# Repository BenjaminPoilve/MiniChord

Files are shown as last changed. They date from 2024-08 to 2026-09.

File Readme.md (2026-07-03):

# minichord 

This repository contains the source file both for the minichord itself and its documentation. 

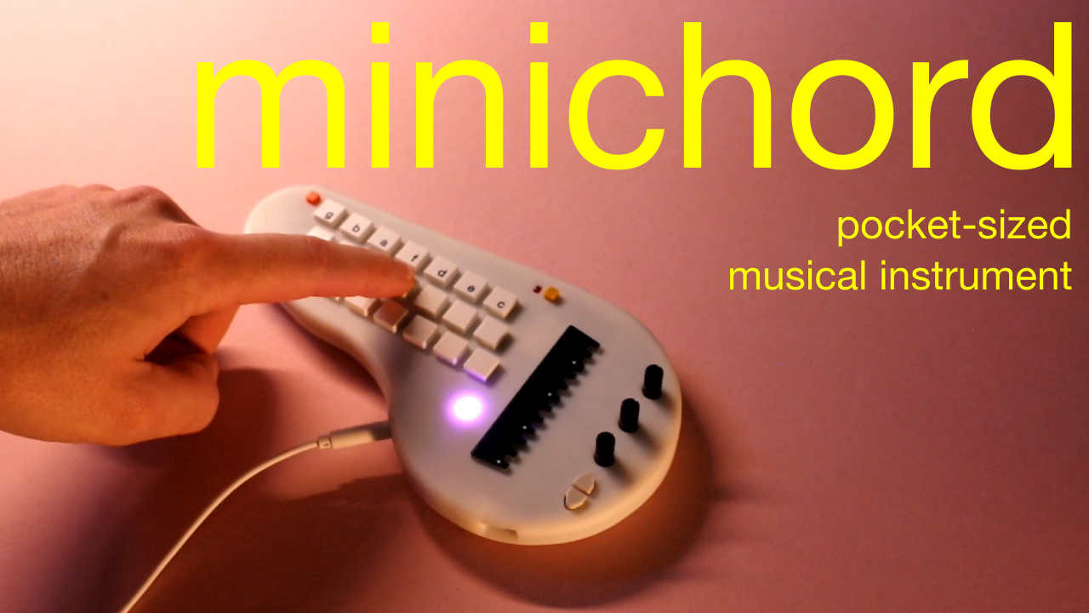
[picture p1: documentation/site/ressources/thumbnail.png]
Watch the video (https://www.youtube.com/watch?v=66Gu4NNnHgA)


To discuss the state of the project, features or share music, please head to the [minichord forum](https://minichord.discourse.group/categories).

## Documentation 

The best way to get to know this project is to visit the [minichord website](https://minichord.com/) which contains the documentation of the project. 

In particular it contains:

- the [user manual of the minichord](https://minichord.com/user_manual/)
- the [assembly guide of the minichord](https://minichord.com/assembly/)

This documentation is build with mkdocs and the relevant source and build script is available in the [documentation folder](https://github.com/BenjaminPoilve/MiniChord/tree/main/documentation).

## Hardware 

The hardware folder contains the necessary ressources to build a minichord. 

All hardware is provided under a Creative Commons Attribution-NonCommercial 4.0 International Public
License (CC BY-NC 4.0). 

In particular it contains: 

- the [files necessary to manufacture the PCB](https://github.com/BenjaminPoilve/MiniChord/tree/main/hardware/PCB)
- the [full BOM of the project](https://github.com/BenjaminPoilve/MiniChord/tree/main/hardware/BOM)
- the [3D enclosure files](https://github.com/BenjaminPoilve/MiniChord/tree/main/hardware/3D/rendering)
- the [keycap routing files](https://github.com/BenjaminPoilve/MiniChord/tree/main/hardware/graphics)

## Firmware 

The firmware folder contains the project firmware and necessary programming ressources.

All software is provided under a 3-clause BSD License.

In particular it contains: 
- the [Hex firmware](https://github.com/BenjaminPoilve/MiniChord/blob/main/firmware/firmware.hex)
- the full [PlatformIO project](https://github.com/BenjaminPoilve/MiniChord/tree/main/firmware)
- the [minicontrol software](https://github.com/BenjaminPoilve/MiniChord/tree/main/firmware/minicontrol)

## Alternative control platforms

Minichord users have developed some very cool alternative platforms that interface with the minichord. 
- the [minichord Sound Lab](https://minichorddrawn.github.io/minichord-soundlab/#play)
- [Keyandcableco's minicontrol](https://keyandcableco.github.io/minicontrol/)

Make sure to test them as they offer many alternative features!

## Media 

Here is a list of available media related to the project (to be completed) :

- a technical video about [the minicontrol system](https://www.youtube.com/watch?v=h-6qkhU_WoA&t=933s)
- a short [audio demo of selected presets](https://minichord.com/ressources/audio_demo.mp3)
- a [review of the project by Hainbach](https://www.youtube.com/watch?v=zQC3umGRGbM)
- an [interview I gave for the launch of the project with SeeedStudio](https://www.youtube.com/watch?v=swZKdO71dLo)
- a [folder of videos from minichord users](https://github.com/BenjaminPoilve/minichord/tree/main/documentation/docs/ressources/video) 

## Contact 

For any information about the project, don't hesitate to write at info@minichord.com

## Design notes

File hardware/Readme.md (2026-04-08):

# Hardware  

This folder contains the necessary ressources to build a minichord. 

### Electronics

* [Main PCB schematics](https://github.com/BenjaminPoilve/MiniChord/blob/main/hardware/PCB/miniChord_main_PCB/MiniChord.pdf)
* [Main PCB Gerber file](https://github.com/BenjaminPoilve/MiniChord/tree/main/hardware/PCB/miniChord_main_PCB/gerber)
* [Touch zone PCB Gerber file](https://github.com/BenjaminPoilve/minichord/tree/main/hardware/PCB/touch%20zones/default%20touch%20PCB/gerber)
* [Template for custom touch zone](https://github.com/BenjaminPoilve/minichord/tree/main/hardware/PCB/touch%20zones/touch%20kicad%20template)

### BOM

* [Full BOM](https://github.com/BenjaminPoilve/MiniChord/blob/main/hardware/BOM/full_BOM.pdf)

### 3D files

* [Bottom shell](https://github.com/BenjaminPoilve/minichord/blob/main/hardware/3D/rendering/render_v11_bottom.step) 
* [Top shell](https://github.com/BenjaminPoilve/minichord/blob/main/hardware/3D/rendering/render_v11_top.step)

### 2D files 

* [Key engraving](https://github.com/BenjaminPoilve/MiniChord/blob/main/hardware/graphics/key_engraving.svg)

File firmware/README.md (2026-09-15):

# Firmware 

Note to reader: a lot of this firmware has been developed in 45-minute time increment after a day's work, which in part explains that the code quality is not great. Refactoring and making the code cleaner will be a future focus. 

If you are an experimented C/C++ dev, and you whish to help on this project, I might be able to send you pre-production sample of the minichord in exchange for a bit of help. Don't hesitate to reach out to minichord@benjaminpoilve.com .

### Structure 

This folder contains a PlatformIO project for Teensy 4.0. 

In particular the it contains :

- the `src`folder containing the `main.cpp` file, as well as the file defining the USB name of the device, `name.c`
- the `lib` folder containing the librairies for the chips used, the debouncing and the potentiometer logic 
- the `include` folder containing all the Teensy audio architecture definition, as well as the hardware definitions and the `sysex_handler.h`file. 

The next interesting folder is related to the "generator". To be able to simply modify parameters related to sound synthesis and have a coherent firmware and control software, those parameters are defined in a [parameters.json file](https://github.com/BenjaminPoilve/MiniChord/blob/main/firmware/generator/parameters.json). By using the generation script, both the interface and necessary firmware file are generated. Note that the interface will be included in the minichord website by using the `build_site.sh` script in the documentation folder. 

The resulting fimware itself is present at the root of the project : [firmware.hex](https://github.com/BenjaminPoilve/MiniChord/blob/main/firmware/firmware.hex).

### Usage 

If you want to set-up a PlatformIO environnement for Teensy, please follow the tutorial for PlatformIO Teensy usage [available here](https://forum.pjrc.com/index.php?threads/tutorial-how-to-use-platformio-visual-code-studio-for-teensy.66674/)

Once the project is set-up, you can modify, compile and upload the code directly from VSCode. 

To use the generator, set-up a venv in the generator directory using `python3 -m venv .venv`. Then enter the venv by using `source venv/bin/activate`. 

Once in the venv, install the necessary packages by using `pip3 install -r requirements.txt`. 

Generation can then simply be done by running the `generate.py`script: `python3 generate.py`.

### USB descriptor customisation

The device uses the stock `USB_MIDI16_AUDIO_SERIAL` USB type of the Teensy core, with two changes: it advertises 2 MIDI cables instead of 16, and it reports `minichord` as manufacturer and product name.

The USB audio recording tap in `include/audio_definition.h` is guarded by `#ifdef AUDIO_INTERFACE`, so building against a USB type without audio interfaces still works without further edits.

Both are done from within the project, so no file of the `framework-arduinoteensy` package has to be touched:

- the names are set in [src/name.c](src/name.c), which overrides the (weakly defined) `usb_string_manufacturer_name` and `usb_string_product_name` descriptors of the core;
- the cable count is set in [include/usb_desc_override.h](include/usb_desc_override.h), which `platformio.ini` force-includes in front of every translation unit with `-include`. Because the core's `usb_desc.h` uses `#pragma once`, reading it from that header first means the core sources later get a no-op include and keep our value of `MIDI_NUM_CABLES`.

Earlier versions of this project instead asked for a manual edit of `usb_desc.h` in `~/.platformio/packages/framework-arduinoteensy/cores/teensy4`. That is no longer needed, and if you patched that file previously you can restore it to its original content.

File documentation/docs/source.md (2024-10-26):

# **Software** 

> All software is provided under a 3-clause BSD License

* [minicontrol software](https://github.com/BenjaminPoilve/MiniChord/tree/main/firmware/minicontrol)
* [Hex firmware](https://github.com/BenjaminPoilve/MiniChord/blob/main/firmware/firmware.hex)
* [PlatformIO project](https://github.com/BenjaminPoilve/MiniChord/tree/main/firmware)
* [Tutorial for PlatformIO Teensy usage](https://forum.pjrc.com/index.php?threads/tutorial-how-to-use-platformio-visual-code-studio-for-teensy.66674/)

<hr>

# **Hardware**

> All hardware is provided under a Creative Commons Attribution-NonCommercial 4.0 International Public
License (CC BY-NC 4.0)

## 3D files

* [Bottom shell](https://github.com/BenjaminPoilve/MiniChord/blob/main/hardware/3D/rendering/render_v9_bottom.scad.stl) 
* [Top shell](https://github.com/BenjaminPoilve/MiniChord/blob/main/hardware/3D/rendering/render_v9_top1_5.scad.stl)

## 2D files 

* [Key engraving](https://github.com/BenjaminPoilve/MiniChord/blob/main/hardware/graphics/key_engraving.svg)

## Electronics

* [Full BOM](https://github.com/BenjaminPoilve/MiniChord/blob/main/hardware/BOM/full_BOM.pdf)
* [Main PCB schematics](https://github.com/BenjaminPoilve/MiniChord/blob/main/hardware/PCB/miniChord_main_PCB/MiniChord.pdf)
* [Main PCB Gerber file](https://github.com/BenjaminPoilve/MiniChord/tree/main/hardware/PCB/miniChord_main_PCB/gerber)
* [Touch zone PCB schematics](https://github.com/BenjaminPoilve/MiniChord/blob/main/hardware/PCB/additional%20PCB/touch_zone.pdf)
* [Touch zone PCB Gerber file](https://github.com/BenjaminPoilve/MiniChord/tree/main/hardware/PCB/additional%20PCB/gerber)

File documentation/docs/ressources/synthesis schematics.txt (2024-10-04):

                                                                                            
 Harp section                         ┌ ─ ─ ─ ─ ─ ─ ─ ─ ─ ─ ─ ─ ─ ─ ─ ─ ─ ─ ─ ─ ─ ─ ─ ─ ─ ─ ─ ─
                                     ┌────────────────────────────────────────────────────────┐│ x12
                                    ┌┴───────────────────────────────────────────────────────┐│
┌─────────┐                         │┌────────────────┐                                      │││
│DC signal├────────────────────────▶││filter enveloppe│──────────┐          ┌───────────────┐││
└─────────┘                         │└────────────────┘          └─────────▶│low-pass filter│││├───┐
┌───────────┐   ┌────────────────┐  │┌─────────────────────┐  ┌────────┐ ┌─▶│               │││    │
│vibrato OSC├──▶│vibrato envelope├┬▶││modulated string OSC ├─▶│envelope├─┘  └───────────────┘││┘   │
└───────────┘   └────────────────┘│ │└─────────────────────┘  └────────┘                     ├┘    │
                                  │ └────────────────────────────────────────────────────────┘     │
┌───────────┐   ┌────────────────┐│     
│  bend DC  ├──▶│  bend envelope ├┘  
└───────────┘   └────────────────┘  
                                                                                                   │
┌──────────────────────────────────────────────────────────────────────────────────────────────────┘
│  ┌──────────┐  ┌─────────────┐  ┌─────────────┐  ┌─────┐  ┌────────────┐      ┌──────────┐
├─▶│waveshaper├─▶│ waveshaper  ├┬▶│  delay mix  ├─▶│delay├─▶│filter delay├─┬───▶│effect mix├───────┐
│  └──────────┘  │     mix     ││ │             │  └─────┘  └────────────┘ │ ┌─▶│          │       │
└───────────────▶│             ││ │             │                          │ │  └──────────┘       │
                 └─────────────┘│ └─────────────┘                          │ │                     │
                                │        ▲                                 │ │                     │
                                │        └─────────────────────────────────┘ │                     │
                                └────────────────────────────────────────────┘                     │
┌──────────────────────────────────────────────────────────────────────────────────────────────────┘
│              ┌──────────┐              ┌─────────────┐  ┌──────┐  ┌──────────┐
└─────────────▶│multiplier├─────────────▶│output filter├┬▶│reverb├─▶│reverb mix├─▶ output
┌───────────┐  │          │┌──────────┐  │             ││ └──────┘  │          │
│tremolo OSC├─▶│          ││filter OSC├─▶│             │└──────────▶│          │
└───────────┘  └──────────┘└──────────┘  └─────────────┘            └──────────┘

 Chord section     ┌──────────────────────────────────────────────────────────────────────┐
                  ┌┴─────────────────────────────────────────────────────────────────────┐│ x4
                 ┌┴─────────────────────────────────────────────────────────────────────┐││
                ┌┴─────────────────────────────────────────────────────────────────────┐│││
┌───────────┐   │┌────────────────┐  ┌───────────────┐  ┌─────┐  ┌──────┐  ┌──────────┐││││
│vibrato OSC├─▶ ││vibrato envelope├┬▶│modulated OSC 1├─▶│ mix ├─▶│filter├─▶│multiplier│││││
└───────────┘   │└────────────────┘│ ├───────────────┤  │     │  └──────┘  └──────────┘││││
┌───────────┐   │┌────────────────┐├▶│modulated OSC 2├─▶│     │     ▲           ▲      ││││
│  bend DC  ├─▶ ││vibrato envelope├│ ├───────────────┤  │     │     │           │      ││││────────┐
└───────────┘   │└────────────────┘└▶│modulated OSC 3├─▶│     │     │           │      ││││        │
                │                    └─────────┬─────┤  │     │     │           │      ││││        │
                │                              │noise├─▶│     │     │           │      ││││        │
┌──────────┐    │┌───────────────┐             └─────┘  └─────┘     │           │      ││││        │
│filter OSC├──▶ ││filter envelope├──────────────────────────────────┘           │      ││││        │
└──────────┘    │└───────────────┘                                              │      ││││        │
┌───────────┐   │┌────────────────┐                                             │      ││├┘        │
│tremolo OSC├─▶ ││tremolo envelope├─────────────────────────────────────────────┘      │├┘         │
└───────────┘   │└────────────────┘                                                    ├┘          │
                └──────────────────────────────────────────────────────────────────────┘           │
                                                                                                   │
┌──────────────────────────────────────────────────────────────────────────────────────────────────┘
│  ┌──────────┐  ┌─────────────┐  ┌─────────────┐  ┌─────┐  ┌────────────┐      ┌──────────┐
├─▶│waveshaper├─▶│ waveshaper  ├┬▶│  delay mix  ├─▶│delay├─▶│filter delay├─┬───▶│effect mix├───────┐
│  └──────────┘  │     mix     ││ │             │  └─────┘  └────────────┘ │ ┌─▶│          │       │
└───────────────▶│             ││ │             │                          │ │  └──────────┘       │
                 └─────────────┘│ └─────────────┘                          │ │                     │
                                │        ▲                                 │ │                     │
                                │        └─────────────────────────────────┘ │                     │
                                └────────────────────────────────────────────┘                     │
┌──────────────────────────────────────────────────────────────────────────────────────────────────┘
│  ┌─────────────┐  ┌──────┐  ┌──────────┐
└─▶│output filter├┬▶│reverb├─▶│reverb mix├─▶ output
   │             ││ └──────┘  │          │
   │             │└──────────▶│          │
   └─────────────┘            └──────────┘

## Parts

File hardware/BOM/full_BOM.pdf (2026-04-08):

### Full BOM

Quantity | Part | Type | Link
2 | 1608 10uf capacitor | SMD component
3 | 2012 2.2uf capacitor | SMD component
1 | 6.3x5.7 100uf capacitor | SMD component
1 | 3216 100uf capacitor | SMD component
8 | 1608 100nf capacitor | SMD component
1 | 4x5.4 10uf capacitor | SMD component
2 | 1608 2.2nf capacitor | SMD component
1 | 2012 4.7uf capacitor | SMD component
1 | side mount bicolour led | SMD component
1 | SWPA60 6.8uH inductor | SMD component
1 | 2012 1k resistor | SMD component
1 | 1608 330k resistor | SMD component
1 | 2012 680 resistor | SMD component
2 | 1608 1.8M resistor | SMD component
1 | 1608 220k resistor | SMD component
1 | 1608 1M resistor | SMD component
1 | 2012 2k resistor | SMD component
2 | 2012 2k2 resistor | SMD component
8 | 2012 10k resistor | SMD component
1 | 1608 75k resistor | SMD component
4 | 1608 22 resistor | SMD component
1 | 1608 560 resistor | SMD component
1 | 1608 100 resistor | SMD component
1 | 1608 200 resistor | SMD component
3 | 1608 470 resistor | SMD component
1 | PVQFN TPS61090 | SMD component
1 | SOT-23 MCP73831 | SMD component
1 | SOIC-16 74HC595 | SMD component
1 | TSSOP-20 PCM5102 | SMD component
1 | UQFN-20 MPR121QR2 | SMD component
8 | 1N4148WT | SMD component
1 | Red LED | TH component | Mouser (https://www.mouser.fr/ProductDetail/604-WP169XID)
1 | 5mm RKGB LED | TH component | -
1 | Switched Audio Jack | TH component | Mouser (https://www.mouser.fr/ProductDetail/490-SJ-3566AN)
1 | JST PH 2mm 2pin male angled | TH component | -
1 | 503450 1000mAh battery | other hardware | -
3 | Potentiometer | TH component | Mouser (https://www.mouser.fr/ProductDetail/317-2090F-100K) (note: if we could source a RV09AF-40-15K-B100K instead, it would be better)
4 | Tactile switch 6x6mm | TH component | Mouser (https://www.mouser.fr/ProductDetail/653-B3F-1050)
21 | Tactile switch 12x12mm | TH component | Mouser (https://www.mouser.fr/ProductDetail/653-B3F-4050)
2 | Touch header female | TH component | Mouser (https://www.mouser.fr/ProductDetail/855-M20-7810345R)
2 | Touch header male | TH component | Mouser (https://www.mouser.fr/ProductDetail/855-M20-8760346)
1 | Teensy 4.0 | TH component | PJRC (https://www.pjrc.com/store/teensy40.html)
1 | Teensy headers | TH component | Mouser (https://www.mouser.fr/ProductDetail/Samtec/TSW-132-06-T-S?qs=rU5fayqh%252BE1E2ITYQW/0SQ==)
21 | Tactile switch keycap 9x9 | other hardware | Mouser (https://www.mouser.fr/ProductDetail/653-B32-1260)
2 | Tactile switch keycap key top | other hardware | Mouser (https://www.mouser.fr/ProductDetail/653-B322100)
1 | Tactile switch keycap 4x4 orange | other hardware | Mouser (https://www.mouser.fr/ProductDetail/653-B32-1020)

1

Quantity | Part | Type | Link
1 | Tactile switch keycap 4x4 yellow | other hardware | Mouser (https://www.mouser.fr/ProductDetail/653-B32-1030)
1 | Top shell | other hardware | -
1 | Bottom shell | other hardware | -
1 | Double sided tape | other hardware | -
6 | M2.3x8 self taping screws | other hardware | -
3 | M2.3x6 self taping screws | other hardware | -

2

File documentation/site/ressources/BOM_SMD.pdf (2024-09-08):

### Table 1

ID | Value | Footprint | Quantity
> C1, C2 | 10uf | 1608Metric | 2
> C4, C9, C10 | 2.2uf | 2012Metric | 3
C5 | 100uf | Elec_6.3x5.7 | 1
C6 | 100uf | 3216Metric | 1
> C3, C7, C8, C11-C14, C19 | 100n | 1608Metric | 8
C15 | 10uf | Elec_4x5.4 | 1
> C16, C17 | 2.2nf | 1608Metric | 2
C18 | 4.7uf | 2012Metric | 1
D3 | LED_Dual_AAKK | side led | 1
L1 | 6.8uH | SWPA60xxS | 1
R1 | 1k | 2012Metric | 1
R3 | 330k | 1608Metric | 1
R4 | 680 | 2012Metric | 1
> R2, R5 | 1.8M | 1608Metric | 2
R6 | 220k | 1608Metric | 1
R7 | 1M | 1608Metric | 1
R8 | 2k | 2012Metric | 1
> R9, R10 | 2k2 | 2012Metric | 2
> R11-R14, R16, R38-R40 | 10k | 2012Metric | 8
R15 | 75k | 1608Metric | 1
> R27-R30 | 22 | 1608Metric | 4
R34 | 560 | 1608Metric | 1
R35 | 100 | 1608Metric | 1
R36 | 200 | 1608Metric | 1
> R31, R32, R37 | 470 | 1608Metric | 3
U2 | TPS61090 | PVQFN-N16_EP2.7x2.7mm | 1
U3 | MCP73831-2-OT | SOT-23-5 | 1
U4 | 74HC595 | SOIC-16_3.9x9.9m m_P1.27mm | 1
U5 | PCM5102 | TSSOP-20_4.4x6.5 mm_P0.65mm | 1
U6 | MPR121QR2 | UQFN-20_3x3mm_ P0.4mm | 1

1

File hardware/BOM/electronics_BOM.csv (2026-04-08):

Reference | Value | Link | Footprint | Qty | DNP | Description
C1 | 10uf | https://www.lcsc.com/product-detail/Multilayer-Ceramic-Capacitors-MLCC-SMD-SMT_Samsung-Electro-Mechanics-CL10A106MA8NRNC_C96446.html | Capacitor_SMD:C_0603_1608Metric | 1
C2 | 10uf | https://www.lcsc.com/product-detail/Multilayer-Ceramic-Capacitors-MLCC-SMD-SMT_Samsung-Electro-Mechanics-CL10A106MA8NRNC_C96446.html | Capacitor_SMD:C_0603_1608Metric | 1
C3 | 100n | https://www.lcsc.com/product-detail/Multilayer-Ceramic-Capacitors-MLCC-SMD-SMT_YAGEO-CC0603KRX7R9BB104_C14663.html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 | Capacitor_SMD:C_0603_1608Metric | 1
C4 | 2.2uf | https://www.lcsc.com/product-detail/Multilayer-Ceramic-Capacitors-MLCC-SMD-SMT_Samsung-Electro-Mechanics-CL21A225KBQNNNE_C377773.html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 | Capacitor_SMD:C_0805_2012Metric | 1
C5 | 100uf | https://www.lcsc.com/product-detail/Aluminum-Electrolytic-Capacitors-SMD_Capxon-International-Elec-HV101M6R3E055ETR_C65235.html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 | Capacitor_SMD:CP_Elec_6.3x5.7 | 1
C6 | 100uf | https://www.lcsc.com/product-detail/Multilayer-Ceramic-Capacitors-MLCC-SMD-SMT_Samsung-Electro-Mechanics-CL31A107MQHNNNE_C15008.html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 | Capacitor_SMD:C_1206_3216Metric | 1
C7 | 100n | https://www.lcsc.com/product-detail/Multilayer-Ceramic-Capacitors-MLCC-SMD-SMT_YAGEO-CC0603KRX7R9BB104_C14663.html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 | Capacitor_SMD:C_0603_1608Metric | 1
C8 | 100n | https://www.lcsc.com/product-detail/Multilayer-Ceramic-Capacitors-MLCC-SMD-SMT_YAGEO-CC0603KRX7R9BB104_C14663.html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 | Capacitor_SMD:C_0603_1608Metric | 1
C9 | 2.2uf | https://www.lcsc.com/product-detail/Multilayer-Ceramic-Capacitors-MLCC-SMD-SMT_Samsung-Electro-Mechanics-CL21A225KBQNNNE_C377773.html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 | Capacitor_SMD:C_0805_2012Metric | 1
C10 | 2.2uf | https://www.lcsc.com/product-detail/Multilayer-Ceramic-Capacitors-MLCC-SMD-SMT_Samsung-Electro-Mechanics-CL21A225KBQNNNE_C377773.html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 | Capacitor_SMD:C_0805_2012Metric | 1
C11 | 100n | https://www.lcsc.com/product-detail/Multilayer-Ceramic-Capacitors-MLCC-SMD-SMT_YAGEO-CC0603KRX7R9BB104_C14663.html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 | Capacitor_SMD:C_0603_1608Metric | 1
C12 | 100n | https://www.lcsc.com/product-detail/Multilayer-Ceramic-Capacitors-MLCC-SMD-SMT_YAGEO-CC0603KRX7R9BB104_C14663.html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 | Capacitor_SMD:C_0603_1608Metric | 1
C13 | 100n | https://www.lcsc.com/product-detail/Multilayer-Ceramic-Capacitors-MLCC-SMD-SMT_YAGEO-CC0603KRX7R9BB104_C14663.html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 | Capacitor_SMD:C_0603_1608Metric | 1
C14 | 100n | https://www.lcsc.com/product-detail/Multilayer-Ceramic-Capacitors-MLCC-SMD-SMT_YAGEO-CC0603KRX7R9BB104_C14663.html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 | Capacitor_SMD:C_0603_1608Metric | 1
C15 | 10uf | https://www.lcsc.com/product-detail/Aluminum-Electrolytic-Capacitors-SMD_KNSCHA-126RV0157_C7461288.html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 | Capacitor_SMD:CP_Elec_4x5.4 | 1
C16 | 2.2nf | https://www.lcsc.com/product-detail/Multilayer-Ceramic-Capacitors-MLCC-SMD-SMT_FH-Guangdong-Fenghua-Advanced-Tech-0603B222K500NT_C1604.html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 | Capacitor_SMD:C_0603_1608Metric | 1
C17 | 2.2nf | https://www.lcsc.com/product-detail/Multilayer-Ceramic-Capacitors-MLCC-SMD-SMT_FH-Guangdong-Fenghua-Advanced-Tech-0603B222K500NT_C1604.html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 | Capacitor_SMD:C_0603_1608Metric | 1
C18 | 4.7uf | https://www.lcsc.com/product-detail/Multilayer-Ceramic-Capacitors-MLCC-SMD-SMT_Samsung-Electro-Mechanics-CL21A475KAQNNNE_C1779.html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 | Capacitor_SMD:C_0805_2012Metric | 1
C19 | 100n | https://www.lcsc.com/product-detail/Multilayer-Ceramic-Capacitors-MLCC-SMD-SMT_YAGEO-CC0603KRX7R9BB104_C14663.html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 | Capacitor_SMD:C_0603_1608Metric | 1
D1 | LED | https://www.mouser.fr/ProductDetail/Kingbright/WP169XID?qs=DkZGzo4b%252BTI3yOiggkw3fg%3D%3D | Personnal_Library:WP169XID | 1
D2 | LED_RKGB | https://fr.aliexpress.com/item/1005004567358995.html | Personnal_Library:LED_D5.0mm-4_RGB-cutout | 1
D3 | LED_Dual_AAKK | https://www.lcsc.com/product-detail/LED-Indication-Discrete_Amicc-A-SP1102AR6GHC-A01-2C_C5160724.html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 | Personnal_Library:R_G side led | 1
D4 | 1N4148WT | https://www.lcsc.com/product-detail/Switching-Diodes_hongjiacheng-1N4148WT_C7420320.html?s_z=n_C7420320 | Diode_SMD:D_SOD-523 | 1
D5 | 1N4148WT | https://www.lcsc.com/product-detail/Switching-Diodes_hongjiacheng-1N4148WT_C7420320.html?s_z=n_C7420320 | Diode_SMD:D_SOD-523 | 1
D6 | 1N4148WT | https://www.lcsc.com/product-detail/Switching-Diodes_hongjiacheng-1N4148WT_C7420320.html?s_z=n_C7420320 | Diode_SMD:D_SOD-523 | 1
D7 | 1N4148WT | https://www.lcsc.com/product-detail/Switching-Diodes_hongjiacheng-1N4148WT_C7420320.html?s_z=n_C7420320 | Diode_SMD:D_SOD-523 | 1
D8 | 1N4148WT | https://www.lcsc.com/product-detail/Switching-Diodes_hongjiacheng-1N4148WT_C7420320.html?s_z=n_C7420320 | Diode_SMD:D_SOD-523 | 1
D9 | 1N4148WT | https://www.lcsc.com/product-detail/Switching-Diodes_hongjiacheng-1N4148WT_C7420320.html?s_z=n_C7420320 | Diode_SMD:D_SOD-523 | 1
D10 | 1N4148WT | https://www.lcsc.com/product-detail/Switching-Diodes_hongjiacheng-1N4148WT_C7420320.html?s_z=n_C7420320 | Diode_SMD:D_SOD-523 | 1
D11 | 1N4148WT | https://www.lcsc.com/product-detail/Switching-Diodes_hongjiacheng-1N4148WT_C7420320.html?s_z=n_C7420320 | Diode_SMD:D_SOD-523 | 1
J1 | Conn_02x03_Top_Bottom | https://www.mouser.fr/ProductDetail/Harwin/M20-7810345R?qs=k41KVqW3ymoME5l5QJ2Feg%3D%3D | Personnal_Library:03x02 bottom entry header | 1
J2 | AudioJack_switched | https://www.mouser.fr/ProductDetail/Same-Sky/SJ-3566AN?qs=WyjlAZoYn52HouuVvH6sjg%3D%3D | Personnal_Library:Switched Jack PJ307_3525 | 1
J3 | Conn_01x02 | https://www.lcsc.com/product-detail/Wire-To-Board-Connector_JST-S2B-PH-K-S-LF-SN_C173752.html?s_z=n_JST%20PH | Connector_JST:JST_PH_S2B-PH-K_1x02_P2.00mm_Horizontal | 1
J4 | Conn_02x03_Top_Bottom | https://www.mouser.fr/ProductDetail/Harwin/M20-7810345R?qs=k41KVqW3ymoME5l5QJ2Feg%3D%3D | Personnal_Library:03x02 bottom entry header | 1
L1 | 6.8uH | https://www.digikey.fr/en/products/detail/shenzhen-sunlord-electronics-co-ltd/SWPA6045S6R8MT/14119994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 | Inductor_SMD:L_Sunlord_SWPA60xxS | 1
R1 | 1k | https://www.lcsc.com/product-detail/Chip-Resistor-Surface-Mount_UNI-ROYAL-Uniroyal-Elec-0805W8F1001T5E_C17513.html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 | Resistor_SMD:R_0805_2012Metric | 1
R2 | 1.8M | https://www.lcsc.com/product-detail/Chip-Resistor-Surface-Mount_FOJAN-FRC0603F1804TS_C2933162.html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 | Resistor_SMD:R_0603_1608Metric | 1
R3 | 330k | https://www.lcsc.com/product-detail/Chip-Resistor-Surface-Mount_UNI-ROYAL-Uniroyal-Elec-0603WAF3303T5E_C23137.html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 | Resistor_SMD:R_0603_1608Metric | 1
R4 | 680 | https://www.lcsc.com/product-detail/Chip-Resistor-Surface-Mount_UNI-ROYAL-Uniroyal-Elec-0805W8F6800T5E_C17798.html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 | Resistor_SMD:R_0805_2012Metric | 1
R5 | 1.8M | https://www.lcsc.com/product-detail/Chip-Resistor-Surface-Mount_FOJAN-FRC0603F1804TS_C2933162.html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 | Resistor_SMD:R_0603_1608Metric | 1
R6 | 220k | https://www.lcsc.com/product-detail/Chip-Resistor-Surface-Mount_UNI-ROYAL-Uniroyal-Elec-0603WAF2203T5E_C22961.html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 | Resistor_SMD:R_0603_1608Metric | 1
R7 | 1M | https://www.lcsc.com/product-detail/Chip-Resistor-Surface-Mount_UNI-ROYAL-Uniroyal-Elec-0603WAF1004T5E_C22935.html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 | Resistor_SMD:R_0603_1608Metric | 1
R8 | 2k | https://www.lcsc.com/product-detail/Chip-Resistor-Surface-Mount_UNI-ROYAL-Uniroyal-Elec-0805W8F2001T5E_C17604.html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 | Resistor_SMD:R_0805_2012Metric | 1
R9 | 2k2 | https://www.lcsc.com/product-detail/Chip-Resistor-Surface-Mount_UNI-ROYAL-Uniroyal-Elec-0805W8F2201T5E_C17520.html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 | Resistor_SMD:R_0805_2012Metric | 1
R10 | 2k2 | https://www.lcsc.com/product-detail/Chip-Resistor-Surface-Mount_UNI-ROYAL-Uniroyal-Elec-0805W8F2201T5E_C17520.html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 | Resistor_SMD:R_0805_2012Metric | 1
R11 | 10k | https://www.lcsc.com/product-detail/Chip-Resistor-Surface-Mount_UNI-ROYAL-Uniroyal-Elec-0805W8F1002T5E_C17414.html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 | Resistor_SMD:R_0805_2012Metric | 1
R12 | 10k | https://www.lcsc.com/product-detail/Chip-Resistor-Surface-Mount_UNI-ROYAL-Uniroyal-Elec-0805W8F1002T5E_C17414.html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 | Resistor_SMD:R_0805_2012Metric | 1
R13 | 10k | https://www.lcsc.com/product-detail/Chip-Resistor-Surface-Mount_UNI-ROYAL-Uniroyal-Elec-0805W8F1002T5E_C17414.html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 | Resistor_SMD:R_0805_2012Metric | 1
R14 | 10k | https://www.lcsc.com/product-detail/Chip-Resistor-Surface-Mount_UNI-ROYAL-Uniroyal-Elec-0805W8F1002T5E_C17414.html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 | Resistor_SMD:R_0805_2012Metric | 1
R15 | 75k | https://www.lcsc.com/product-detail/Chip-Resistor-Surface-Mount_UNI-ROYAL-Uniroyal-Elec-0603WAF7502T5E_C23242.html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 | Resistor_SMD:R_0603_1608Metric | 1
R16 | 10k | https://www.lcsc.com/product-detail/Chip-Resistor-Surface-Mount_UNI-ROYAL-Uniroyal-Elec-0805W8F1002T5E_C17414.html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 | Resistor_SMD:R_0805_2012Metric | 1
R27 | 22 | https://www.lcsc.com/product-detail/Chip-Resistor-Surface-Mount_UNI-ROYAL-Uniroyal-Elec-0603WAF220JT5E_C23345.html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 | Resistor_SMD:R_0603_1608Metric | 1
R28 | 22 | https://www.lcsc.com/product-detail/Chip-Resistor-Surface-Mount_UNI-ROYAL-Uniroyal-Elec-0603WAF220JT5E_C23345.html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 | Resistor_SMD:R_0603_1608Metric | 1
R29 | 22 | https://www.lcsc.com/product-detail/Chip-Resistor-Surface-Mount_UNI-ROYAL-Uniroyal-Elec-0603WAF220JT5E_C23345.html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 | Resistor_SMD:R_0603_1608Metric | 1
R30 | 22 | https://www.lcsc.com/product-detail/Chip-Resistor-Surface-Mount_UNI-ROYAL-Uniroyal-Elec-0603WAF220JT5E_C23345.html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 | Resistor_SMD:R_0603_1608Metric | 1
R31 | 470 | https://www.lcsc.com/product-detail/Chip-Resistor-Surface-Mount_UNI-ROYAL-Uniroyal-Elec-0603WAF4700T5E_C23179.html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 | Resistor_SMD:R_0603_1608Metric | 1
R32 | 470 | https://www.lcsc.com/product-detail/Chip-Resistor-Surface-Mount_UNI-ROYAL-Uniroyal-Elec-0603WAF4700T5E_C23179.html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 | Resistor_SMD:R_0603_1608Metric | 1
R34 | 560 | https://www.lcsc.com/product-detail/Chip-Resistor-Surface-Mount_UNI-ROYAL-Uniroyal-Elec-0603WAF5600T5E_C23204.html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 | Resistor_SMD:R_0603_1608Metric | 1
R35 | 100 | https://www.lcsc.com/product-detail/Chip-Resistor-Surface-Mount_UNI-ROYAL-Uniroyal-Elec-0603WAF1000T5E_C22775.html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 | Resistor_SMD:R_0603_1608Metric | 1
R36 | 200 | https://www.lcsc.com/product-detail/Chip-Resistor-Surface-Mount_UNI-ROYAL-Uniroyal-Elec-0603WAF2000T5E_C8218.html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 | Resistor_SMD:R_0603_1608Metric | 1
R37 | 470 | https://www.lcsc.com/product-detail/Chip-Resistor-Surface-Mount_UNI-ROYAL-Uniroyal-Elec-0603WAF4700T5E_C23179.html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 | Resistor_SMD:R_0603_1608Metric | 1
R38 | 10k | https://www.lcsc.com/product-detail/Chip-Resistor-Surface-Mount_UNI-ROYAL-Uniroyal-Elec-0805W8F1002T5E_C17414.html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 | Resistor_SMD:R_0805_2012Metric | 1
R39 | 10k | https://www.lcsc.com/product-detail/Chip-Resistor-Surface-Mount_UNI-ROYAL-Uniroyal-Elec-0805W8F1002T5E_C17414.html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 | Resistor_SMD:R_0805_2012Metric | 1
R40 | 10k | https://www.lcsc.com/product-detail/Chip-Resistor-Surface-Mount_UNI-ROYAL-Uniroyal-Elec-0805W8F1002T5E_C17414.html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 | Resistor_SMD:R_0805_2012Metric | 1
RV1 | 100k | https://www.mouser.fr/ProductDetail/Alpha-Taiwan/RV09AF-40-20K-B100K?qs=eadLBtAAYOcDATbz39dQgg%3D%3D | Personnal_Library:Alpha B100k_deep | 1
RV2 | 100k | https://www.mouser.fr/ProductDetail/Alpha-Taiwan/RV09AF-40-20K-B100K?qs=eadLBtAAYOcDATbz39dQgg%3D%3D | Personnal_Library:Alpha B100k_deep | 1
RV3 | 100k | https://www.mouser.fr/ProductDetail/Alpha-Taiwan/RV09AF-40-20K-B100K?qs=eadLBtAAYOcDATbz39dQgg%3D%3D | Personnal_Library:Alpha B100k_deep | 1
SW1 | SW_12mm | https://www.mouser.fr/ProductDetail/Omron-Electronics/B3F-4050?qs=B3tblJ0Nlt9ObBVoLmesBQ%3D%3D | Personnal_Library:OMRON B3F-40 | 1
SW2 | SW_12mm | https://www.mouser.fr/ProductDetail/Omron-Electronics/B3F-4050?qs=B3tblJ0Nlt9ObBVoLmesBQ%3D%3D | Personnal_Library:OMRON B3F-40 | 1
SW3 | SW_12mm | https://www.mouser.fr/ProductDetail/Omron-Electronics/B3F-4050?qs=B3tblJ0Nlt9ObBVoLmesBQ%3D%3D | Personnal_Library:OMRON B3F-40 | 1
SW4 | SW_12mm | https://www.mouser.fr/ProductDetail/Omron-Electronics/B3F-4050?qs=B3tblJ0Nlt9ObBVoLmesBQ%3D%3D | Personnal_Library:OMRON B3F-40 | 1
SW5 | SW_12mm | https://www.mouser.fr/ProductDetail/Omron-Electronics/B3F-4050?qs=B3tblJ0Nlt9ObBVoLmesBQ%3D%3D | Personnal_Library:OMRON B3F-40 | 1
SW6 | SW_12mm | https://www.mouser.fr/ProductDetail/Omron-Electronics/B3F-4050?qs=B3tblJ0Nlt9ObBVoLmesBQ%3D%3D | Personnal_Library:OMRON B3F-40 | 1
SW7 | SW_12mm | https://www.mouser.fr/ProductDetail/Omron-Electronics/B3F-4050?qs=B3tblJ0Nlt9ObBVoLmesBQ%3D%3D | Personnal_Library:OMRON B3F-40 | 1
SW8 | SW_12mm | https://www.mouser.fr/ProductDetail/Omron-Electronics/B3F-4050?qs=B3tblJ0Nlt9ObBVoLmesBQ%3D%3D | Personnal_Library:OMRON B3F-40 | 1
SW9 | SW_12mm | https://www.mouser.fr/ProductDetail/Omron-Electronics/B3F-4050?qs=B3tblJ0Nlt9ObBVoLmesBQ%3D%3D | Personnal_Library:OMRON B3F-40 | 1
SW10 | SW_12mm | https://www.mouser.fr/ProductDetail/Omron-Electronics/B3F-4050?qs=B3tblJ0Nlt9ObBVoLmesBQ%3D%3D | Personnal_Library:OMRON B3F-40 | 1
SW11 | SW_12mm | https://www.mouser.fr/ProductDetail/Omron-Electronics/B3F-4050?qs=B3tblJ0Nlt9ObBVoLmesBQ%3D%3D | Personnal_Library:OMRON B3F-40 | 1
SW12 | SW_12mm | https://www.mouser.fr/ProductDetail/Omron-Electronics/B3F-4050?qs=B3tblJ0Nlt9ObBVoLmesBQ%3D%3D | Personnal_Library:OMRON B3F-40 | 1
SW13 | SW_12mm | https://www.mouser.fr/ProductDetail/Omron-Electronics/B3F-4050?qs=B3tblJ0Nlt9ObBVoLmesBQ%3D%3D | Personnal_Library:OMRON B3F-40 | 1
SW14 | SW_12mm | https://www.mouser.fr/ProductDetail/Omron-Electronics/B3F-4050?qs=B3tblJ0Nlt9ObBVoLmesBQ%3D%3D | Personnal_Library:OMRON B3F-40 | 1
SW15 | SW_12mm | https://www.mouser.fr/ProductDetail/Omron-Electronics/B3F-4050?qs=B3tblJ0Nlt9ObBVoLmesBQ%3D%3D | Personnal_Library:OMRON B3F-40 | 1
SW16 | SW_12mm | https://www.mouser.fr/ProductDetail/Omron-Electronics/B3F-4050?qs=B3tblJ0Nlt9ObBVoLmesBQ%3D%3D | Personnal_Library:OMRON B3F-40 | 1
SW17 | SW_12mm | https://www.mouser.fr/ProductDetail/Omron-Electronics/B3F-4050?qs=B3tblJ0Nlt9ObBVoLmesBQ%3D%3D | Personnal_Library:OMRON B3F-40 | 1
SW18 | SW_12mm | https://www.mouser.fr/ProductDetail/Omron-Electronics/B3F-4050?qs=B3tblJ0Nlt9ObBVoLmesBQ%3D%3D | Personnal_Library:OMRON B3F-40 | 1
SW19 | SW_12mm | https://www.mouser.fr/ProductDetail/Omron-Electronics/B3F-4050?qs=B3tblJ0Nlt9ObBVoLmesBQ%3D%3D | Personnal_Library:OMRON B3F-40 | 1
SW20 | SW_12mm | https://www.mouser.fr/ProductDetail/Omron-Electronics/B3F-4050?qs=B3tblJ0Nlt9ObBVoLmesBQ%3D%3D | Personnal_Library:OMRON B3F-40 | 1
SW21 | SW_12mm | https://www.mouser.fr/ProductDetail/Omron-Electronics/B3F-4050?qs=B3tblJ0Nlt9ObBVoLmesBQ%3D%3D | Personnal_Library:OMRON B3F-40 | 1
SW22 | SW_6mm | https://www.mouser.fr/ProductDetail/Omron-Electronics/B3F-1050?qs=CX134%252BdLMDHtBADdp1bBBw%3D%3D | Personnal_Library:OMRON B3F-10 SQUARE
SW24 | SW_6mm | https://www.mouser.fr/ProductDetail/Omron-Electronics/B3F-1050?qs=CX134%252BdLMDHtBADdp1bBBw%3D%3D | Personnal_Library:OMRON B3F-10 ARROW | 1
SW25 | SW_6mm | https://www.mouser.fr/ProductDetail/Omron-Electronics/B3F-1050?qs=CX134%252BdLMDHtBADdp1bBBw%3D%3D | Personnal_Library:OMRON B3F-10 ARROW | 1
SW26 | SW_6mm | https://www.mouser.fr/ProductDetail/Omron-Electronics/B3F-1050?qs=CX134%252BdLMDHtBADdp1bBBw%3D%3D | Personnal_Library:OMRON B3F-10 SQUARE | 1
U1 | num | https://www.pjrc.com/store/teensy40.html | Personnal_Library:Teensy40_lite_back | 1
U2 | TPS61090 | https://www.lcsc.com/product-detail/DC-DC-Converters_Texas-Instruments-TPS61090RSAR_C206167.html?s_z=n_C206167 | Package_DFN_QFN:Texas_S-PVQFN-N16_EP2.7x2.7mm_ThermalVias | 1
U3 | MCP73831-2-OT | https://www.lcsc.com/product-detail/Battery-Management_Microchip-Tech-MCP73831T-2ACI-OT_C424093.html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 | Package_TO_SOT_SMD:SOT-23-5 | 1
U4 | 74HC595 | https://www.lcsc.com/product-detail/Shift-Registers_Nexperia-74HC595D-118_C5947.html?s_z=n_C5947 | Package_SO:SOIC-16_3.9x9.9mm_P1.27mm | 1
U5 | PCM5102 | https://www.lcsc.com/product-detail/ADCs-DACs-Special-Purpose_Texas-Instruments-PCM5102APWR_C107671.html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 | Package_SO:TSSOP-20_4.4x6.5mm_P0.65mm | 1
U6 | MPR121QR2 | https://www.lcsc.com/product-detail/Touch-Sensors_NXP-Semicon-MPR121QR2_C91322.html?s_z=n_C91322 | Package_DFN_QFN:UQFN-20_3x3mm_P0.4mm | 1

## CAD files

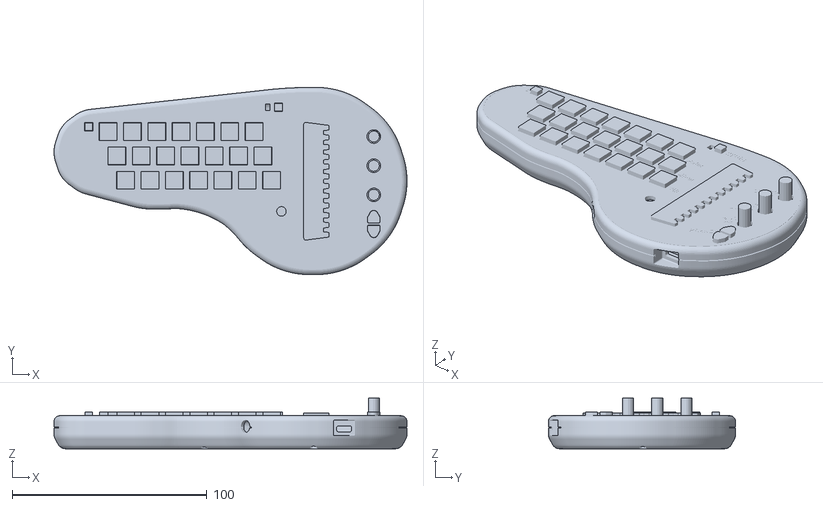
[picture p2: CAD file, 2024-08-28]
hardware/3D/rendering/full_3D_test.stl
181.4 x 96.2 x 26.0

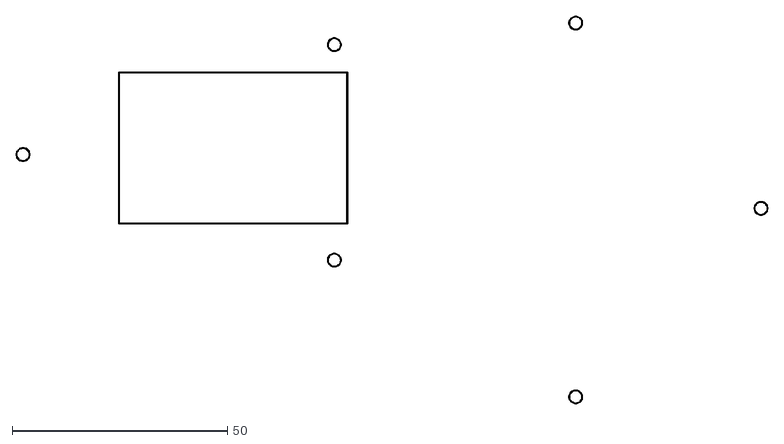
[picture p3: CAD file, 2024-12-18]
hardware/3D/DXF/battery.dxf
174.4 x 89.9

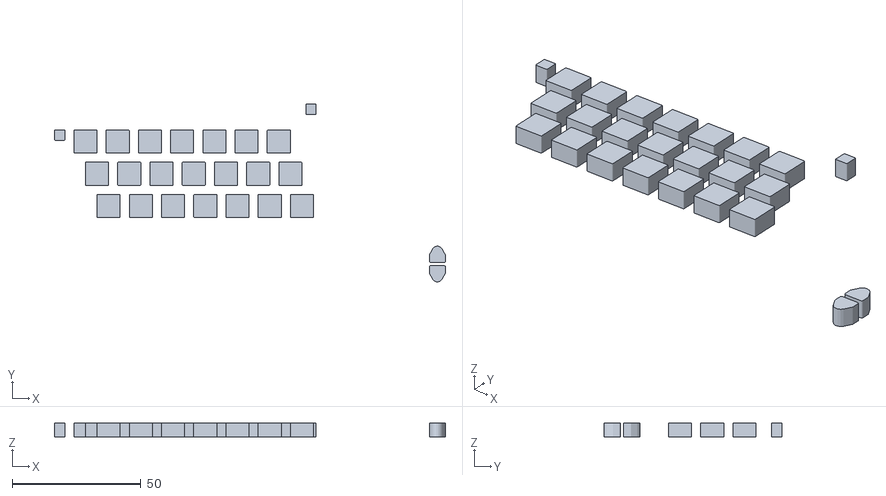
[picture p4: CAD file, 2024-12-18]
hardware/3D/rendering/buttons.stl
151.6 x 68.9 x 5.50

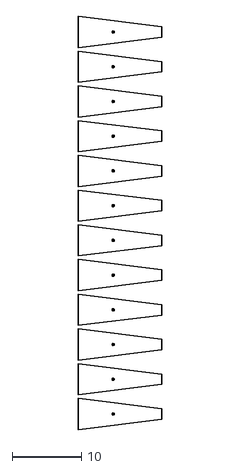
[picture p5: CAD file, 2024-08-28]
hardware/3D/DXF/touch_zone-F_Cu.dxf
12.0 x 59.5

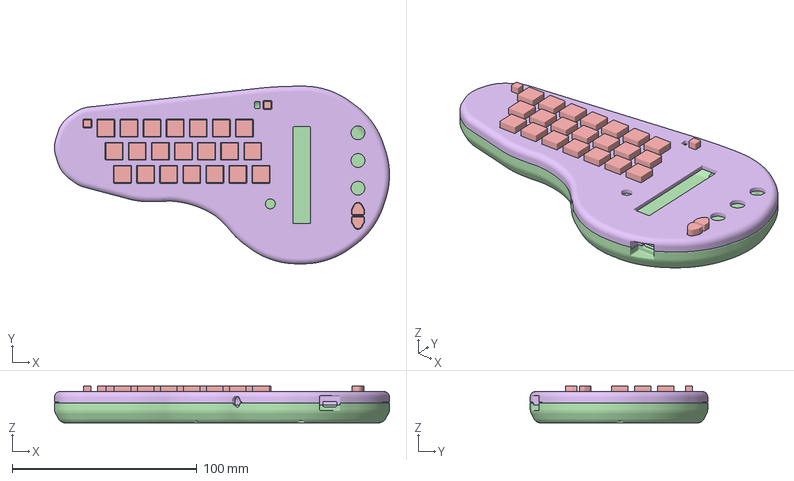
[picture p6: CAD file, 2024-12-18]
hardware/3D/rendering/all_parts.FCStd
181.4 x 96.2 x 20.0 mm
Ext screws
inner_screws
Battery
render_v9_bottom.scad
buttons
render_v9_top1_5.scad

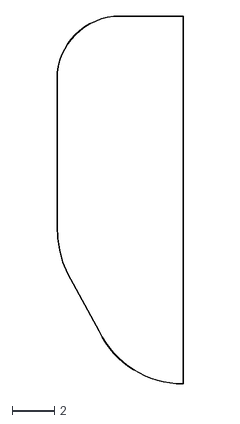
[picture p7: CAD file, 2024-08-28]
hardware/3D/DXF/MiniChord-User_edge_curve.dxf
6.00 x 17.5

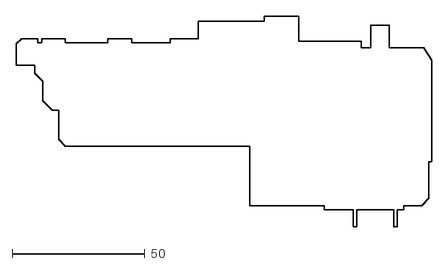
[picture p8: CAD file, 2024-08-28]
hardware/3D/DXF/MiniChord-User_pcb_low_clear.dxf
156.5 x 79.5

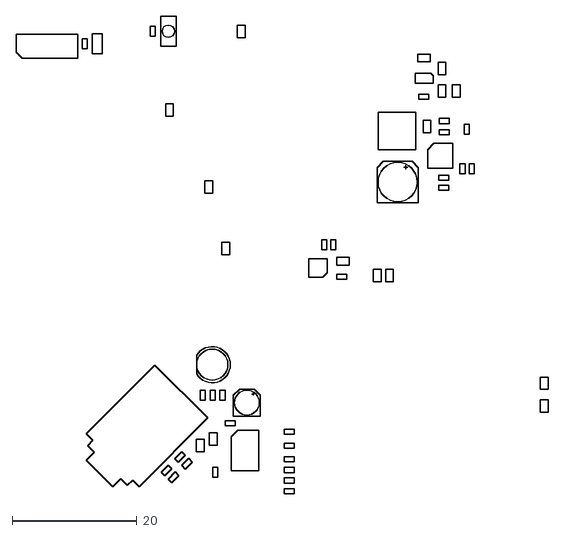
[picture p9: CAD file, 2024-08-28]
hardware/3D/DXF/MiniChord-F_Fab.dxf
85.4 x 76.6

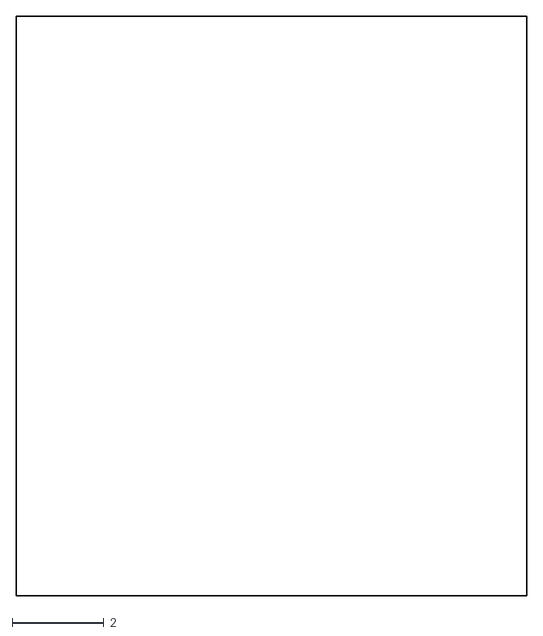
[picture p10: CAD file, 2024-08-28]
hardware/3D/DXF/MiniChord-User_pcb_usb_housing.dxf
11.1 x 12.6

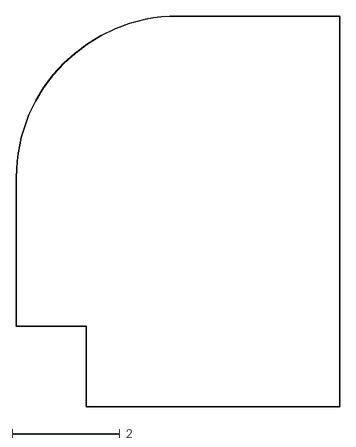
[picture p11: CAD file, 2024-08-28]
hardware/3D/DXF/MiniChord-User_top_edge_curve_05mm_less.dxf
6.00 x 7.25

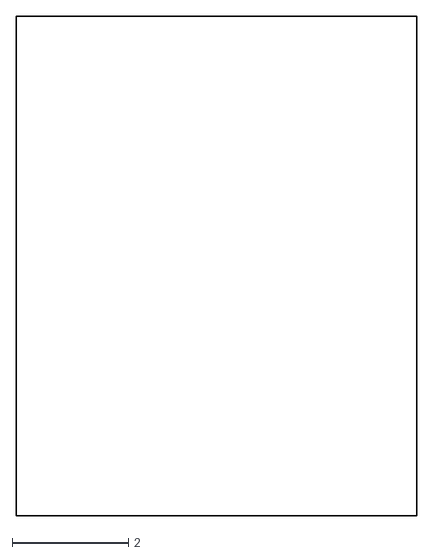
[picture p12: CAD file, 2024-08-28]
hardware/3D/DXF/MiniChord-B_Courtyard.dxf
6.90 x 8.60

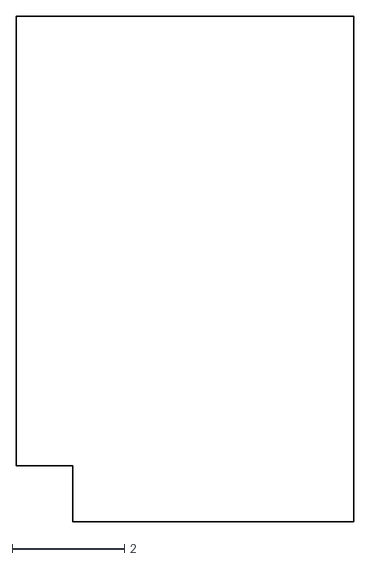
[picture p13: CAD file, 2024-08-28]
hardware/3D/DXF/MiniChord-User_bottom_edge_curve.dxf
6.00 x 9.00

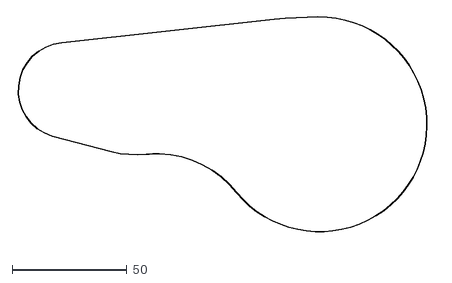
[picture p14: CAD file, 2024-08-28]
hardware/3D/DXF/MiniChord-User_front_plate_outline.dxf
183.1 x 98.9

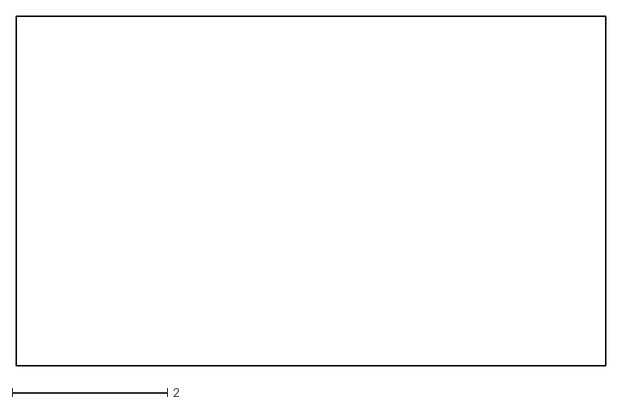
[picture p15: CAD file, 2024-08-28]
hardware/3D/DXF/MiniChord-User_pcb_usb_connector.dxf
7.60 x 4.50

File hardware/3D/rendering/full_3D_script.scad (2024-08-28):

$fn= 15;

import("render_v9_top1_5.scad.stl", convexity=3);
import("render_v9_bottom.scad.stl", convexity=3);
translate([0,0,-1])linear_extrude(height = 0.6, convexity = 0)import("../DXF/MiniChord-User_front_plate_engraving.dxf", convexity=3);

translate([0,0,-3])linear_extrude(height = 4.5, convexity = 0)offset(r=0.2)offset(r=-0.3)import("../DXF/buttons.dxf", convexity=3);

translate([0,0,-3])linear_extrude(height = 11.5, convexity = 0)offset(r=-0.6)import("../DXF/potentiometers.dxf", convexity=3);

translate([61,-60,0]){
    translate([0,0,-3])linear_extrude(height = 4, convexity = 0)import("../DXF/touch_zone-Edge_Cuts.dxf", convexity=3);
}

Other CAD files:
hardware/3D/DXF/MiniChord-User_pcb_support.dxf
hardware/3D/DXF/buttons.dxf
hardware/3D/DXF/potentiometers.dxf
hardware/3D/DXF/MiniChord-User_Eco2.dxf
hardware/3D/DXF/MiniChord-B_Fab.dxf
hardware/3D/DXF/MiniChord-Edge_Cuts.dxf
hardware/3D/DXF/MiniChord-F_Courtyard.dxf
hardware/3D/DXF/MiniChord-User_front_plate_cutout.dxf
hardware/3D/DXF/MiniChord-User_front_plate_engraving.dxf
hardware/3D/DXF/MiniChord-User_holes_housing.dxf
hardware/3D/DXF/MiniChord-User_top_component_clearance.dxf
hardware/3D/DXF/MiniChord-User_top_edge_curve.dxf
hardware/3D/DXF/touch_zone-Edge_Cuts.dxf

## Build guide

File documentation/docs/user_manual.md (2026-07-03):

# **Getting started**

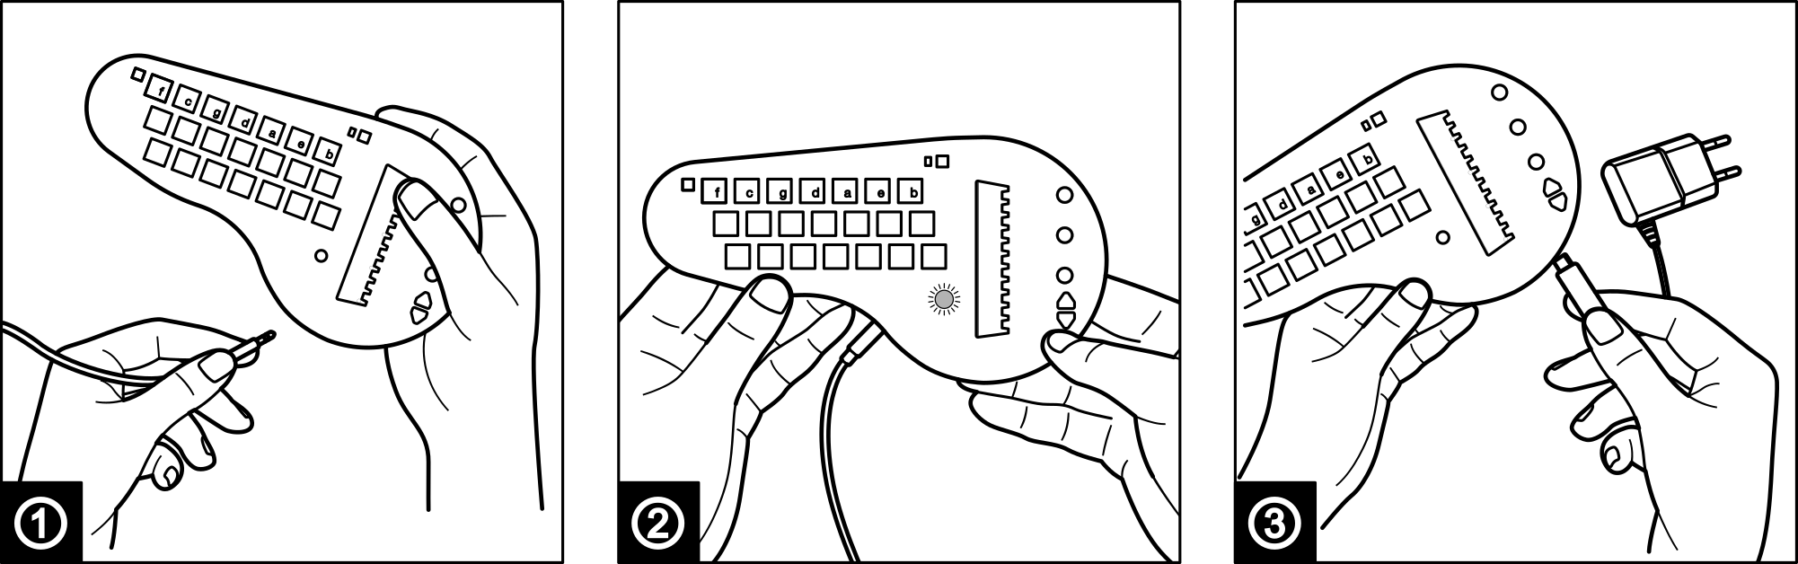
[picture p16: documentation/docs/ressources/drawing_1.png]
[#1 sheet] #1 sheet


**To turn it on, simply plug the headphone jack in ①. The main led ② will shine.** If it does not turn on, then its battery is empty, charge it on any USB wallwart with a micro USB cable **③**. 

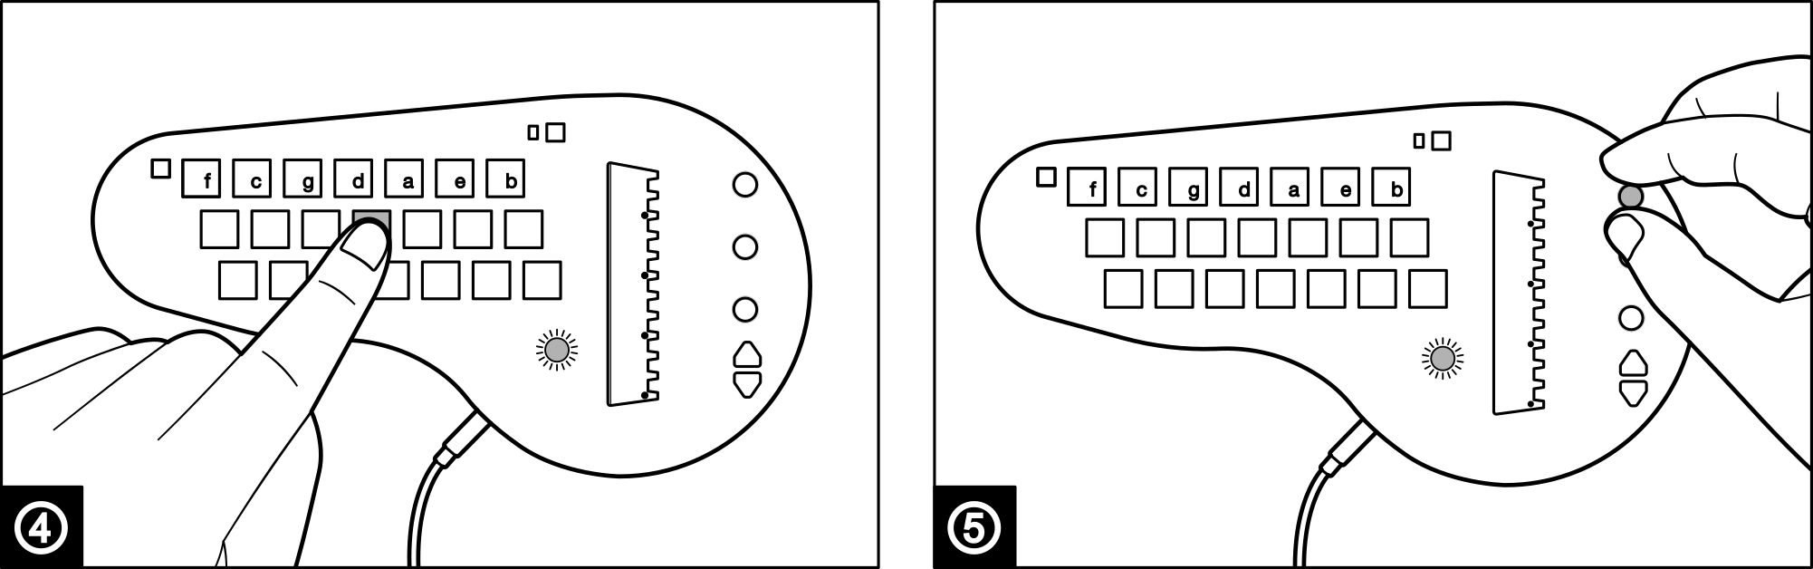
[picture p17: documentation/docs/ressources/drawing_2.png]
[#2 sheet] #2 sheet


**Once it is started, push one of the square buttons ④. You should hear a chord being played.** If you do not hear a sound, check that the first potentiometer is not fully turned left **⑤**. The chord will vary depending on which button you press. 

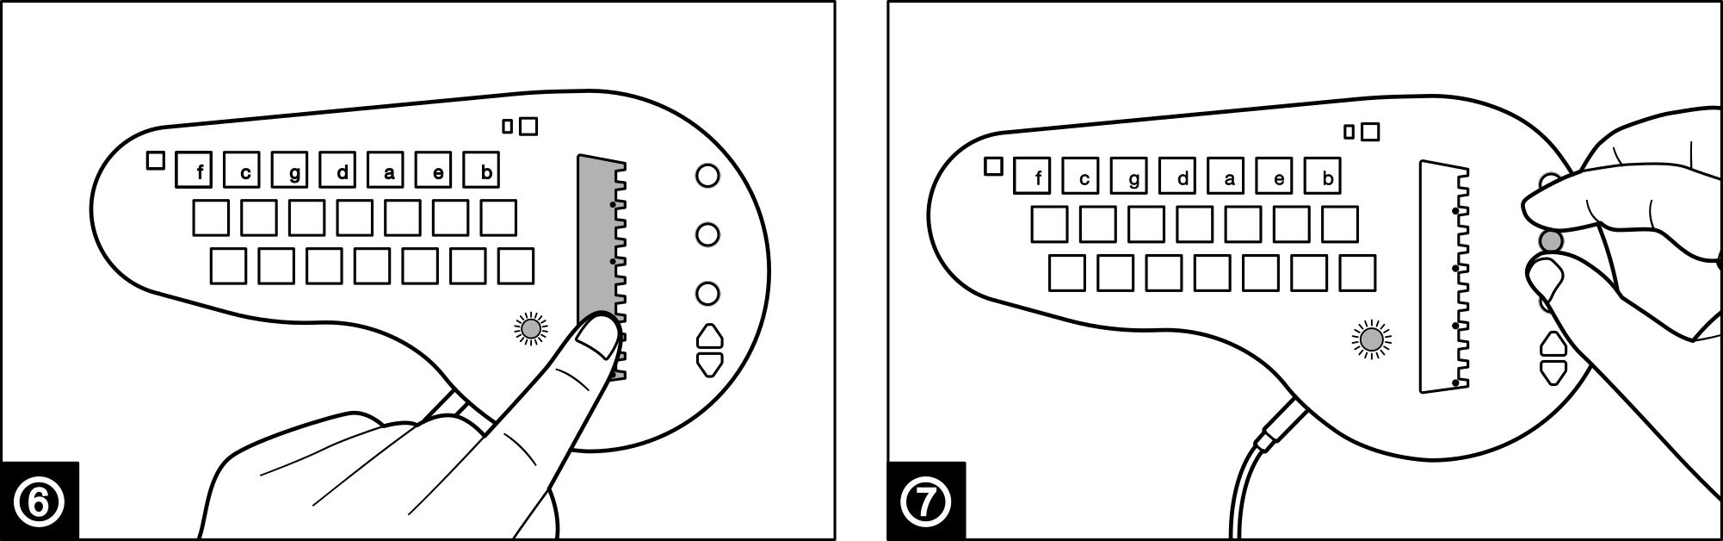
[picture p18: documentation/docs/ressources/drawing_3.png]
[#3 sheet] #3 sheet


**Now drag your finger across the black vertical bar ⑥. You should hear the sound of multiple notes being played sequentially, like a harp.**  If you do not hear that, check that the second potentiometer is not fully turned left **⑦**. Those notes depend on the selected chord. Push different square buttons and test the way the harp reacts.

That's it, you got started! 

**To switch the minichord off, simply remove the headphone jack**. Don't forget it plugged in or it will empty its battery!

# **Basic usage**

Chord selector buttons

## ① Chord selector buttons

The minichord has :

* **21 main chord buttons**, divided into 7 column of 3 buttons;
* **1 "sharp" button (on the top left)**.

**Each column of the main chord buttons is associated with a note of the C Major scale**. It is indicated by the letter on the first row of buttons. 

**Each row of the main chord button is associated with a chord type**:

* the first row will produce major chords;
* the second row will produce minor chords;
* the third row will produce 7th chords. 

By following the row and the column of each button, we can identify the specific chord associated. **Here is the full table of the chords available by the push of a single button**:

| **F** | **C** | **G** | **D** | **A** | **E** | **B** | |
|:-----:|:-----:|:-----:|:-----:|:-----:|:-----:|:-----:|:---:|
|F maj|C maj|G maj|D maj|A maj|E maj|B maj| **Maj**|
|F min|C min|G min|D min|A min|E min|B min| **Min**|
| F7 |C7  |G7  |D7  |A7  |E7  |B7  | **7th**|

**The "sharp" modifier button (top left) will add a semitone to each note of the chord, and can be added to any combination of the main chord buttons.**

> ⚠ In the basic usage only one chord button is pushed at a time to trigger a new chord. However, it is possible to combine buttons to construct more complex chords. This is explained in the ["Advanced usage" section]().

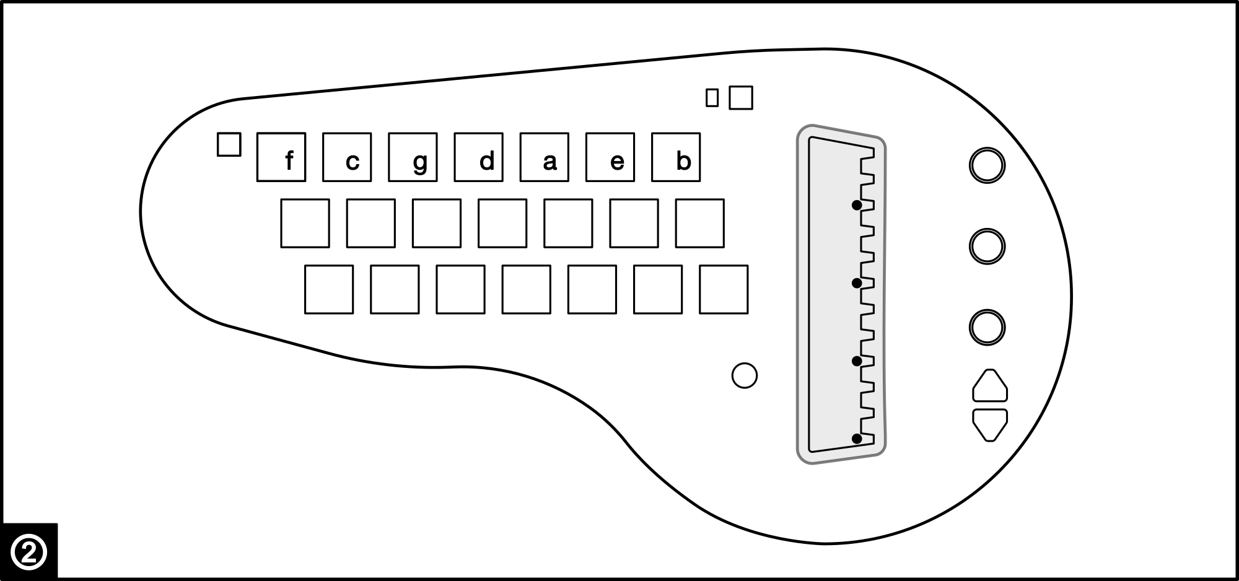
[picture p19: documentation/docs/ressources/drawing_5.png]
Harp touch zone


## ② Harp touch zone 

The harp touch zone is divided **into 12 different sections**, stacked vertically. Touching each section will trigger a note. Notes can be held by keeping in contact with the section. 

This touch zone can be "strummed" by sweeping the finger across all sections, or individual notes can be triggered. 

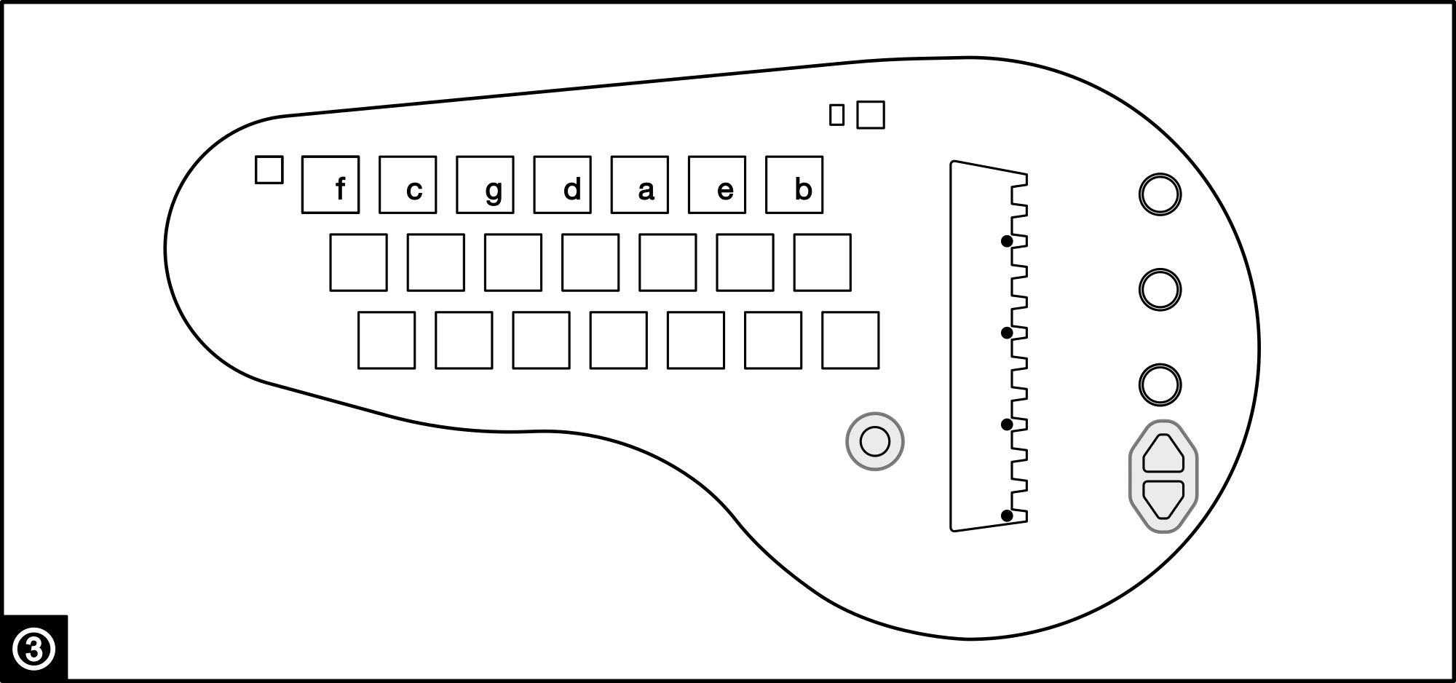
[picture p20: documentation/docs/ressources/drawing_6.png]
Preset selection buttons and indicator


## ③ Preset selection buttons and indicator

The preset selection buttons can be used to switch between presets. **The minichord has 12 internal presets**, that can be replaced by custom presets (see ["Making custom presets"](#custom-presets)). Going up after the 12th preset will circle back to the first, same as going down before the first will circle back to the 12th. 

The main led will shine with a different color for each preset to help you identify the current selected one. 

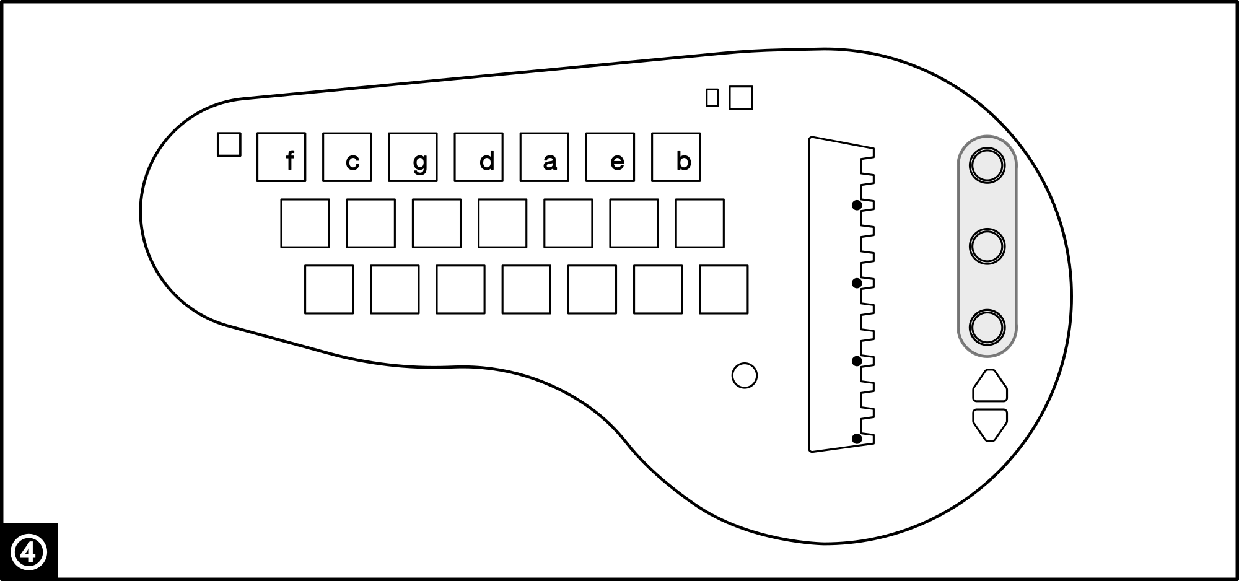
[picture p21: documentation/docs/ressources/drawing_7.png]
Potentiometers


## ④ Potentiometers 

Each of the three potentiometers has one main function, designated by the marking on the enclosure :

* **The first potentiometer from the top** sets up the volume of the chord section;
* **The second potentiometer from the top** sets up the volume of the harp section;
* **The third potentiometer from the top** is assigned to a different function for each preset, depending on what is usefull for it. 

> ⚠ Each of the potentiometers has a secondary function, which is explained in the ["Advanced usage" section](#advanced-usage). 

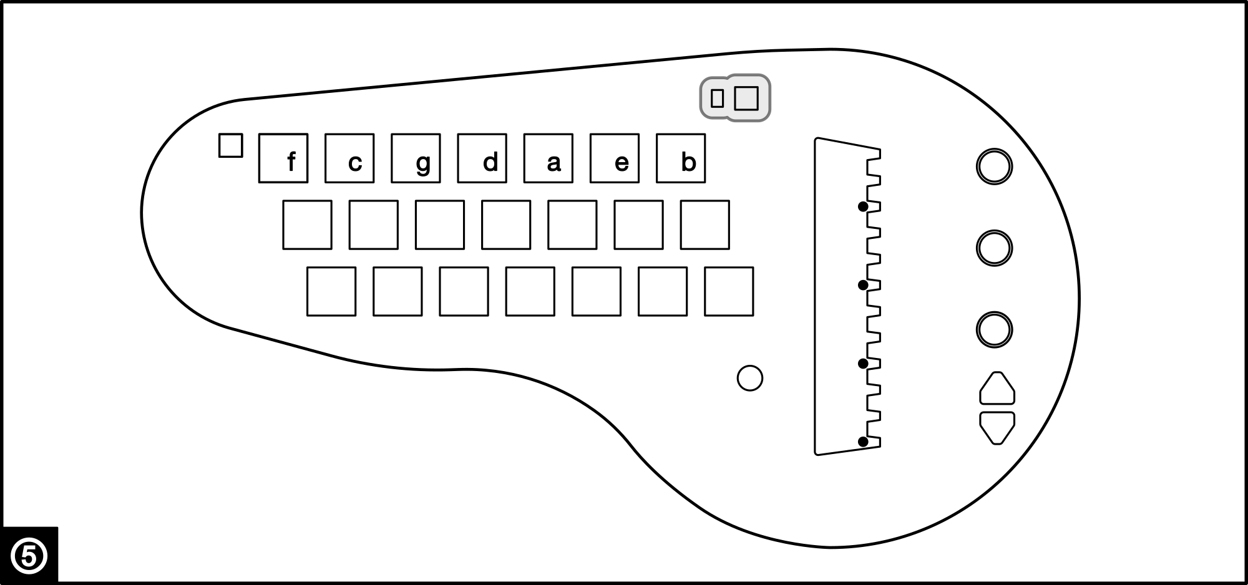
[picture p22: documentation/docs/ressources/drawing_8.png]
Rythm mode button and indicator


## ⑤ Rythm mode button and indicator

The rhythm mode button (on the top right) has two basic modes:

* **discrete**: the chord only stays on for as long as you keep the relevant button pushed. In that mode, the indicator led will be off.
* **continuous**: the chord will keep playing until you push a new button, and seamlessly switch to the next chord. In that mode, the indicator led will be on. 

Simply push the rhythm mode button to switch from one mode to the other. That button may also be used to switch to the arpeggiator mode with a long push, but that subject is handled in the [ "Advanced usage" section](#advanced-usage). 

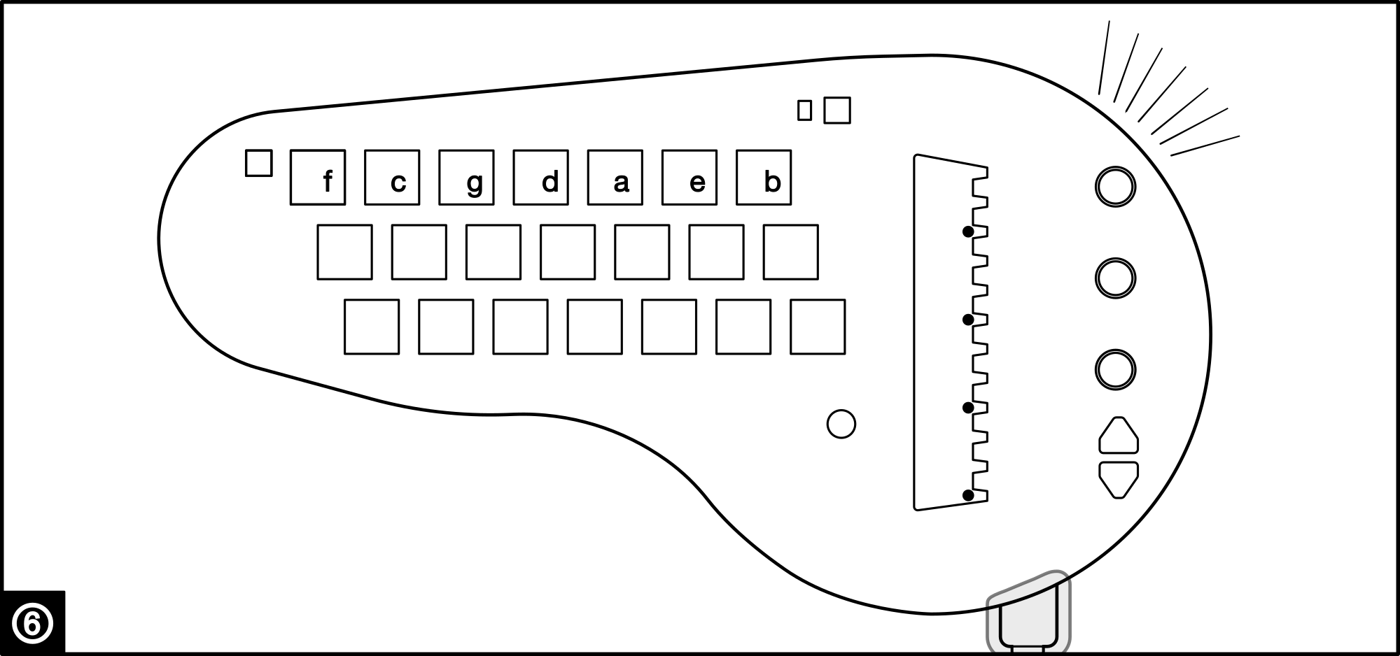
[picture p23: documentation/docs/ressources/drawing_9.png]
Charging


## ⑥ Charging 

Charging is done through the micro USB jack available on the bottom right of the minichord. Connection to any USB outlet will do, and it will draw 500ma of current. 

**When charging, the top right led will shine red**. 

Full charge should be below 3 hours, and **the top right led will shine green once the full charge is attained**. 
Once fully charged, the minichord will play for around 7 hours. 

**When the battery is getting low, the main led will pulse**. Once the pulsing starts, the minichord can play for around 15 minutes more. You can play the minichord while plugged in. 

# **Advanced usage**

## Advanced chord selections

There are two ways to access additional chords on the minichord:

**By combining buttons within the same column**. 

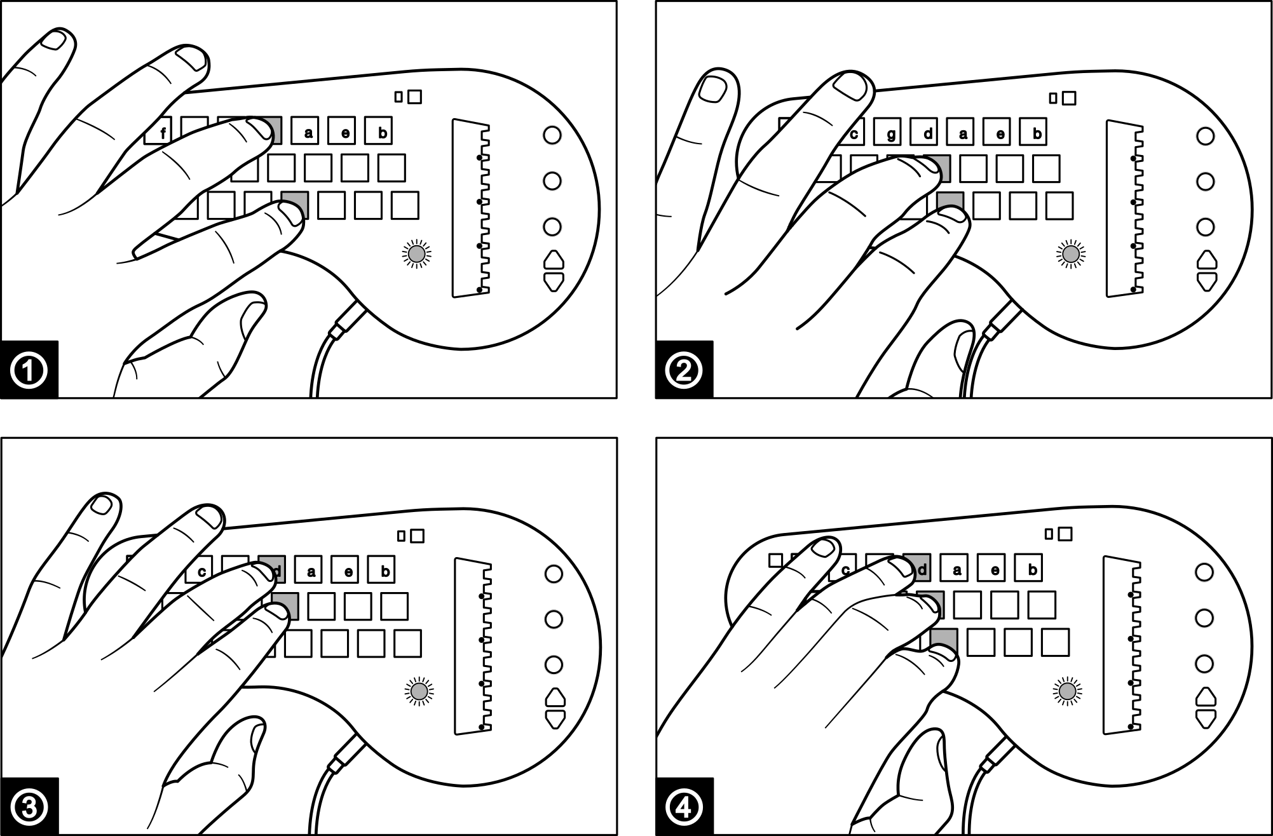
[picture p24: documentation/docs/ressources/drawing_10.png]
combining in a column


It is possible to push more than one button within the same column to access more complicated chords. **The possible combinations are the following**:

* The button from the third row can be combined with a button from either the first or the second row of the same column to obtain a* Major 7* (①) and *Minor 7* (②) chord of the same note;
* The first and second row buttons can be combined within a column to obtain an *diminished* chord (③);
* The three buttons together can be combined to obtain an *augmented* chord (④).

>⚠ Please note that a chord change always happens when a button is pushed. Simply releasing buttons will not change the chord. This is because properly timing a release is difficult with pushbuttons and it would lead to unwanted chord change when switching from a complex chord position. For example... 

**By combining buttons across different columns**

When a chord is selected within a column (even a complex one), **it is possible to replace one of the notes with the fundamental from another column**. 

To do that simply **push any button from the column of the note you wish to borrow the fundamental from**. 

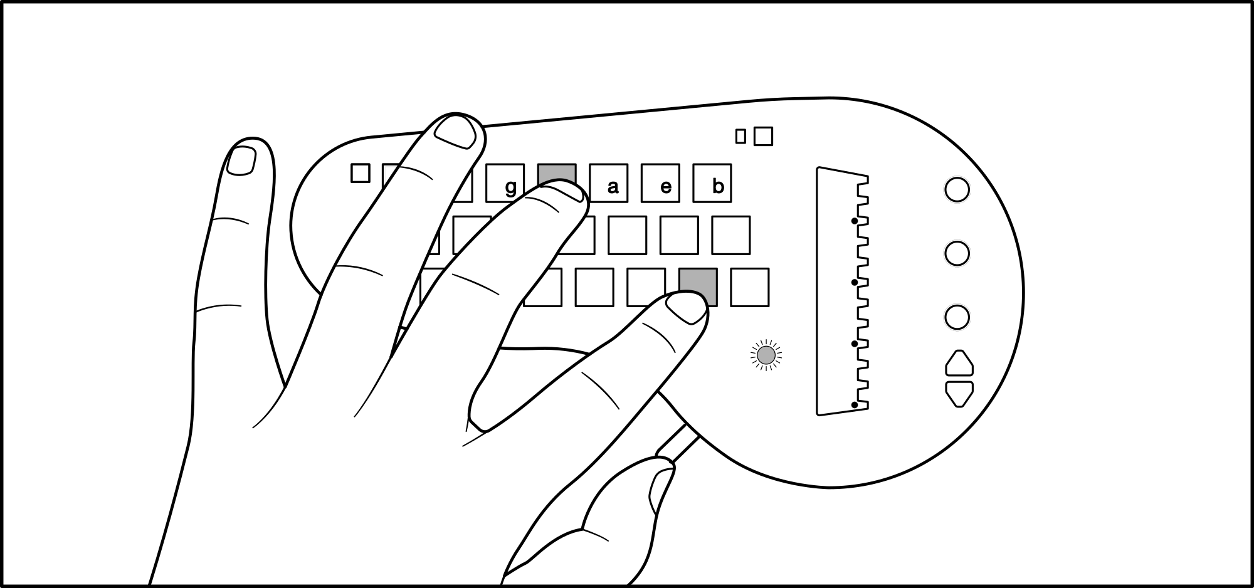
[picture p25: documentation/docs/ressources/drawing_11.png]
combining across columns


Usually, the replaced note is the fundamental of the chord and the substitution is known as a "slash chord", written for example Am/E for an A minor chord with E as the fundamental. However, this is not the case for all presets. 

>⚠ Due to the way the "sharp" button works, some slash chords are impossible to do on the minichord. For example, Am/G is possible, Am#/G# is possible (by holding the "sharp" modifier button), but Am#/G is not. 

## Secondary potentiometer functions

Each of the potentiometers allows you to access a secondary function. The specific secondary function will depend on the selected preset.

**To access the secondary function, you need to hold the "sharp button" while turning the potentiometer.**

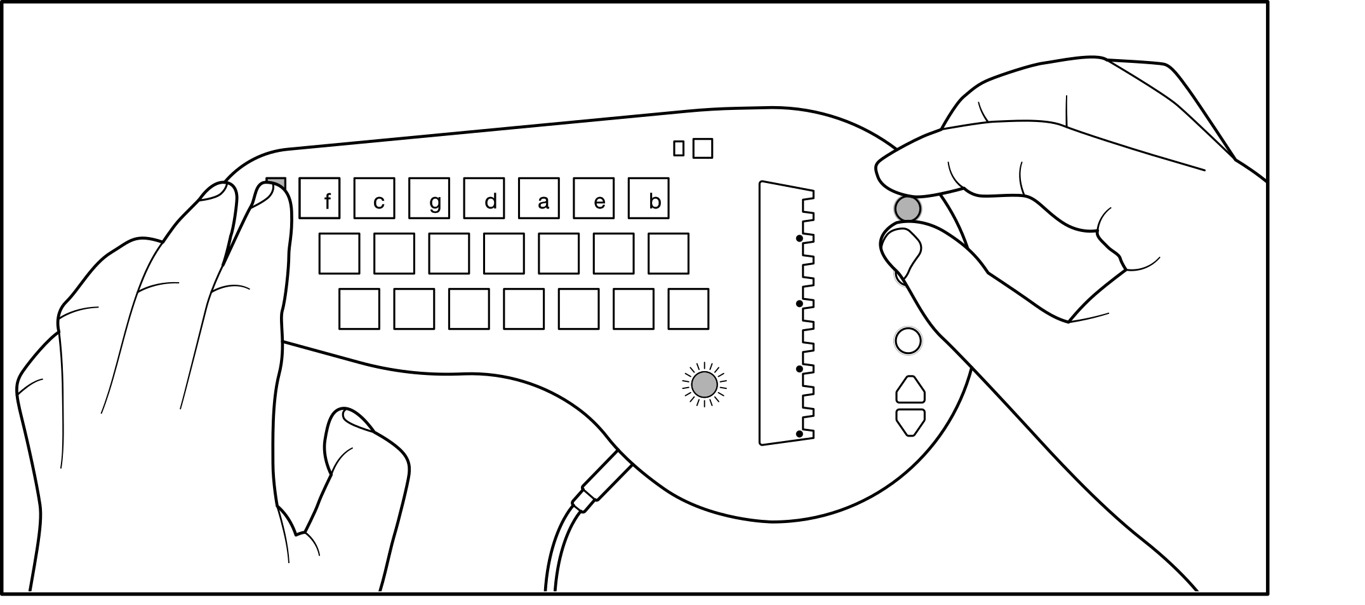
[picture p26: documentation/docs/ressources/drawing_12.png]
Secondary potentiometer functions


>⚠ Please note that the secondary parameter value selected will be memorized by the minichord, but only if you switch between presets (to avoid having to write to memory the selected value with every parameter change). 

## Arpeggiator

The minichord has a very basic arpeggiator function, allowing to play 16 steps pattern on the four voices of the chord section. **To activate the arpeggiator, do a long (more than 1 second) press on the "rhythm" button** (on the top right). The led will flash rythmically and the arpeggiator will start. 

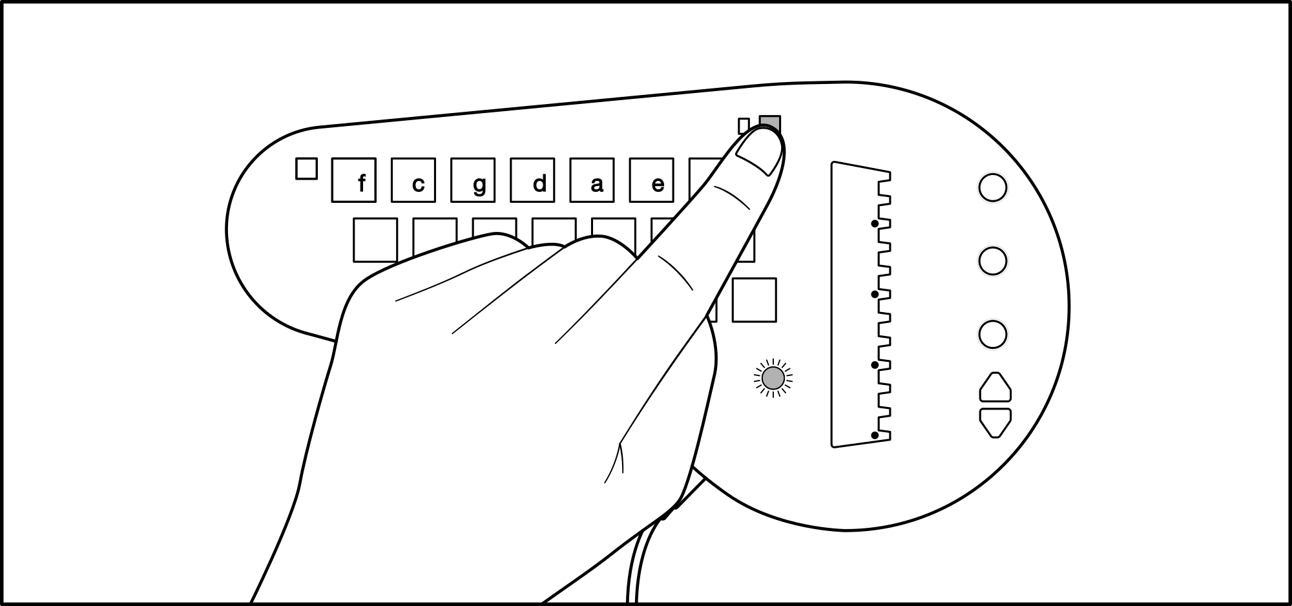
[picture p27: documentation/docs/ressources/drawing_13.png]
Arpeggiator


**While the arpeggiator is playing, you can move from chord to chord by using the chord buttons as usual.** 

>⚠ Depending on the current playing pattern, that change may not be immediately applied and might wait until the next "strong beat". Strong beats are indicated by the rhythm led flashing a brighter than the normal flash.

**While in arpeggiator mode, the rhythm button will function as a "tap tempo"**. By tapping it rhythmically, you can change the current tempo of the arpeggiator. 

To exit the arpeggiator mode, do once again a long press on the "rhythm" button. 

# **Following chord charts**

A good way to use the minichord, especially if you want to cover some popular songs, is to use readily available chord charts.

**Chord charts are a simplified kind of tablature that only includes the lyrics and the chord of the song**. Usually, the chords are written on top of the lyrics, at the moment where they are supposed to happen in the song. 

**Chord charts are very easy to find**, usually all it takes is to google the name of the song followed by "chords".

They usually look like this:

        A              Am

        I'm not in love, so don't forget it,

        G#m7        G#7             C#m            C#m7

        It's just a silly phase I'm going through.

        A                Am

        And just because I call you up,

        G#m7           G#7     

        Don't get me wrong, 

        C#m                            C#m7

        Don't think you've got it made.
        
*Extract from the chord chart of "I'm not in love" by 10cc*

As we see, to be able to play such a chord chart, **we need to have a basic understanding of the way chords are commonly written**. Since there is no widely accepted standard, it may vary slightly between chord charts.

In the below table, we show the way chords are commonly written in a chord chart and how to play them on the minichord, with G for our fundamental:

| Full chord name | Common notations | Button selection pattern|
|---|:---:|:---:|
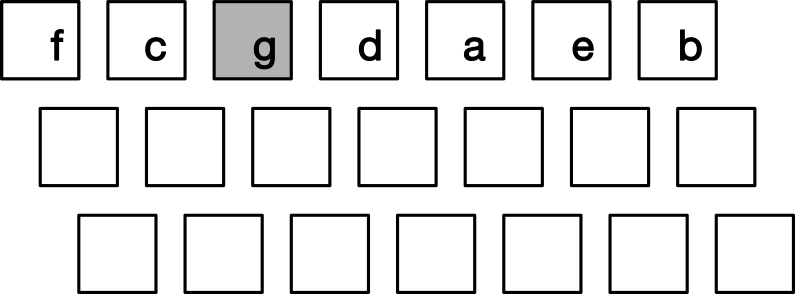
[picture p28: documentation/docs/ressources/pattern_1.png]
pattern
| Major chord | G, G major |   |
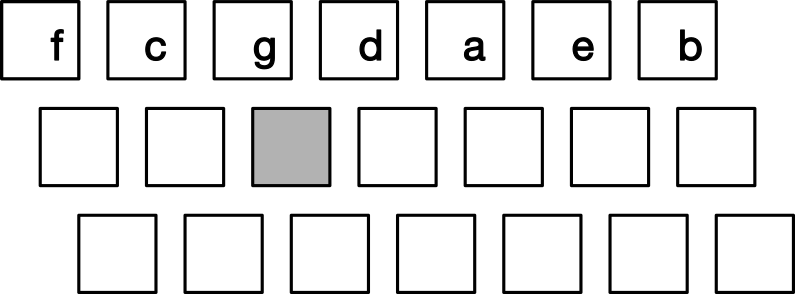
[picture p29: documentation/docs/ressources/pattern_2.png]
pattern
| Minor chord | Gm, Gminor, Gmi, G_ |  |
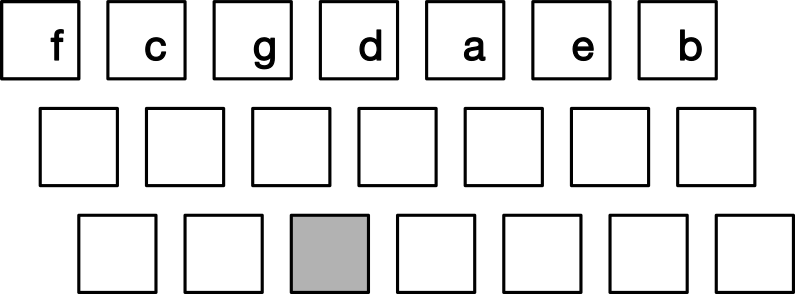
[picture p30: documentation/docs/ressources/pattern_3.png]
pattern
| Dominant 7th chord | G7, G Seven, Gdom |   |
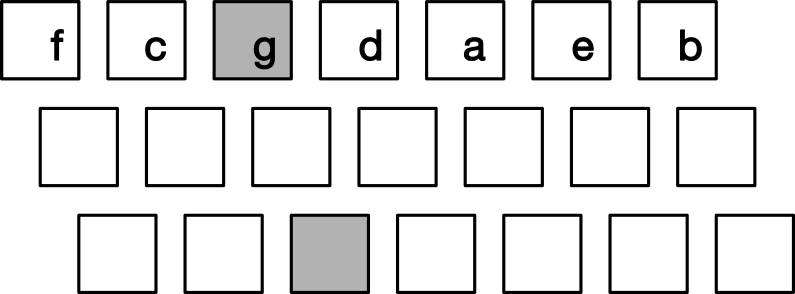
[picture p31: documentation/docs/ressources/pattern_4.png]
pattern
| Major 7th chord | Gmaj7, GΔ, GΔ7, GM7, Gma7|  |
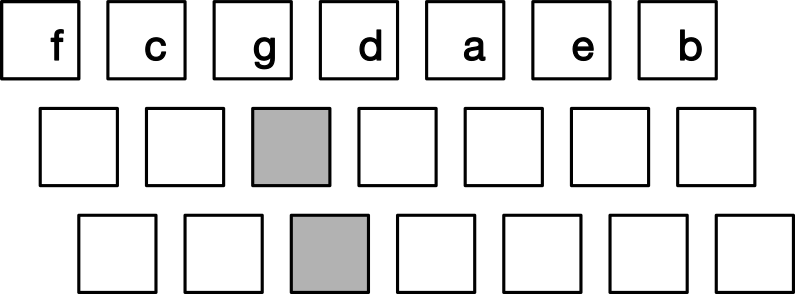
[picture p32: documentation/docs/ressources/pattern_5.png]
pattern
| Minor 7th chord | Gm7, G_7, Gmi7, Gmin7 |  |
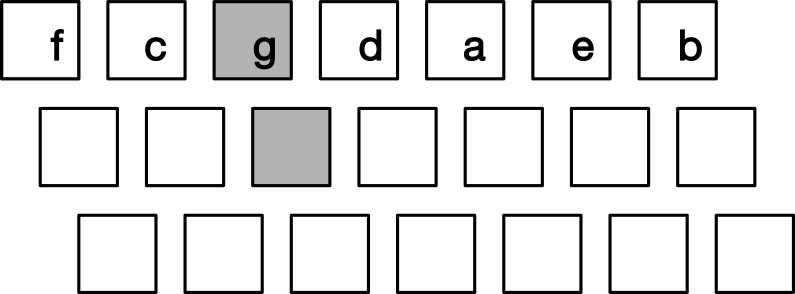
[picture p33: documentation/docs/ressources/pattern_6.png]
pattern
| Diminished chord | Gdim, G° |    |
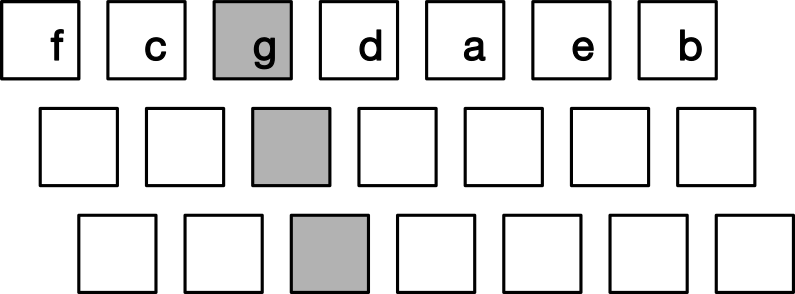
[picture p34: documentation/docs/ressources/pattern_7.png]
pattern
| Augmented chord | Gaug, G+ |  |
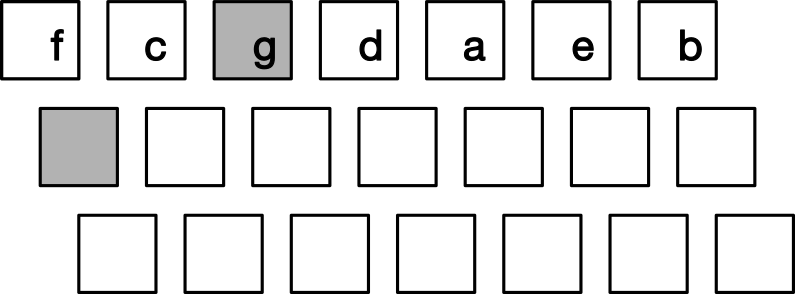
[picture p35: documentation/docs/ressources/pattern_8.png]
pattern
| Slash chord | G/F (for F substitution ) |  |

**Most of the time, the chords are easily playable on the minichord**. If not, it is almost always possible to find acceptable substitutions, but that might require a bit more theoretical knowledge for the player (for example to calculate which slash chord might be an acceptable ersatz for a complex chord). 

# **Custom presets**

You can easily test and save custom presets by going to the [minishop](https://minichord.com/minicontrol/minishop.html) with a a compatible web browser. We recommend using Google Chrome on desktop, because of its support of WebMidi sysex commands.

Making custom presets is a lot more involved, so it is to be reserved to more advanced users.
However, if there is an issue, you can always restore the default presets, so feel free to experiment. 

Presets are designed with an interface called [minicontrol](/minicontrol). In addition to designing your own presets, it allows you to manage the presets loaded into the 12 memory slots of your minichord, which includes loading presets shared by other users.

## minicontrol user manual 

>Please note that [minicontrol](/minicontrol) is a fully offline program, if you wish to access it when you don't have an internet connection, simply use the "save page as" option of the browser (CMD+S) to save it locally.  

**First you need to connect your minichord to minicontrol**.

To do that, first open [minicontrol](/minicontrol) in a compatible web browser. We recommend using Google Chrome on desktop, because of its support of WebMidi sysex commands.

Then connect headphones or a 3.5mm jack to your minichord, and then your minichord to the computer with a USB micro cable. Please make sure that the cable used is not "charge-only" and supports data. 

Reload the webpage. You should be shown a prompt asking you to "Control and reprogram youy Midi Devices". Allow it. This is necessary to send Midi sysex commands that are used to programm the minichord. 

The minichord should then be connected. If not, a red warning should give you instructions to allow you to identify which step failed. 

**You can then circle around the presets on your minichord using the preset selection buttons on the minichord**. 

The associated internal parameters will be displayed on the screen. 

Those parameters are grouped in three categories :

* **"Global parameters"**: general parameters that impact the general functioning of the preset. It includes the reverb settings that is applied to both the chord and the harp, and the potentiometer function settings;
* **"Harp parameters"**: parameters related to the sound synthesis of the harp part of the minichord;
* **"Chord parameters"**: parameters related to the sound synthesis of the chord part of the minichord.

By hovering on each parameter name (a question mark will appear), a short description of its function will be displayed on your screen. 

You can start experimenting by modifying settings and seeing how it impacts the sound of your preset. Note that by default, changes made are not loaded into the minichord. Simply using the preset selection buttons to go one preset up then one preset down will reset the current preset. Note that the sliders can be controlled by the arrow keys to select values precisely. 

**You can then use the command buttons to modify the presets loaded on your minichord**

[minicontrol](/minicontrol) offers the following control buttons: 

  * **"Save current settings to selected bank"**: by using the dropdown to choose a bank number, you can save the current parameters to the selected bank slot. This can be used to copy presets from one bank to another;
  * **"Reset selected bank"**: by using the dropdown to choose a bank number, you can reset the parameters of the selected bank slot to factory settings
  * **"Reset all banks"**: this button simply puts the minichord to factory settings by resetting all bank slots

It also allows you to share your presets and to load presets made by other users, with two additional buttons:

* **"Share setting"**: this button will copy in your clipboard a parameter string. This parameter string fully describes the current setting playing on the minichord. 
* **"Load setting"**: this button will prompt a text entry. By pasting a parameter string it will be loaded on your minichord for you to test it. Please note that if you wish to save it into a bank slot of your minichord, you will need to use the "Save current setting to selected bank" button. 

>If you have a preset that you wish to share with all minichord users, please send the preset string with a short description and the name of your preset to [presets@minichord.com](mailto:presets@minichord.com).

## Alternative control platforms

Minichord users have developed some very cool alternative platforms that interface with the minichord and allow to create custom presets. 
- the [minichord Sound Lab](https://minichorddrawn.github.io/minichord-soundlab/#play)
- [Keyandcableco's minicontrol](https://keyandcableco.github.io/minicontrol/)

Make sure to test them as they offer many alternative features!

## Synthesis schematic

To be able to better understand the synthesis parameters, please find below the synthesis schematics for the harp and chord section :
<div class="synthesis_container">
  <pre><code>

 Harp section                         ┌ ─ ─ ─ ─ ─ ─ ─ ─ ─ ─ ─ ─ ─ ─ ─ ─ ─ ─ ─ ─ ─ ─ ─ ─ ─ ─ ─ ─
                                     ┌────────────────────────────────────────────────────────┐│ x12
                                    ┌┴───────────────────────────────────────────────────────┐│
┌─────────┐                         │┌────────────────┐                                      │││
│DC signal├────────────────────────▶││filter enveloppe│──────────┐          ┌───────────────┐││
└─────────┘                         │└────────────────┘          └─────────▶│low-pass filter│││├───┐
┌───────────┐   ┌────────────────┐  │┌─────────────────────┐  ┌────────┐ ┌─▶│               │││    │
│vibrato OSC├──▶│vibrato envelope├┬▶││modulated string OSC ├─▶│envelope├─┘  └───────────────┘││┘   │
└───────────┘   └────────────────┘│ │└─────────────────────┘  └────────┘                     ├┘    │
                                  │ └────────────────────────────────────────────────────────┘     │
┌───────────┐   ┌────────────────┐│                                                                │
│  bend DC  ├──▶│  bend envelope ├┘                                                                │ 
└───────────┘   └────────────────┘                                                                 │                    
                                                                                                   │
┌──────────────────────────────────────────────────────────────────────────────────────────────────┘
│  ┌──────────┐  ┌─────────────┐  ┌─────────────┐  ┌─────┐  ┌────────────┐      ┌──────────┐
├─▶│waveshaper├─▶│ waveshaper  ├┬▶│  delay mix  ├─▶│delay├─▶│filter delay├─┬───▶│effect mix├───────┐
│  └──────────┘  │     mix     ││ │             │  └─────┘  └────────────┘ │ ┌─▶│          │       │
└───────────────▶│             ││ │             │                          │ │  └──────────┘       │
                 └─────────────┘│ └─────────────┘                          │ │                     │
                                │        ▲                                 │ │                     │
                                │        └─────────────────────────────────┘ │                     │
                                └────────────────────────────────────────────┘                     │
┌──────────────────────────────────────────────────────────────────────────────────────────────────┘
│              ┌──────────┐              ┌─────────────┐  ┌──────┐  ┌──────────┐
└─────────────▶│multiplier├─────────────▶│output filter├┬▶│reverb├─▶│reverb mix├─▶ output
┌───────────┐  │          │┌──────────┐  │             ││ └──────┘  │          │
│tremolo OSC├─▶│          ││filter OSC├─▶│             │└──────────▶│          │
└───────────┘  └──────────┘└──────────┘  └─────────────┘            └──────────┘

 Chord section     ┌──────────────────────────────────────────────────────────────────────┐
                  ┌┴─────────────────────────────────────────────────────────────────────┐│ x4
                 ┌┴─────────────────────────────────────────────────────────────────────┐││
                ┌┴─────────────────────────────────────────────────────────────────────┐│││
┌───────────┐   │┌────────────────┐  ┌───────────────┐  ┌─────┐  ┌──────┐  ┌──────────┐││││
│vibrato OSC├─▶ ││vibrato envelope├┬▶│modulated OSC 1├─▶│ mix ├─▶│filter├─▶│multiplier│││││
└───────────┘   │└────────────────┘│ ├───────────────┤  │     │  └──────┘  └──────────┘││││
┌───────────┐   │┌────────────────┐├▶│modulated OSC 2├─▶│     │     ▲           ▲      ││││
│  bend DC  ├─▶ ││vibrato envelope├│ ├───────────────┤  │     │     │           │      ││││────────┐
└───────────┘   │└────────────────┘└▶│modulated OSC 3├─▶│     │     │           │      ││││        │
                │                    └─────────┬─────┤  │     │     │           │      ││││        │
                │                              │noise├─▶│     │     │           │      ││││        │
┌──────────┐    │┌───────────────┐             └─────┘  └─────┘     │           │      ││││        │
│filter OSC├──▶ ││filter envelope├──────────────────────────────────┘           │      ││││        │
└──────────┘    │└───────────────┘                                              │      ││││        │
┌───────────┐   │┌────────────────┐                                             │      ││├┘        │
│tremolo OSC├─▶ ││tremolo envelope├─────────────────────────────────────────────┘      │├┘         │
└───────────┘   │└────────────────┘                                                    ├┘          │
                └──────────────────────────────────────────────────────────────────────┘           │
                                                                                                   │
┌──────────────────────────────────────────────────────────────────────────────────────────────────┘
│  ┌──────────┐  ┌─────────────┐  ┌─────────────┐  ┌─────┐  ┌────────────┐      ┌──────────┐
├─▶│waveshaper├─▶│ waveshaper  ├┬▶│  delay mix  ├─▶│delay├─▶│filter delay├─┬───▶│effect mix├───────┐
│  └──────────┘  │     mix     ││ │             │  └─────┘  └────────────┘ │ ┌─▶│          │       │
└───────────────▶│             ││ │             │                          │ │  └──────────┘       │
                 └─────────────┘│ └─────────────┘                          │ │                     │
                                │        ▲                                 │ │                     │
                                │        └─────────────────────────────────┘ │                     │
                                └────────────────────────────────────────────┘                     │
┌──────────────────────────────────────────────────────────────────────────────────────────────────┘
│  ┌─────────────┐  ┌──────┐  ┌──────────┐
└─▶│output filter├┬▶│reverb├─▶│reverb mix├─▶ output
   │             ││ └──────┘  │          │
   │             │└──────────▶│          │
   └─────────────┘            └──────────┘
    </code></pre>
</div>

# **MIDI support**

When plugged in to a computer through USB, the minichord will appear as a MIDI instrument exposing two separate MIDI port. The first port carries the MIDI signal from the chord section, and the second port from the harp section. The minichord has to be turned on to appear, so make sure that an audio output cable is plugged in to the minichord. 

For example, using the "Audio MIDI Setup" utility of macOS we can look at the characteristics of the minichord

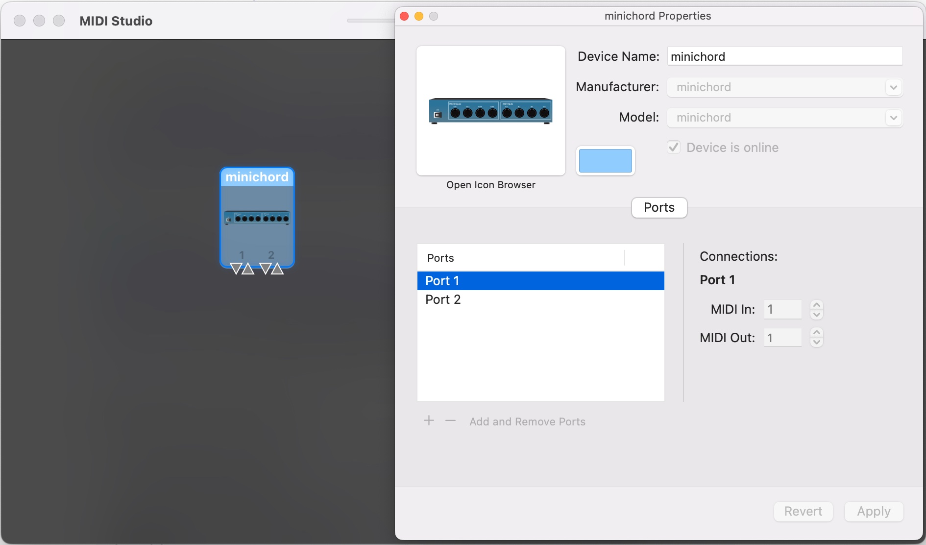
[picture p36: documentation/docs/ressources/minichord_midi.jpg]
Midi screen


The potentiometers control the velocity of the notes of each port. All notes are sent to the channel 1 of each port. Each port can be independently assigned to virtual instruments by most music softwares. For example, using Surge XT, using the option screen allows to select which midi input to active.

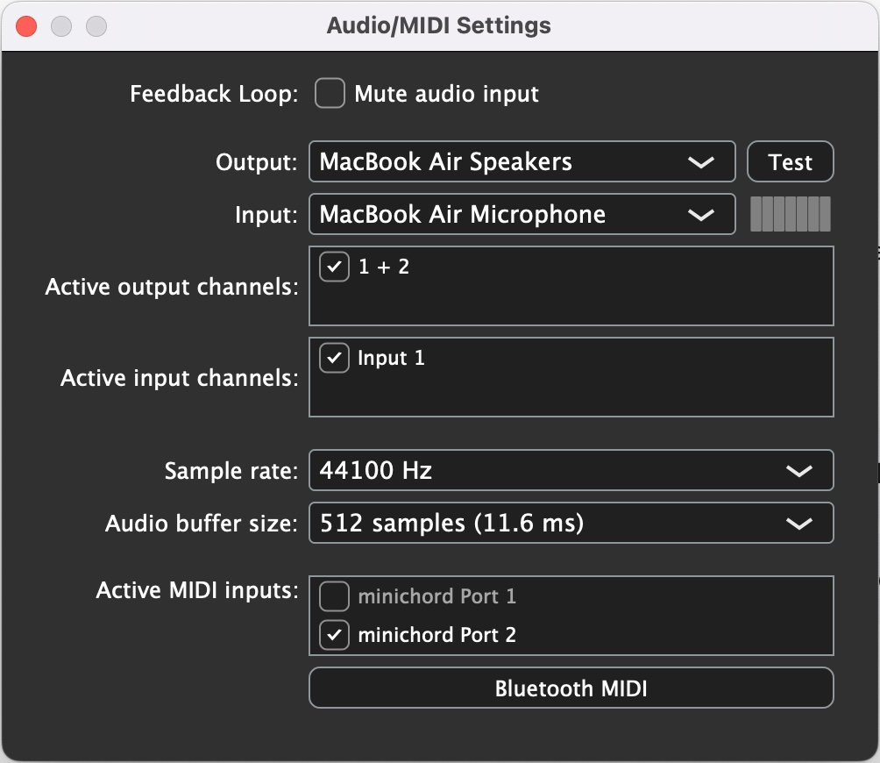
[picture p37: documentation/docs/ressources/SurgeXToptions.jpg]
Surge XT screen


The minichord stays usable with softwate that does not distinguish between ports (such as GarageBand), but all of the notes will be attributed to a single instrument. 

# Updating the firmware

The process to update the minichord firmware is quite simple. 

First you need to install the application that will allow to upload the firmware. It is provided by PJRC and precise instruction for it are available [on their website](https://www.pjrc.com/teensy/loader.html). It supports macOS, Linux and Windows. 

To upload the firmware, please use the following steps:

* Plug the battery into the minichord;
* Plug in the micro USB cable between the minichord and your computer;
* Plug the headphone into the minichord 
* Open the Teensy Loader; 
* Download the hex file of the latest firmware from the [Source section](/source);
* Drop the hex file on the Teensy loader;

Once all those steps are done, use a thin pin (for example a hair pin) to push into the hole at the back of the minichord

resetting the Teensy

If you carefully followed those steps, the Teensy Loader will indicate "Download Complete" then "Reboot OK". The main colour led of the PCB should light up. 

After an update, it might be necessary to use [minicontrol](/minicontrol) to wipe all presets back for factory using the "reset all banks" option, as changes might render previous presets incompatible (or at least weird-sounding).

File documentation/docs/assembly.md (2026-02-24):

# **Assembly notes**

Please note that depending on the kit version, you may not have to follow all the steps:

* If you are building a minichord from scratch, start at [PCB Manufacturing](#pcb-manufacturing)
* If you have a minichord kit start at [Enclosure Manufacturing](#enclosure-manufacturing)

In any case, bill of material (BOM) and necessary tools are listed at the beginning of each section.

# **PCB Manufacturing**

Manufacturing files for the PCB are available in the [Source section](/source) in Gerber format. 

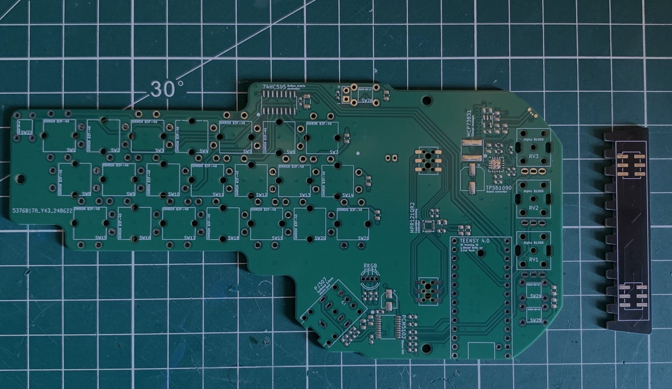
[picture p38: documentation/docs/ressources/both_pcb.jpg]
the two minichord PCB


A minichord is composed of two PCB:

* The main PCB that is a four layer 1.6mm board;
* The touch zone PCB that is a two layer 1.6mm board (please remember that this PCB will be visible, so choose colour accordingly and remove any marking that the fab house would like to add). 

Any good fab house should accept those files for manufacture.

# **SMD Soldering**

The main PCB requires some SMD components. The list if available [here](https://github.com/BenjaminPoilve/minichord/blob/main/hardware/BOM/electronics_BOM.csv). If you are experimented with SDM soldering it is possible to do that step yourself. However it requires quite advanced capabilities to properly solder the IC packages used. 

For the placement of the component, please refer to [this document](./ressources/smd_assembly/g66188.png).

For the manufacturer reference of the different components, please refer to [this document](https://github.com/BenjaminPoilve/MiniChord/blob/main/hardware/BOM/electronics_BOM.csv).

Once all the component are soldered, your PCB should look like this:

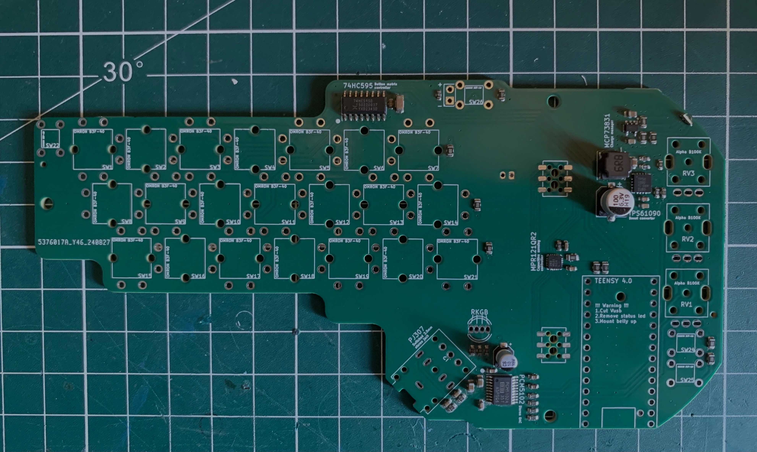
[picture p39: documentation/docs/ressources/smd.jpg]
After SMD assembly after SMD assembly


# **Through-hole soldering**

<details>
    <summary> <b>BOM</b> </summary>
<table class="table table-striped table-hover">
<thead>
<tr>
<th><strong>ID</strong></th>
<th><strong>Part</strong></th>
<th><strong>Link</strong></th>
<th><strong>Quantity</strong></th>
</tr>
</thead>
<tbody>
<tr>
<td><strong>D1</strong></td>
<td>Red LED</td>
<td><a href="https://www.mouser.fr/ProductDetail/604-WP169XID">Mouser</a></td>
<td>1</td>
</tr>
<tr>
<td><strong>D2</strong></td>
<td>5mm RKGB LED</td>
<td>-</td>
<td>1</td>
</tr>
<tr>
<td><strong>J2</strong></td>
<td>Switched Audio Jack&nbsp;</td>
<td><a href="https://www.mouser.fr/ProductDetail/490-SJ-3566AN">Mouser</a></td>
<td>1</td>
</tr>
<tr>
<td><strong>J3</strong></td>
<td>JST PH 2mm 2pin male angled</td>
<td>-</td>
<td>1</td>
</tr>
<tr>
<td><strong>N/A</strong></td>
<td>503450 1000mAh battery</td>
<td>-</td>
<td>1</td>
</tr>
<tr>
<td><strong>&gt;&nbsp; RV1-RV3</strong></td>
<td>Potentiometer</td>
<td><a href="https://www.mouser.fr/ProductDetail/317-2090F-100K">Mouser</a></td>
<td>3</td>
</tr>
<tr>
<td><strong>&gt;&nbsp; SW22, SW24, SW25, SW26</strong></td>
<td>Tactile switch 6x6mm</td>
<td><a href="https://www.mouser.fr/ProductDetail/653-B3F-1050">Mouser</a></td>
<td>4</td>
</tr>
<tr>
<td><strong>&gt;&nbsp; SW1-SW21</strong></td>
<td>Tactile switch 12x12mm</td>
<td><a href="https://www.mouser.fr/ProductDetail/653-B3F-4050">Mouser</a></td>
<td>21</td>
</tr>
<tr>
<td><strong>&gt;&nbsp; J1, J4</strong></td>
<td>Touch header female</td>
<td><a href="https://www.mouser.fr/ProductDetail/855-M20-7810345R">Mouser</a></td>
<td>2</td>
</tr>
<tr>
<td><strong>N/A</strong></td>
<td>Touch header male</td>
<td><a href="https://www.mouser.fr/ProductDetail/855-M20-8760346">Mouser</a></td>
<td>2</td>
</tr>
<tr>
<td><strong>U1</strong></td>
<td>Teensy 4.0</td>
<td>PJRC</td>
<td>1</td>
</tr>
<tr>
<td><strong>N/A</strong></td>
<td>Teensy headers</td>
<td><a href="https://www.mouser.fr/ProductDetail/200-TSW13220TS">Mouser</a></td>
<td>1</td>
</tr>
</tbody>
</table>

<p>To facilitate ordering from Mouser, here is a <a href="https://www.mouser.fr/api/CrossDomain/GetContext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">prefilled basket</a>. </p>
</details>

<details>
    <summary> <b>Tools</b> </summary>
    <ul>
<br>
<li>Soldering iron and solder wire; </li>
<li>X-acto knife (or another precise cutter);</li>
<li>Diagonal cutting pliers (the Knipex "Super Knips" are worth the price);</li>
<li>[Optional] Multimeter.</li>
</ul>
</details>
<hr>

Before starting the soldering, it might be useful to identify the position of each component and do a dry run assembly. This will ensure you properly identify the position of each part and, in consequence, that you indeed have all the components of the BOM. 

## Teensy preparation 

Before soldering, some small modifications need to be made to the Teensy 4.0 Board. 

**The onboard led needs to be disabled**. This step is purely aesthetic so if you don't feel confortable doing that modification it is ok (it will simply give your minichord a soft orange glow). 

The led is next to the pin 13 of the Teensy. To identify it, simply plug your teensy using a micro USB cable. The led will blink.

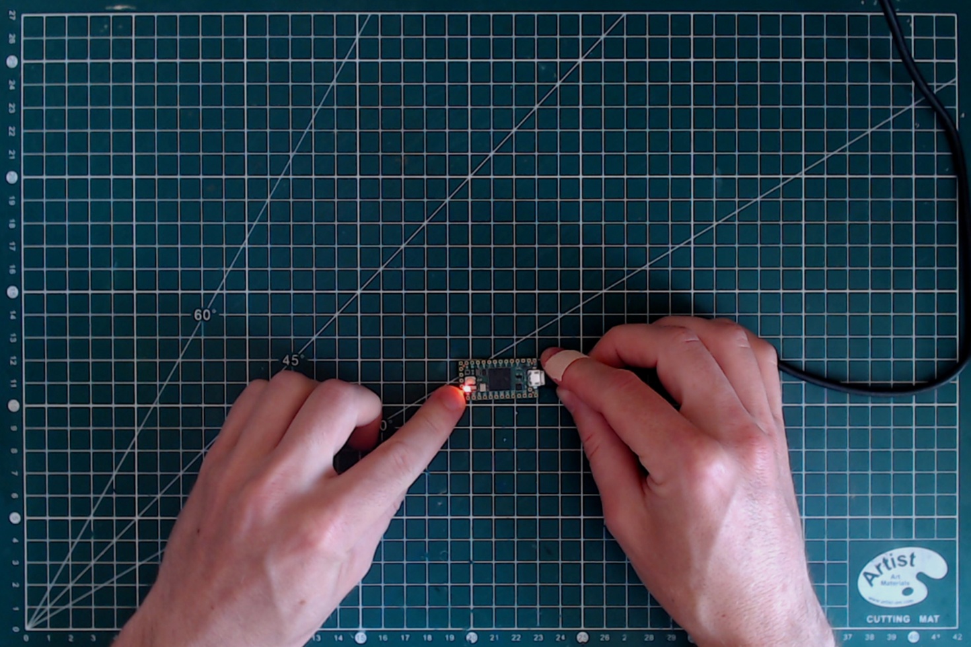
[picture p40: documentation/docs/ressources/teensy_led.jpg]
identifying the led


There is a trace on the top side between the led and the reset pushbutton. Cut that trace using the X-acto (the specific position is in red in the image below). 

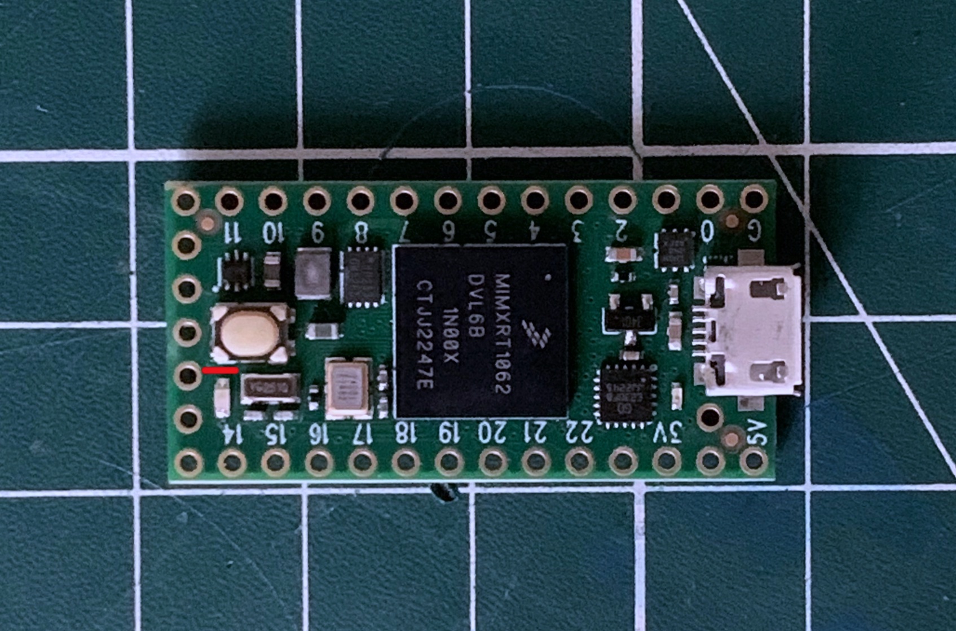
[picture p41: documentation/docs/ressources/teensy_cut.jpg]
cutting the led


Plug the Teensy again, and check that the led is not blinking anymore. To make sure that you did not damage the Teensy, you can simply use the Teensyduino program to upload any sketch and check that it is still working normally (while the led is not glowing). 

**Then we need to cut the USB power**. This step is not optional as it allows battery to function as expected. USB power will then be routed to the battery for charging and the Teensy will only be powered when an audio jack is inserted. 

There is pads on the belly of the Teensy specifically for that reason. It is situated next to the 5V pin. With the X-acto, cut the trace between the two exposed pads. 

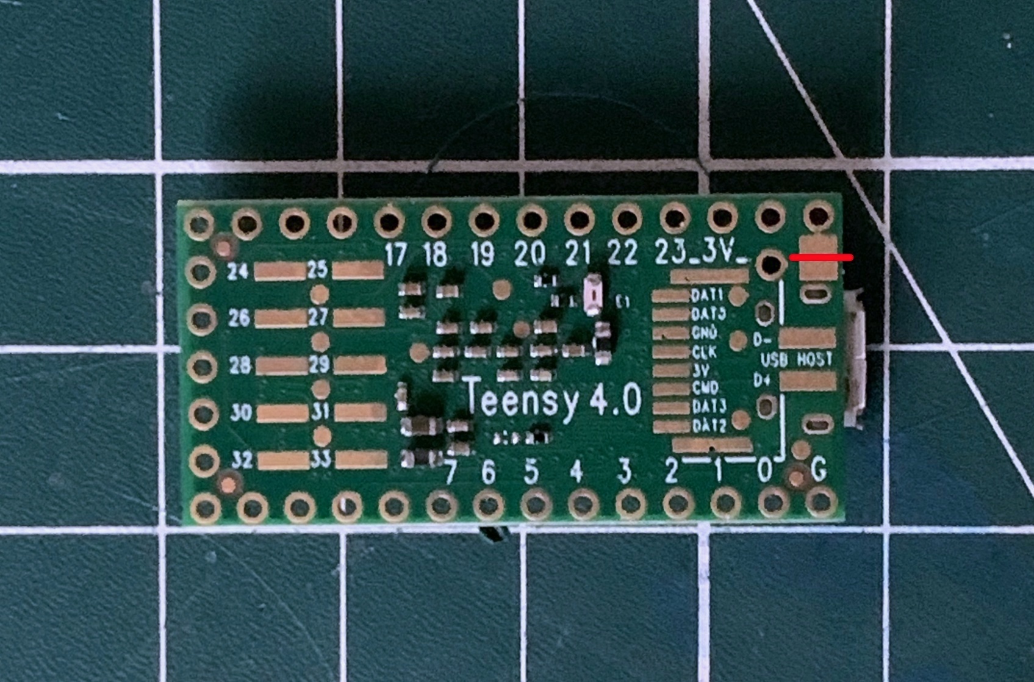
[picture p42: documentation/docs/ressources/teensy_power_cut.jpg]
cutting the VUSB


Once it is done, it's a good idea to check with a multimeter that there is indeed no contact between the two pads. 

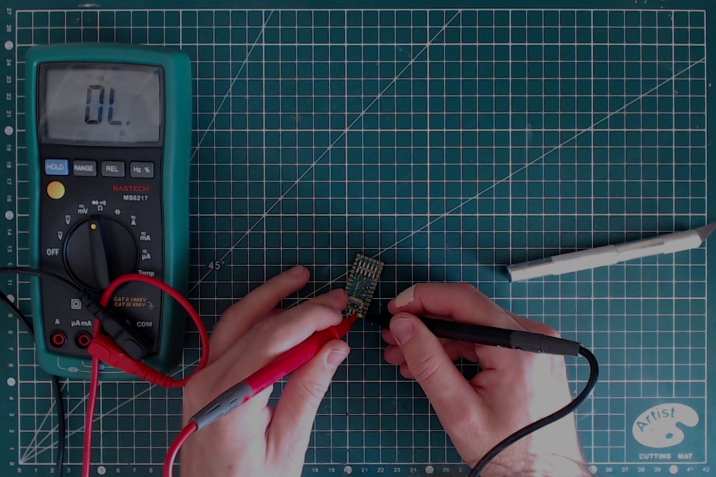
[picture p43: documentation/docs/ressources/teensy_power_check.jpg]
checking the cut


## Pushbuttons soldering

### 12x12mm pushbuttons

Let's start with the 12x12mm pushbuttons. The first step is to insert them all (21) on the PCB. It is a close fit, so to make it easier start with the middle line of buttons. 

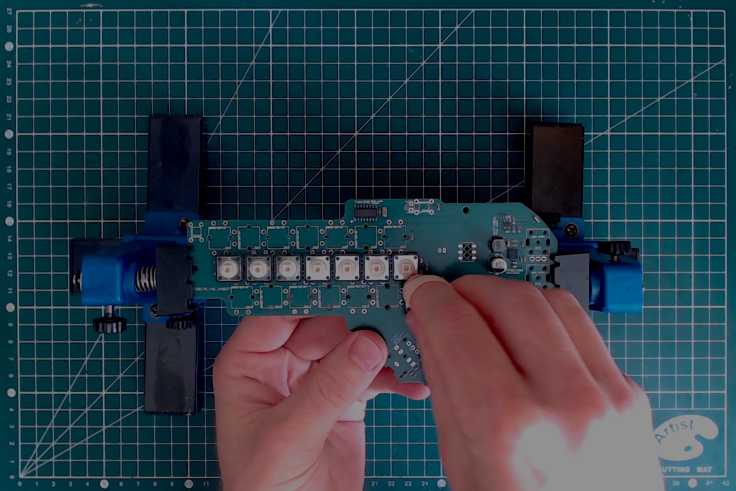
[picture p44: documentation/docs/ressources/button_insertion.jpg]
putting the buttons in place


They need to be pushed firmly onto the PCB to properly latch. Make sure that they are all in place and seating flat before starting the soldering. 

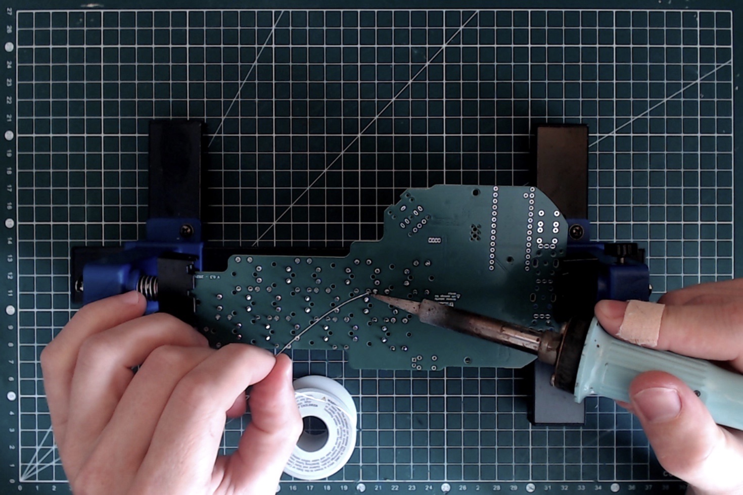
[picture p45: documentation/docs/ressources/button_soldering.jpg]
soldering the buttons


### 6x6mm pushbuttons

The process is very similar to the 12x12mm button. First insert all the four pushbuttons, making sure they are fully seated before soldering.

Once done your PCB should look like this:

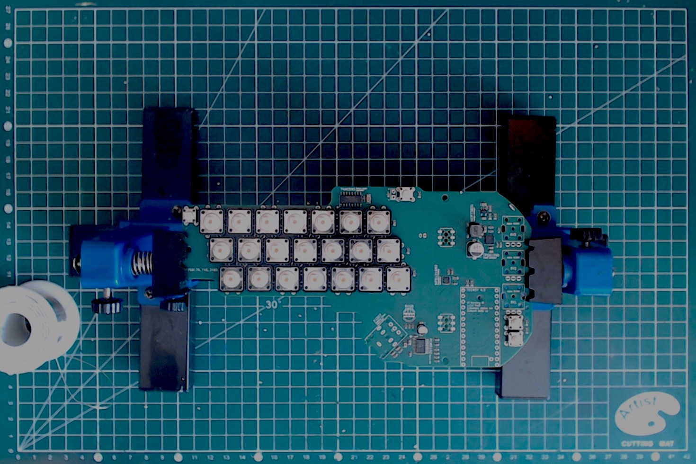
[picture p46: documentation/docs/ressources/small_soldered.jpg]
after soldering all the buttons


## Audio jack soldering

As before, make sure the jack is fully seated before soldering. 

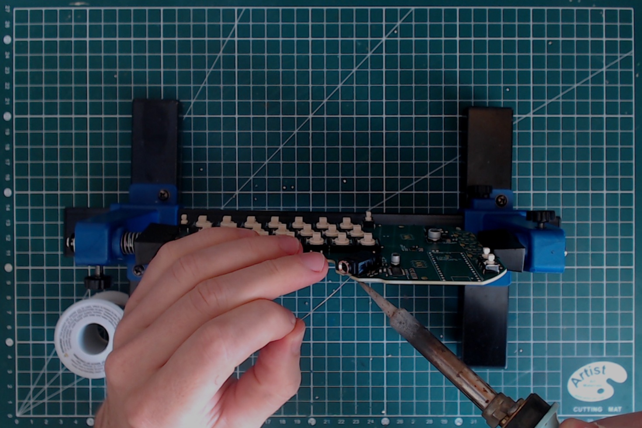
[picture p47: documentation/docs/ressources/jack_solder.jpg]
soldering the jack


> Note: in PCB v0.3 and before, it is necessary to:

> * cut the top left contact of the Audio jack before soldering (when looking from the top of the PCB, with the jack entry at the bottom);
> * add  a 10k pulldown resistor between the enable and ground pin of the jack (both at the center of it).

## Led soldering 

Two leds need to be soldered. 

**First the RGB led**. The provided led is a RKGB led. Those letters indicate the order of the pins, with R, G and B for the individual colours and K for the common cathode. The K pin is the longest and the position of each pin is indicated on the PCB itself. 

The RGB led needs to be fully seated in place before soldering. 

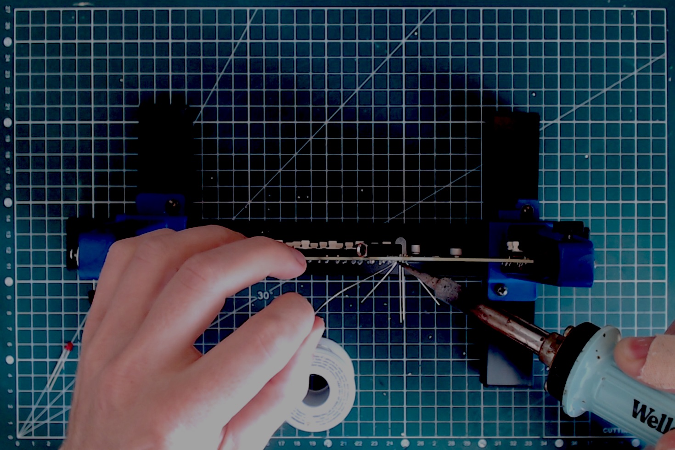
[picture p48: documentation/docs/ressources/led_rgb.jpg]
soldering the RGB led


Once soldered, cut the lead flush with the diagonal cutter. 

**The next one is the red led**. The longest pin is the +, and the position of each pin is indicated on the PCB itself. 

This led should not be fully seated. the top of the led should be about the level of the top of the pushbutton next to it.

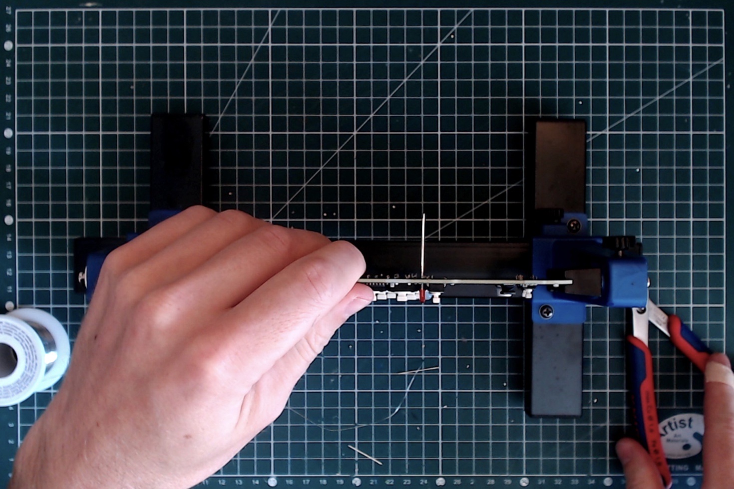
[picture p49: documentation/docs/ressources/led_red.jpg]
soldering the red led


Once soldered, cut the leads flush with the diagonal cutter. 

## Header soldering

Now we need to solder the female header that will allow the touch PCB to connect. 

Those headers are really SMD components but they are really easy to solder. Just put them in place, making sure they are flush (they should hold in place) and solder each pin. 

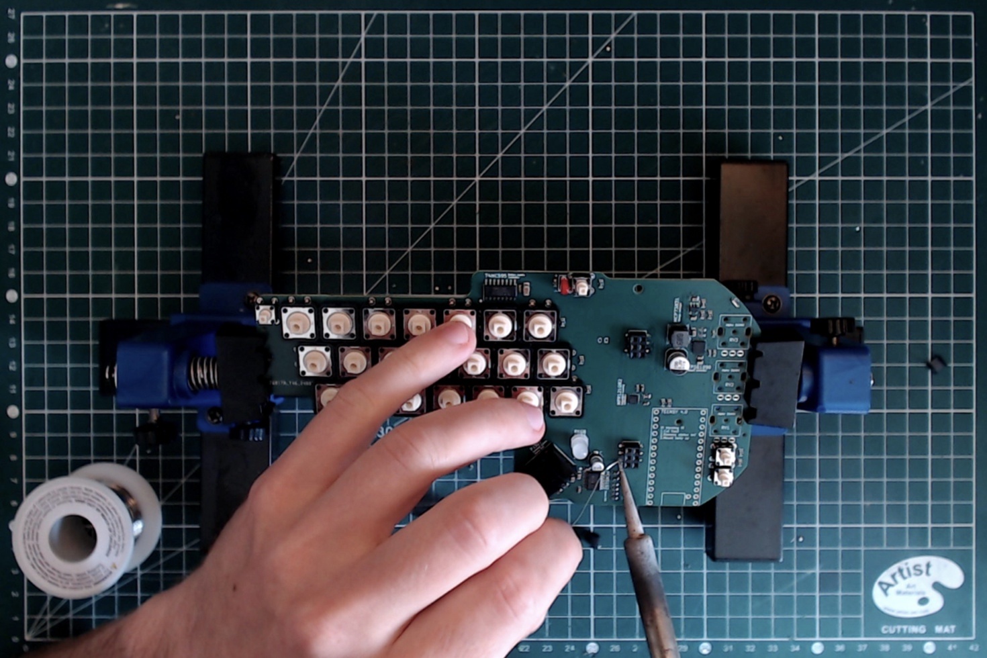
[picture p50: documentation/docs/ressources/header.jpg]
soldering the headers


## Teensy soldering

First prepare the headers using the X-acto knife. You will need:

* Two 14-long header strip for each side of a Teensy;
* A lone header for the out-of-row contact for the VUSB pin. If you are unsure which pin it refers to, take a moment to look at the [Teensy pinout card](https://www.pjrc.com/teensy/card10b_rev2_web.pdf) to identify it and locate its position on the PCB. **Failure to place correctly that header will keep the battery from charging.**

Now you can place the headers on the board, with the short length on the Teensy's side. **Position the Teensy, belly up**, and make sure it is correctly seated. You can then solder the two end of each header line to "tack" the header in place. 

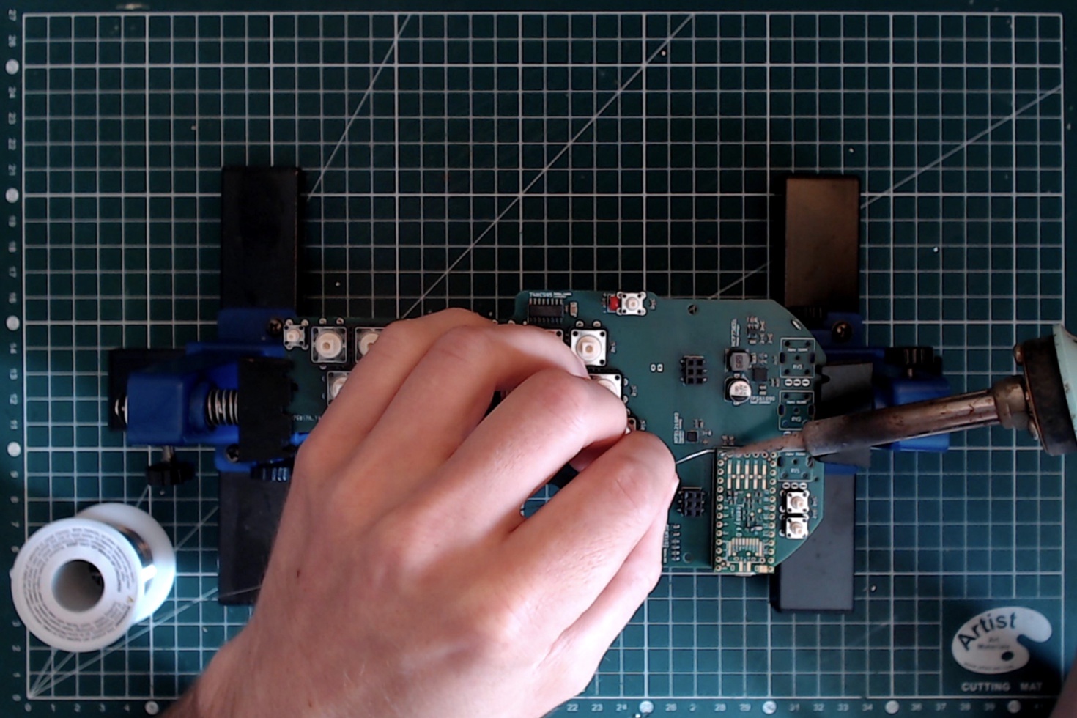
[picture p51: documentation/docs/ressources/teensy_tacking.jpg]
tacking the Teensy


Check that the Teensy is well seated, then do the same on the PCB's side. After a final check that the Teensy is well seated, you can then go over all the contact, both on the Teensy and on the PCB's side and solder them. **Don't forget to solder the VUSB pin**. 

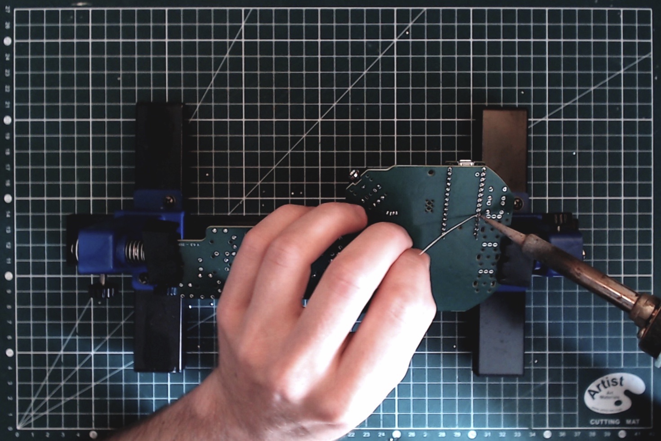
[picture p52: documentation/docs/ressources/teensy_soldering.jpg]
soldering the Teensy


## Potentiometers

First place the three potentiometer. 

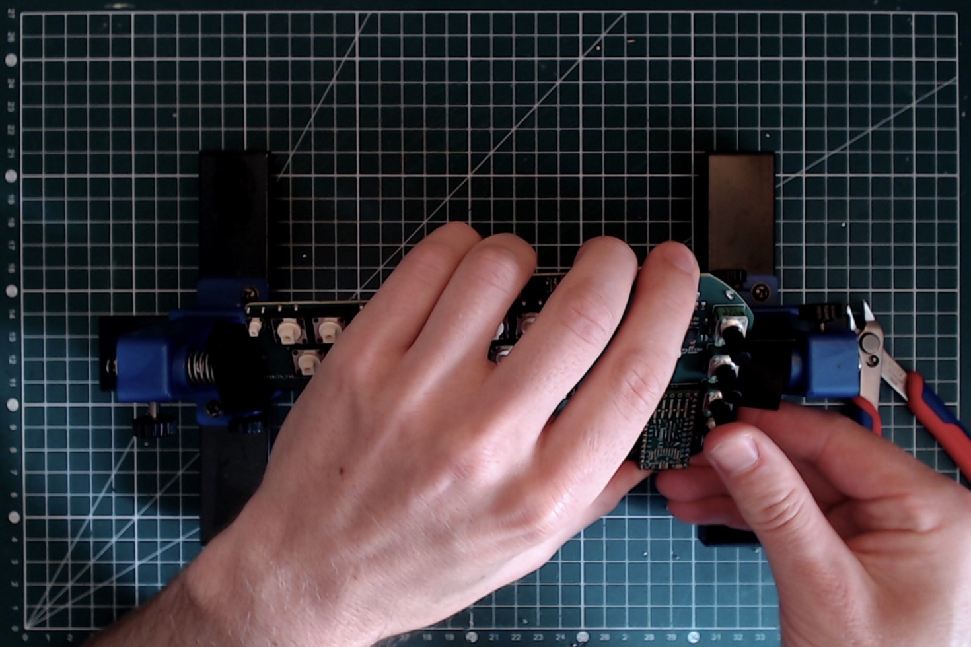
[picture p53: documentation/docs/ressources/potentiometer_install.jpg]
installing the potentiometers


Note that a low-profile trace is used, which means that the potentiometer sit deeper than they usually would. Make sure that they are fully seated. 

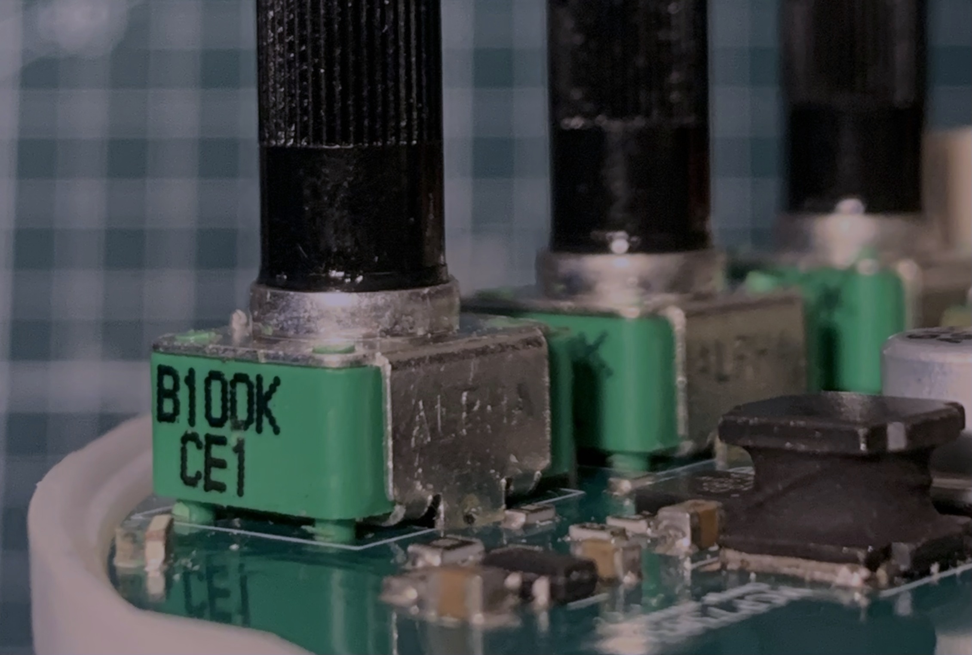
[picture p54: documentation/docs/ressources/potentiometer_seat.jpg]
well seated potentiometer


They will hold in place while you solder them. 

## Battery connector

This component is on the backside of the PCB. The silkscreen show the correct position for the connector, so place it accordingly.

**If the connector is installed backward and the battery is connected that way, it will destroy the device**. You need to make sure that when the battery will be connected, the polarity will be respected. 

positionning the connector

> Note: If you purchased the battery yourself, you need to make sure the connector attached to it is not reversed, as it sometimes happen. In that case choose the orientation of the connector to solder to make sure that the red wire of the battery indeed is connected to the positive side (following the silkscreen marking). 

## Cutting excess leads in the battery zone 

On the backside on the PCB note a white silkscreen rectangle showing the position of the battery inside the enclosure. 

battery zone

Using diagonal cutters, make sure to cut any leads whithin that white rectangle that is protruding more than 1mm. This is to avoid having those leads touch the battery pouch and potentially damage them 

cutting excess

## Soldering of touch zone PCB

The last bit of soldering needed is the headers on the touch zone PCB. Once again, those are technically SMD components, but easy enough to solder. Just make sure they are well aligned. 

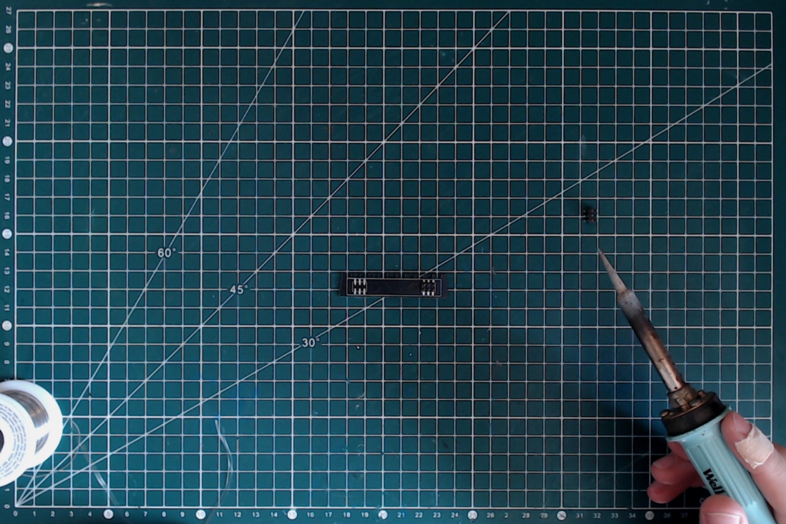
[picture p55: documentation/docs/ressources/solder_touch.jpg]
touch zone pcb soldering


# **Firmware uploading**

<details>
    <summary> <b>BOM</b> </summary>
    <ul>
<br>
<li>Fully assembled minichord PCB; </li>
<li>503450 1000mAh battery;</li>
</ul>
</details>
<details>
    <summary> <b>Tools</b> </summary>
    <ul>
<br>
<li>Micro USB cable (make sure it supports data transfert); </li>
<li>Computer (whether Windows, OSX or Linux);</li>
<li>Headphones;</li>
</ul>
</details>
<hr>

## Testing the board

First it is necessary to make sure the board is properly functioning. 

Without plugging the battery, plug in the micro USB. The power status led should light up (green or red depending on the specific led model). 

first led test.

If it does not light up, one the most likely reason is that you forgot to solder the VUSB header. Go back to the [Through-hole soldering](#Through-hole_soldering) section and read carefully the part about the Teensy soldering. 

Then plug in the battery. **Make sure that the polarity is respected** (it should be the case if you followed previous instructions). This time the led will be red, indicating that the battery is charging. 

second led test.

## Installing the Teensy Loader Application

Next you need to install the application that will allow to upload the firmware. It is provided by PJRC and precise instruction for it are available [on their website](https://www.pjrc.com/teensy/loader.html).

Please note that if you have TeensyDuino installed, the Teensy Loader is included with it. 

## Uploading the firmware

To upload the firmware, please use the following steps:

* Plug the battery into the minichord;
* Plug in the micro USB cable between the minichord and your computer;
* Plug the headphone into the minichord 
* Open the Teensy Loader; 
* Download the hex file of the firmware from the [Source section](/source);
* Drop the hex file on the Teensy loader;

Once all those steps are done, use a header to push on the reset button of the Teensy through the PCB hole. 

resetting the Teensy

If you carefully followed those steps, the Teensy Loader will indicate "Download Complete" then "Reboot OK". The main colour led of the PCB should light up. 

the board if functionning

You can test it by putting the headphones to your hears and push one of the 12x12mm buttons. If you don't hear anything, check that the potentiometers are not turned fully counter-clockwise.

# **Enclosure manufacturing**

The enclosure is composed of two part, the top and the bottom shell. The STL file for those parts is available in the [Source section](/source).

> Note: This section show an earlier version of the enclosure

## Printing the parts

Depending on what equipment you have available, **you can choose different alternatives for manufacturing**. 

### FDM printing

If you have a FDM printer, you can use it to make the top and bottom shell. They fit comfortably on a 18x18cm bed. Make sure that you flip the objects to have the flat surface on the bed, no support is required for printing. 

Indicatively, on my Prusa Mini+:

* the top shell takes 2 hours to print on a 0.15mm layer height;
* the bottom shell takes 2 hours and 15 minutes to print on a 0.15mm layer height.

The result is satisfactory, though not great. 

FMD shells

#### SLA resin printing 

For better quality part, SLA resin printing is an economical alternative. Though the equipment is costly, multiple vendors offer affordable online printing services. 

It should cost less than 5€ per part for basic resin choices, for very qualitative parts. Currently 9600 resin is my favorite for a low cost and good quality. 

Resin shells

It also possible (for a cost around 1.5x to 2x) to print those part with a transparent resin. 

Transparent shells

Whether normal or transparent resin, it is possible to use GTC liquid dyes to dye the part, for a very good final result.

coloured shell

# **Final assembly**

<details>
    <summary> <b>BOM</b> </summary>
    <ul>
<br>
<li>Fully assembled minichord PCB; </li>
<li>Fully assembled touch zone PCB; </li>
<li>Keycap set; </li>
<li>503450 1000mAh battery;</li>
<li>Top and bottom shells;</li>
<li>6x M2.3x8 self-tapping screws;</li>
<li>3x M2.3x6 self-tapping screws;</li>
<li>Double-sided tape.</li>
</ul>
</details>
<details>
    <summary> <b>Tools</b> </summary>
    <ul>
<br>
<li>X-acto knife (or another precise cutter); </li>
<li>Phillips electronics screwdriver.</li>
</ul>
</details>
<hr>

## Marking the keycap 

The first row of keycaps need to be marked with the chord letters. If you have a CNC router, then it is possible to engrave the keycap with a 45° V cutter, using a V-carve mode. 

For Omron Keycap, I've found the following setting to be satisfying:

* 300 mm/min feed rate; 
* 150 mm/min plunge rate; 
* 10 000 rpm.

CNC engraving

Once the keycap are engraved, the engraving is filled using Markal "Lacquer fill-in" paint stick. The following steps are recommanded: 

* "sharpen" the paintstick with an X-acto to have a pointy end;
* overfill the engraving with color;
* wait for at last 15 hours for the paint to start solidifying;
* buff the surplus color out. Place a tissue paper flat on a table, and rub the keycap on it while maintaining it very flat to remove the color outside of the groove. You may need to do it in several passes, changing the tissue paper in between. To properly remove all remaining color, a few drops of isopropyl might help. 

keycaps

Alternatively, if you don't have a CNC router, you can look into UV DTF transfers. It is a cheap method to allow color tranfers that can work for details up to 0.5mm. 

Once you engraved keycap are finished, you can install all the buttons on the main PCB. 

The engraved buttons go on the first line, and the order is F,C,G,D,A,E,B from left to right 

all buttons installed

## Assembling the enclosure

Now the easiest step ! 

all components

To avoid any screw breakage, please follow closely the following instruction:

* Use a adequately sized screwdriver. In particular, if you screwdriver slips, it might strip the screw and make the assembly impossible;
* Pre-tap the holes on the top shell. To do that, use one of the three _small_ screw. Simply fully screw it into each one of the hole, then take it out. Repeat for each of the six holes. Do not use one of the long screw for that step.

Now to the assembly itself :

First add a strip of double sided tape on the battery to install the battery in the dedicated space on the bottom shell. 
install battery installing the battery

Then connect the battery to the PCB. Add a material on top of the battery to protect againt any contact (bubble wrap, foam board, etc.).
connecting the battery

You can then put the PCB in place (it should snap fit into place) and secure it with the three small screws. Be sure to not overtighten the screws: once you feel a resistance, it is enough. 

bottom installed

No install the top shell. Make sure that all keycap are well-aligned with their respective holes. Once it is the case, it should be easy to push the top shell in place. 

Secure the top shell with the six long screws. Be sure to not overtighten the screws: once you feel a resistance, it is enough. 

top installed

The last step is to install the touch zone PCB. Simply be carefull that the header are in their right place, and push it until it makes contact with the shell. 

finished

That's it, your minichord is done! No to use it, please refer to the ["manual" section](/user_manual)

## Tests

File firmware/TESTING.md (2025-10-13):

# MiniChord Firmware Testing Guide

This guide provides comprehensive information about testing the MiniChord firmware.

## Overview

The MiniChord firmware uses a hybrid testing approach:
- **Unit tests** for pure logic functions (chord calculations, serialization, etc.)
- **Integration tests** (future) for hardware interaction simulation
- **Manual testing** for actual hardware functionality

## Test Framework

We use [Unity](http://www.throwtheswitch.org/unity) as our test framework, which is:
- Lightweight and suitable for embedded systems
- Well-integrated with PlatformIO
- Simple to write and understand

## Running Tests

### Prerequisites

- PlatformIO Core or PlatformIO IDE (VSCode extension)
- Python 3.7+

### Command Line

```bash
# Run all tests
cd firmware
pio test -e native

# Run specific test
pio test -e native -f test_chord_logic

# Run tests with verbose output
pio test -e native --verbose
```

### VSCode

1. Install PlatformIO IDE extension
2. Open the firmware folder
3. Click the PlatformIO icon in the sidebar
4. Navigate to "Test" → "native"
5. Click "Test All" or select specific tests

## Test Organization

```
firmware/
├── test/
│   ├── test_chord_logic/
│   │   └── test_chord_logic.cpp      # Chord calculation tests
│   └── test_serialization/
│       └── test_serialization.cpp     # Serialization tests
├── src/
│   ├── chord_logic.cpp                # Testable chord logic
│   └── main.cpp                       # Main firmware
└── include/
    └── chord_logic.h                  # Chord logic interface
```

## Current Test Coverage

### Chord Logic (`test_chord_logic`)

Tests the core musical functionality:

- ✅ Basic chord construction (major, minor, 7th, etc.)
- ✅ Sharp modifier behavior
- ✅ Flat modifier behavior
- ✅ Slash chord functionality
- ✅ Different root notes (circle of fifths)
- ✅ Harp chromatic mode
- ✅ Harp chord mode

**Example:**
```cpp
void test_c_major_root_position(void) {
    uint8_t note = calculate_note(
        0,                              // voice 0 (root)
        ChordTypes::MAJOR.notes,        // C major chord
        TEST_PATTERN_ROOT_POSITION,     // voicing pattern
        1,                              // C in circle of fifths
        0, 0, false, false, false
    );
    TEST_ASSERT_EQUAL_UINT8(28, note);  // Expected MIDI note
}
```

### Serialization (`test_serialization`)

Tests parameter storage format:

- ✅ CSV deserialization
- ✅ Negative value handling
- ✅ Empty string handling
- ✅ Boundary conditions
- ✅ Partial data handling

## Writing New Tests

### 1. Create Test Directory

```bash
mkdir firmware/test/test_my_feature
```

### 2. Create Test File

`firmware/test/test_my_feature/test_my_feature.cpp`:

```cpp
#include <unity.h>
#include "my_feature.h"  // Include the code you're testing

void setUp(void) {
    // Runs before each test
    // Initialize test fixtures here
}

void tearDown(void) {
    // Runs after each test
    // Clean up here
}

void test_my_feature_basic(void) {
    // Arrange
    int input = 5;
    
    // Act
    int result = my_function(input);
    
    // Assert
    TEST_ASSERT_EQUAL_INT(10, result);
}

void test_my_feature_edge_case(void) {
    TEST_ASSERT_EQUAL_INT(0, my_function(0));
}

int main(int argc, char **argv) {
    UNITY_BEGIN();
    RUN_TEST(test_my_feature_basic);
    RUN_TEST(test_my_feature_edge_case);
    return UNITY_END();
}
```

### 3. Extract Testable Code

If testing existing code in `main.cpp`, extract it to a separate module:

1. Create header in `include/my_module.h`
2. Create implementation in `src/my_module.cpp`
3. Make functions pure (no global state if possible)
4. Use parameters instead of globals

**Before:**
```cpp
// In main.cpp - hard to test
uint8_t global_value = 5;

void do_something() {
    global_value = global_value * 2;
}
```

**After:**
```cpp
// In my_module.h - easy to test
uint8_t calculate_something(uint8_t input);

// In my_module.cpp
uint8_t calculate_something(uint8_t input) {
    return input * 2;
}
```

## Testing Best Practices

### 1. Test One Thing
Each test should verify one specific behavior:

```cpp
// Good
void test_major_chord_root_note(void) {
    uint8_t note = calculate_note(/* params */);
    TEST_ASSERT_EQUAL_UINT8(expected, note);
}

// Avoid
void test_all_chords(void) {
    // Testing multiple things in one test
}
```

### 2. Use Descriptive Names
Test names should describe what they test:

```cpp
void test_c_major_with_sharp_modifier(void) { /* ... */ }
void test_slash_chord_replaces_bass_note(void) { /* ... */ }
```

### 3. Follow AAA Pattern
- **Arrange**: Set up test data
- **Act**: Call the function
- **Assert**: Verify the result

```cpp
void test_example(void) {
    // Arrange
    uint8_t input = 5;
    uint8_t expected = 10;
    
    // Act
    uint8_t result = my_function(input);
    
    // Assert
    TEST_ASSERT_EQUAL_UINT8(expected, result);
}
```

### 4. Test Edge Cases
Don't just test the happy path:

```cpp
void test_boundary_max_value(void) { /* ... */ }
void test_boundary_min_value(void) { /* ... */ }
void test_null_input(void) { /* ... */ }
void test_empty_array(void) { /* ... */ }
```

## Common Unity Assertions

```cpp
TEST_ASSERT_TRUE(condition)
TEST_ASSERT_FALSE(condition)
TEST_ASSERT_EQUAL_INT(expected, actual)
TEST_ASSERT_EQUAL_UINT8(expected, actual)
TEST_ASSERT_EQUAL_FLOAT(expected, actual)
TEST_ASSERT_NULL(pointer)
TEST_ASSERT_NOT_NULL(pointer)
TEST_ASSERT_EQUAL_STRING(expected, actual)
TEST_ASSERT_EQUAL_MEMORY(expected, actual, length)
```

## Continuous Integration

Tests run automatically on GitHub Actions:
- On every push to `main` or `develop`
- On every pull request
- When firmware files or test workflow change

See `.github/workflows/firmware-tests.yml` for configuration.

## Future Testing Goals

### Short Term
- [ ] Add tests for rhythm mode logic
- [ ] Test waveshaper calculation
- [ ] Test frequency calculation functions

### Medium Term
- [ ] Mock hardware interfaces for integration tests
- [ ] Test MIDI message handling
- [ ] Test preset save/load logic

### Long Term
- [ ] Hardware-in-the-loop testing with Teensy
- [ ] Automated regression testing
- [ ] Performance benchmarks

## Troubleshooting

### Tests Won't Run

**Issue:** `pio: command not found`
**Solution:** Install PlatformIO:
```bash
pip install platformio
```

**Issue:** Compilation errors in native environment
**Solution:** Check that you're not including Arduino-specific headers in test files

### Tests Fail After Code Changes

1. Check if the logic changed intentionally
2. Update test expectations if behavior is correct
3. Fix the code if tests reveal a regression

### Adding New Dependencies

If tests need external libraries:

1. Add to `platformio.ini` under `[env:native]`:
```ini
[env:native]
platform = native
test_framework = unity
lib_deps = 
    your-library-name
```

## Contributing

When submitting PRs with firmware changes:

1. ✅ Run tests locally: `pio test -e native`
2. ✅ Add tests for new features
3. ✅ Update tests if changing behavior
4. ✅ Ensure CI passes
5. ✅ Document any new test patterns

## Resources

- [Unity Documentation](https://github.com/ThrowTheSwitch/Unity)
- [PlatformIO Testing Guide](https://docs.platformio.org/en/latest/advanced/unit-testing/index.html)
- [Test-Driven Development in Embedded C](http://www.throwtheswitch.org/tddec) (Book)

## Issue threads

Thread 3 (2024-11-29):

Adding MIDI out support

BenjaminPoilve, 2024-11-29:
Add a MIDI output per section through the USB mini.
One MIDI output will concern the chords, another one the harp section. It will be possible to assign each independently to a virtual instrument.
Due to hardware limitation, MIDI through the 3.5mm jack won't be available.
This is a high priority feature request.

BenjaminPoilve, 2024-12-19:
The first version is quite solid: https://www.instagram.com/reel/DDwwJMjsYrI/
Leaving the issue open for feature requests.

Closed 2025-01-05.

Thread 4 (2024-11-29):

Add reset hole on the bottom shell 3D model to allow for easy firmware update

BenjaminPoilve, 2024-11-29:
By adding a reset hole on the 3D model, it will allow user without a VScode environment to upgrade the firmware simply with the TeensyLoader.
Useful for production version.

Closed 2025-01-05.

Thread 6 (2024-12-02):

The MPR121 capacitive touch sensor controller is discontinued

sampsonlau, 2024-12-02:
The MPR121 capacitive touch sensor controller by NXP was discontinued in 2019, and most distributors no longer carry it. Recommend replacing with a controller that is actively manufactured and supported. I am not aware of any pin-compatible replacements, so a PCB design update may be necessary.

BenjaminPoilve, 2024-12-02:
Hi!
Indeed it was dropped from production by NXP. This is the reason why the initial version of the minichord used something from the AT42QT line, but the 16ms update cycle was really too slow (compared to 1ms for this one).
The good news is that, from my understanding, the license has been sold to Resurgent Semiconductors in 2015.
[Arrows shows 542598 parts available](https://www.arrow.com/en/products/mpr121qr2/resurgent-semiconductor-llc), so we might be ok for a while.
If anybody knows alternative parts though, I'm all hears!

sampsonlau, 2024-12-02:
Ah, the AT42QT was actually the closest thing I found that's in production. Good to know Arrow still has stock, but I'm not a fan of the 1000-qty minimum order increment. 😅

BenjaminPoilve, 2024-12-02:
We can make a grouped order, I know this chip is quite popular with DIYers (and rightly so, it is great) :)

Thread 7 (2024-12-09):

Extraneous openings on solder paste stencil between R3 and R7

sampsonlau, 2024-12-09:
In the space between R3 and R7, there appears to be an extra pair of openings on the solder paste stencil that does not align with any solder pads. In the attached image, they are the solder pads highlighted in yellow.
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

BenjaminPoilve, 2024-12-09:
Well that's a careful review you did to catch that :)
Yes indeed it should not be on paste. This does not cause any issues, because that footprint is simply used to bridge ground and power ground on a single point.
I'll fix it shortly!

BenjaminPoilve, 2024-12-15:
Will be removed in the next commit

Closed 2024-12-15.

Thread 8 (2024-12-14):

Numbers file BOM lists the screws differently from everywhere else

sampsonlau, 2024-12-14:
full_BOM.numbers lists 9 M2.3x8 screws, but full_BOM.csv and full_BOM.pdf list them as 6 M2.3x8 screws and 3 M2.3x4 screws. Additionally, the assembly instructions on the website mentions 6 long and 3 short screws, which is consistent with the CSV and PDF files, but not the Numbers file.

BenjaminPoilve, 2024-12-15:
Thanks for the catch. Will be updated in the next commit !

Closed 2024-12-15.

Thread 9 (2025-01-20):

SMD LED

KeenVox, 2025-01-20:
Hi there,

I have trouble finding the correct dual smd led on mouser, digikey etc,

Could you provide a part number, link or description of that part? :-)

KeenVox, 2025-01-20:
Hi Ben,
thx!
I think I found the equivalent on mouser:

https://www.mouser.de/ProductDetail/Kingbright/APFA3010R2G2C-C6-AMT?qs=amGC7iS6iy%2F4sATRKhbw8A%3D%3D

KeenVox, 2025-01-20:
Ah, nevermind. The pinout doesn't match.

KeenVox, 2025-02-08:
So I'm here again. I've got some problems with the status leds. I hooked some up like in the schematic. But the green LED is always on. The red LED is on, when I plug in the USB power but very dim.

Anything I'm missing here?

BenjaminPoilve, 2025-02-08:
Hello again,
Huum I see two options:
- Do you have the battery plugged in? If not the controller will blink both led, which can gives strange results
- Those led are a pain to solder. It is very easy to create short circuit (event making sure it is the right orientation and it is not upside down is no small task). I've had situations where I had to give up reworking a led because I just did not managed to do it with a solder (and the board could not be reflow).

KeenVox, 2025-02-08:
Hey, I found the problem. My msitake. I bought a MCP73832 instead of a MCP73831. The former one has a open drain on the STAT pin. I assume that's the problem. Will see, when the new 831 arrives.
As for the LED In used some normal 3mm LEDs and soldered those to the resistors as I was not able to buy the needed Bi-Color LED on any other source. :)

BenjaminPoilve, 2025-04-20:
BOM has been updated, so I close :)

Closed 2025-04-20.

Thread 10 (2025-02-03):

Sharp button crashes system

KeenVox, 2025-02-03:
Hi,

I've got a problem with the minichiord. Everything works fine. The touch controls, buttons and pots.

But as soon as I press the sharp button together with a button of the first row the system seems to crash. The LED turns off and the system stays of as long as I hold the sharp and any other button of the first row together. When I let go the system resets and works again on the first preset.

Using the sharp button with the second or third row works fine.

What could be the cause?

BenjaminPoilve, 2025-02-03:
Hi,
That sure looks like a brownout that would be caused by a shorting of the 3.3V line to the ground.
Inspect the PCB for any soldering defect, and most importantly, reflect on what is below the PCB. It happened to me that pushing the button on the end of the PCB was enough to create flex in the PCB. The flex can make the leads of the pushbutton dig into the battery and create shorts.
Two solutions:
- Use a thick double sided tape as recommanded in the instruction for the old version
- For the new version, the battery has been moved around to avoid that issue altogether.
Let me know how that goes.
Regards,
Ben

KeenVox, 2025-02-03:
Hi Ben,

I don't have the the battery connected. I get power over USB directly from the Teensy, The pcb is outside of the case.
My soldering looks fine, I checked for continuity and can't find any obvious shorts. Measuring the sharp button in operation, I can see it gets 3.3V and goes to 0V when pressed.
It only resets when sharp and any button from the read matrix 1 are pushed together. Checking all buttons neither one goes to GND when pressed.
On the 74HC595 I also get no false ground connection. Only Pin 8 and 13 are connected to ground. :(

BenjaminPoilve, 2025-02-03:
Hi again,
Then we need to get into diagnostics mode :)
First it would be nice to confirm the brownout. The 3.3V regulator is on pin 31, ground on pin 1 of the Teensy. Maybe use a scope to confirm that the voltage is dropping when pressing both buttons?

Then, just a reminder of how this section of the minichord works. All the buttons of the first row (and the sharp) are connected to the output of the multiplexer. The other side is held high by a pullup resistor. The outputs of the multiplexer are held high, and get low one by one to detect which of the switches is pressed. Now this is a little unorthodox as you might notice there is no matrix diode. But due to the button patterns that are expected, there is no problem to detect what is happening.

Once thing that strikes me as odd is the fact that the sharp goes to zero when pressed. Technically it does not go to zero, it goes to the state of the output of the multiplexer that is zero 1/8th of the time.

In addition do you have an issue when you press two buttons from the first line at the same time? Does it cause the same brownout?

BenjaminPoilve, 2025-02-03:
(I'll check tonight to make sure I can't reproduce the issue, but it would be strange to detect it for the first time now when more than a few minichords are out there)

BenjaminPoilve, 2025-02-03:
To add: where did you buy your 74HC595 ? My design (maybe not so wisely) relies on the fact that when two state outputs are tied together, the current is limited. Maybe your chip has a different behavior? I might need to think about adding diodes on the 74HC595 pins to avoid that problem.

KeenVox, 2025-02-03:
Hey,

I checked the voltages on Pin31 on my scope. I've a little pulsing in it but minimum is 3,1V and max 3,3V. When sharp and another button a pressed it goes down to minimum  2.9V.
I rechecked the sharp button with my multimeter and it indeed goes down from 3.3V to 0V when pressed.
I checked the 3.3.V and 5V Pin also. Nothing changes there.
When two buttons are pressed the led on the teensy and the big status led on the board go out. In my headphones I can hear a kind of pulsing sound.
It only happens when the sharp button and one button of the read matrix (1-7) are pressed toghether. All other button combination don't show that behaviour.

I attached two pictures from my board. The smd parts are hand soldered but all values are correct and continuity is where it should be. :) No shorty to be found anywhere.
HC
My 74HC595D is from NXP. I only checked the pinout against an TI 74HC595 and at least those a lining up correct.

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

BenjaminPoilve, 2025-02-03:
I'll give it more thoughts this evening, but I have to say, that is some impressive soldering! Your board looks cleaner than mine :)

Since it only happens with the sharp when all the button of the line and the sharp are similarly wired, it seems to indicate it is something else that a different 74HC595 behavior..

KeenVox, 2025-02-03:
Thanks, I have some projects on my belt ;)

I went the mile and desoldered all the buttons from the first row an even desoldered the teensy aaannd cut the led trace juuust to be sure.
I just used tweezers for the chord buttons but it still crashes when I press the sharp button. :(

BenjaminPoilve, 2025-02-03:
The trouble seems to be that the sharp is connected to ground. It should not be.
Here is the pinout of the chip

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

Could there be a bridge between the two right bottom pin? Or below the chip itself?

KeenVox, 2025-02-03:
I checked the pins, at least with power off there is no false GND connection. The switch itself has no continuity to GND also, pressed nor unpressed.

I think I have to go the exclusion process and will swap the 595. Sadly of all the parts in my stash I only had one piece. So will take a day or to two till I can try that. Hope it's simply the IC. Can't think of another error. I checked all the traces to the teensy and even desolderen all the row 1 buttons.

The only thing that is not connected is the battery as I'm waiting for the right one to be delivered, but I can't think of that as the problem...

BenjaminPoilve, 2025-02-04:
Well I'm sorry about the experience, it is not great :(
Reflecting a bit more about it, there is something special about that sharp button. When looping over the buttons, the last one in the loop is the sharp, so it stays to the ground until the next button poll. Why that would cause a short in your situation, I'm not sure, but to see if that could be a cause, I'll modify the firmware to put the pin back up after polling. Try it and let me know if that fixes your situation.

KeenVox, 2025-02-04:
Thx, will try, when I'm back home tonight. :)

We'll get it too work, I'm sure.

Am 4. Februar 2025 07:00:27 schrieb BenjaminPoilve ***@***.***>:
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

KeenVox, 2025-02-04:
Hey, good news,

everything is now working like it should. Thank you!

BenjaminPoilve, 2025-02-05:
That's a good news! For my understanding, that is with the firmware fix?
If that is the case, I still have to do a PCB run with added diodes to test. Running outside of specs is never great!

BenjaminPoilve, 2025-02-05:
Thanks!

And in particular, thanks for building a minichord and raising that issue. That'll help me better the design :)

Hope you'll have fun, and don't hesitate if you got features you want to be added!

KeenVox, 2025-02-05:
Thank you for designing this.

I know what a hassle it can be to design pcbs :-D

Sadly I fried my Teensy yesterday after attaching the battery. Will have to
sort that out. Hopefully this won't be such a hassle as the sharp button ;)

Am 5. Februar 2025 08:45:52 schrieb BenjaminPoilve ***@***.***>:
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

BenjaminPoilve, 2025-02-05:
Oh. Did you plugged the battery in reverse? Happened to me once, and fried both the Teensy and the battery controller. Unfortunately, I did not find an easy way to defend against this, as most simple solutions have significant drawbacks. I tried to make it clear on the silkscreen, but if you have advice to apply poka yoke here, I'm all ears!

KeenVox, 2025-02-05:
No, I tripple checked. Don't really know what happened. Maybe a short I
didn't see. I rechecked everything but seems to be fine.

Only thing I noticed was that I have a v0.3 pcb and forgot to clip the
jacks pin and solder a 10K to the enable. Don't know if that could be the
cause?

For the protection, I think that will get complicated fast. Normally I
would simply use a diode in series or a mosfet but here we have the
charging circuit as the problem.
I think that would need a bit more effort...

Am 5. Februar 2025 13:13:08 schrieb BenjaminPoilve ***@***.***>:
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

BenjaminPoilve, 2025-02-06:
It could be the cause, as some switched jack are "make before break switch", which would short the GND and Battery power when plugging in. This is the reason for the later revision, that does not connect GND, but pulls the enable pin of the power chip with a resistor. Indeed earlier PCB need that modification.

Thanks to your feedback I made an update to the PCB to add diodes to the multiplexer. Should be more sturdy :)

BenjaminPoilve, 2025-02-06:
Thanks :)

Yep, I have added it to the repo as well, it is the "Keymaster" PCB. When I have the time I'll make a Kicad template so people can design their own custom touchplate!

KeenVox, 2025-02-06:
Great. Will look into it. :)

Am 6. Februar 2025 09:45:37 schrieb BenjaminPoilve ***@***.***>:
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

BenjaminPoilve, 2025-02-07:
With the latest commit, I've added better gerber (with silkscreen) for the widest touchzone, and an easy to modify kicad template for custom touchzones.

KeenVox, 2025-02-07:
Perfekt! Thx!

BenjaminPoilve, 2025-04-11:
I'll close this issue since added diodes for the next version make the initial crash impossible, even with original code.

KeenVox, 2025-04-11:
Good to know. Will my pcb without the diodes be still compatible if you
update the firmware any further? Or will you remove the fix from it?

Am 11. April 2025 07:28:44 schrieb BenjaminPoilve ***@***.***>:
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

BenjaminPoilve, 2025-04-11:
There is no reason to roll back the change, so you'll stay compatible :)

Closed 2025-04-11.

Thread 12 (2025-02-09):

Change strum zone size

BenjaminPoilve, 2025-02-09:
Following feedback on the fact that the current shape makes it easy to scrape the edge of the touch plate, there is a need to widen the top and bottom clearance between pads and edge of the touchplate

YonkRaccoon, 2025-04-10:
To diverge from this topic, is there a digital parameter to change the "strum range" of a synth preset? For example, making it so strumming across the sensors only span 4, or even 2 notes? It would be useful for recording specific kinds of parts to my songs.

BenjaminPoilve, 2025-04-11:
To update on the initial issue, the version that will be produced by Seeed will have a slightly larger touch zone size. I'll upload the updated files later.
For your second question, the notes associated to each of the strum zone is indeed user-settable, per preset. It is defined [here](https://github.com/BenjaminPoilve/minichord/blob/36667c45511398d1447d1aac58f1e4aa2e58a66f/firmware/src/main.cpp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).
If you look at the [minicontrol interface](https://minichord.com/minicontrol/), parameter 40, you can see the related control.

YonkRaccoon, 2025-04-11:
Thank you for linking the minicontrol interface! I had no idea we had access to it already before public release. You are truly going open source, which is something I don't get to dabble with much yet in my life.

**As for changing the PCB, where can someone like me buy the plate which you tap the dots for notes?** I saw it in an early demo video in the past and didn't know if it was sold ready-made somewhere.

That's my last question in this topic! <3

terminalwaltz, 2025-06-21:
@YonkRaccoon I'm also interested in a keymaster strum plate: really want to see how it performs with Barry Harris mode. I've used JLCPCB as a service in the past: I'm pretty sure they have at least a 5 PCB minimum, and I have no use for 5 touch plates.

If you'd like, I'll let you know when I've got a batch and I can send you one. I remember their turn around time was pretty good in 2021, hopefully that hasn't changed.

terminalwaltz, 2025-06-21:
@YonkRaccoon Order placed! Let this post be a placeholder, I'll update when I get the boards and then we'll have an average time of the complete build/shipping for anyone in the future who wants to order (to the eastern US, at least). Cool time to be a gadget nerd :D

terminalwaltz, 2025-06-21:
No, I ordered 5 PCBs for the keymaster strum plate because the company that is going to print them (JLCPCB) requires a minimum of 5 to fill an order. So they're gonna send me 5, and I can't imagine a scenario in which I would need all 5. This is such a niche community, and I saw that you were also interested in the keymaster plate, so I figured I'd offer to send you one.

The total cost for printing the 5 PCBs was a whopping $6.05, after tax and shipping. And I'll solder some headers on there for you, if you'd like, easy stuff. I just think it would be neat to make a total stranger happy in this very odd, very specific way 😄

For that matter, I'll have another 3 left over, but I'm not trying to start a riot. But if anyone else wants one, I'm happy to send them out!

YonkRaccoon, 2025-06-22:
Aw, dude that rules. I relate cause I would try to do the same if I had the resources currently. I feel very lucky to be vocal right now about my passions

Sent from Proton Mail Android

-------- Original Message --------
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

BenjaminPoilve, 2025-06-22:
Hi there! Just in case anyone has doubt, this is fully OK to manufacture, share, or sell alternative touchplates. You have my express permission to do so :)
Thanks for helping out another user @terminalwaltz!

YonkRaccoon, 2025-06-29:
> For your second question, the notes associated to each of the strum zone is indeed user-settable, per preset. It is defined [here](https://github.com/BenjaminPoilve/minichord/blob/36667c45511398d1447d1aac58f1e4aa2e58a66f/firmware/src/main.cpp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). If you look at the [minicontrol interface](https://minichord.com/minicontrol/), parameter 40, you can see the related control.

Now that I have my minichord, I'm making something as close as possible to an acoustic guitar (ideally wanting to make something as satisfying as the electronic guitar in the soundtrack from the Stray game.)

My goal is to make the harp hit only 6 or 8 notes throughout its entire contact. Do I need to learn how to edit this code in order to reduce the harp strum range? So far, this parameter is useful but only changes what notes the harp will include on its journey.

YonkRaccoon, 2025-06-29:
> [@YonkRaccoon](https://github.com/YonkRaccoon) I'm also interested in a keymaster strum plate: really want to see how it performs with Barry Harris mode. I've used JLCPCB as a service in the past: I'm pretty sure they have at least a 5 PCB minimum, and I have no use for 5 touch plates.
>
> If you'd like, I'll let you know when I've got a batch and I can send you one. I remember their turn around time was pretty good in 2021, hopefully that hasn't changed.

Just to let you know, I finaly recieved my minichord and am working on my first niche presets to make very interesting things, with where the software is at so far. You can reach me here about the PCB shipment stuff or the contacts on the bottom of my WIP github website!

BenjaminPoilve, 2025-06-29:
>My goal is to make the harp hit only 6 or 8 notes throughout its entire contact. Do I need to learn how to edit this code in order to reduce the harp strum range? So far, this parameter is useful but only changes what notes the harp will include on its journey.

We would need to discuss how we'd like to do it. It would mean that some contact would not fire. So the question would be: which ones? An alternative would also be to do a touch zone with less zones, and that would need no code modifications.

>[A Stray Guitar.txt](https://github.com/user-attachments/files/20968147/A.Stray.Guitar.txt)
Nice! Would you like it on minishop as well?

YonkRaccoon, 2025-06-29:
This GitHub is getting me inspired to actually record video and demonstrate different presets and hardware concepts!

I'll try to form a good reply to some things soon, through video or text.

I will reiterate that I'm coming purely from a musician/player side when it comes to Minichord features. I don't know the technological or programming side of anything technical, but I have a lot of ideas based on expressive live performance & experimenting with multiple instruments.

-------- Original Message --------
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

terminalwaltz, 2025-07-06:
@YonkRaccoon The keymaster plates arrived yesterday! I'll be back home this afternoon to solder up and try them out. Shoot me an email with your details and I'll get you one mailed out this week:

terminalwaltz@gmail.com

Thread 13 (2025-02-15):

Feature: hardware midi via TRS mini jack

arnoson, 2025-02-15:
First of all: this projects looks super exciting, I will definitely buy one :)
The hardware parts are probably already fixed, but I just wanted to mention that a dedicated midi output via 3.5mm port would be awesome for super simple setups. I imagine for example pairing the 0-Coast with the Minichord and not needing any computer/interface inbetween.

BenjaminPoilve, 2025-02-16:
Hi Arnoson,
Indeed at this stage it is a bit late to make important hardware modifications. I keep the need in mind for later projects, but for this one, given that I wanted to attain a very affordable result and simple package, choices had to be made on the features of the minichord. I decided to focus on onboard sound synthesis, with midi taking a secondary role only through USB.
Luckily there is currently quite a few USB midi to midi host device getting released, which should allow to fulfil your use case!
Closing the issue as a wontfix for this release, might be revisited if a version 2 comes up.

Closed 2025-02-16.

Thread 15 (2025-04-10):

Feature (Software:) Custom Startup Jingle

YonkRaccoon, 2025-04-10:
I'm a person who plays around a lot and was wondering if it was possible to create a short MIDI segment and put it into the minichord's brain so when you turn it on, it would play. This would either happen with the preset it turns on with or a specified preset. As I assume, this is such a small amount of data, so I was wondering if it was possible. Thanks for reading!

BenjaminPoilve, 2025-04-11:
Not impossible at all! We are still far from reaching the limit of what the Teensy can do.
When you say midi segment, you still would like for it to play on the audio output? Or only on the MIDI channels?
I think the need needs to be further explained: would it be a simple indicator that it turned on, or would you like to use it for musical purposes?

YonkRaccoon, 2025-04-11:
Yes-- to play a short, user-defined tune, on the audio output, when the power is turned on, so it feels an old Mac computer, haha. It would be an indicator, but I can see it being used to also play the first chord or notes of a song. If the minichord has an option to remember which preset synth you were last on, it could simply play the MIDI using that preset synth. But it would be ideal if you could assign which of the 12 preset synths play the MIDI.

If it had more "brain space" in its storage than I assumed, it would be truly ideal for each preset to have **its own** assignable measure of MIDI notes.

I mentioned "MIDI" as it is the only way I know how to "store audio" on the minichord, but maybe use arpeggio patterns are something other than MIDI and that format is also an option? I only know these topics on the consumer level, as I mostly compose with acoustic instruments.

Of course, I already preordered the minichord, so this feature doesn't decide whether or not I pay for it, but it would make me very happy continuing to use it!

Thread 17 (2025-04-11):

Feature (Software:) LED Color for Chord Buttons, Not Just Preset Banks

YonkRaccoon, 2025-04-11:
It's me again. I'll run out of wishes eventually! I just don't know how to program so I make topics like these.

I would very much appreciate **an option for the LED to temporarily change color depending on which chord button I'm holding**, if that doesn't pose a danger to the hardware.

_"Preset bank is purple > hold Cm > it turns blue > let go of Cm > it goes back to purple for the bank."_

For holding two chords, this might need to be ignored or have its own solution, but I'm more fixated on colors for single chords.

This would also help for those of us who think less about chord names and more their "flavor," like I do on piano. Electronic instruments are more natural to me with a good combination of light, sound, and texture. :3

BenjaminPoilve, 2025-04-20:
Hi there,
No problem at all! I've given it some thoughts and I'm a bit worried that, given the limited interface of the minichord, that might be confusing. Currently the colour of the led is the sole indicator of the current preset, which can lead to confusion. This is also the reason why I limited the number of internal presets to 12 while the teensy could store much more.

While I understand that the change would only be momentary, it would mean that one would need to stop playing to identify the current preset. For the sake of simplicity, I currently will keep the current color system, but if more voices support your proposal, I'm open to reconsider.

By the way, maybe color keycaps would be a better fit for your synaesthetic way of playing?

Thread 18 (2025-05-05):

SMD Layout PNG based on old design?

cassettetape1, 2025-05-05:
the PNG at documentation/site/ressources/smd_assembly/g66188.png (referenced in https://minichord.com/assembly/#smd-soldering) appears to be based on the old design of the board, with the 74HC595 on the top of the board, instead of between the strum zone and switches. It also omits the diodes that have been added next to 74HC595.
Thanks!

BenjaminPoilve, 2025-05-06:
Thanks, I exported the new image but forgot to add it here.
I'll update it as soon as I get behind my computer :)

BenjaminPoilve, 2025-05-06:
That's updated!
Thanks for noticing,
Ben

Closed 2025-05-06.

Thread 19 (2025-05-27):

first batch assembly issue (keycaps order and vbat connection) - fix procedure

BenjaminPoilve, 2025-05-27:
As minichords started to ship last week, this should be a happy time, **but unfortunately some issues with the initial batch has been identified which justify this thread** (and a very big thank you to those who did, especially Pierre from [nuancescontroller](https://nuancescontroller.fr/)). **It will serve as a guide to solve the issue and as a discussion zone for technical help.**

It seems that there has been mistakes in the assembly and procurement that affected those first unit dispatched. I cannot confirm yet if all units are affected, but I’m going to go with the assumption that it is the case. **Of course Seeed Studio immediately stopped shipping until the situation is resolved**. None of those issue were present in the engineering samples I reviewed. It is true though that no mistake happen in a vacuum, and I should have made sure that the process set up was thorough enough to catch those before shipping. “Trust but verify” proves once again a useful proverb.

### Scope of the issue

The identified errors are the following:

* **The order of the keycaps is wrong**. While current documentation and assembly document provided indicates that the order is F/C/G/D/A/E/B from left to right, the unit shipped use the older key scheme.

* **The bridge between the USB power supply and regulated internal power was not cut**. As a result, the minichord starts when plugged in to the USB port, which is not the expected behaviour and might impact charge time.

There is a final issue related to the size of the provided USB cable, which is too big to be used. On that, Seeed Studio confirmed that they will propose to ship a replacement.

### Confirm that your unit is affected

#### Keycap order
If your unit keycaps read, from left to right G/B/A/F/D/E/C, then the order is wrong. The right order is F/C/G/D/A/E/B.

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

#### Vbat bridging
To test if the unit is affected,  connect the minichord to a power source without plugging in a headphone jack. If both the charging led and the main minichord led turn on, then your unit if affected.

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

### Procedure to fix

**The procedure to fix both those issues is quite easy**. It takes about 10 minutes to do and require two things:

* An electronic (small) phillips screwdriver
* An X-acto/hobby knife/small cutter knife

I've recorded the steps to follow [in the video here](https://www.youtube.com/watch?v=eTFiQu6iImM), but please read the instruction carefully to ensure a proper fix.

#### 1 - Open the minichord

Turn over the minichord and locate the 6 screw holes. There is a seventh hole in the middle: this is the reset button, there is no screw here. Using an appropriately sized screwdriver, unscrew those screws. If your screwdriver cams out, then you have the wrong size.

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

You may need to tap gently the minichord for the screws to drop.

Once that is done, remove the touch zone. To do that use your nails to lift it, alternate from side to side to keep it even.

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

You can then remove the front enclosure easily.

#### 2 - Reorder the keycaps

For each keycap of the first line, use your nails to lift it up while using your thumbs to ensure it stays vertical. Wiggle it a bit until it pops out.  Start from the side to make it easier.

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

Once that is done, you can put them back in the right order (F/C/G/D/A/E/B).

#### 3 - Cut the Vbat bridge

This step can feel a little intimidating but it is really easy. Just make sur you have a hobby knife in good shape to facilitate the cutting. The Teensy is designed to allow this cutting, so there is a big pad just to that end.

First locate the pad using the reference picture below:

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

The red line shows where it needs to be cut.

Place the hobby knife there and apply pressure while moving a bit to allow cutting. As soon as you feel it is enough, you can plug the usb cable back to power it on. Then there is two option :
* If the main led turns on in addition to the charging led, then you need to cut more as there is still contact
* If not, then you are good to go
This test can be seen in the video.

#### 4 - Reassemble the minichord

Put back the front enclosure and screw the screws back on. Do not overtighten them: once you feel a resistance, that is enough.
Put back the touchplate, making sure the header pin are correctly aligned.

That's it!

### Closing words

While this is not exactly the first experience I hoped for minichord user, I hope this guide will make is as painless as possible. Thanks for bearing with us until all issues are ironed out (I might have to look into designing some “I’m sorry we messed up” special edition alternative touchplates). If you have any question, please use the thread as it might be useful to other users!

BenjaminPoilve, 2025-05-27:
This is not standard behaviour (and departure from my assembly instruction), so I had to work out last night what could be the effect.

- For sure there is the issue of the minichord being powered on while charging: it means that the charging will be slower, and it could impede the charge manager, keeping it from detecting the battery as full (because in practice it would never be). That could on the long term cause battery life issue if you leave it charging continuously.
- I've identified at least one situation where this blocks the charging: if the battery is totally empty, then the battery manager chip will wrongly read the battery as full (due to the voltage of the USB feeding back) so block the start of the charge. Removing then re-plugging the USB solves it.

I can't confirm that there won't be any more ill-effect. So my advice would be to do the fix, it is not complicated, the teensy is designed to do it, so if you are opening it up to switch the keycaps, might as well do it.

AlexVernanchico, 2025-05-27:
> I can't confirm that there won't be any more ill-effect. So my advice would be to do the fix, it is not complicated, the teensy is designed to do it, so if you are opening it up to switch the keycaps, might as well do it.

This is all very helpful. Thank you.

carlca, 2025-05-27:
> [@carlca](https://github.com/carlca), you need a micro USB cable. That was never used on Iphones, maybe you have relatives with an Android phone? Or devices that are a couple years old (e-readers, mp3 players, and so on).

Good thinking! By chance, I had an old Android Phone adapter, and it works. Now I have both lights showing, so I will have to attack my Minichord when my X-Acto knife arrives tomorrow 😉

BenjaminPoilve, 2025-05-28:
Sorry for the scary experience, and glad that you made it. Indeed the Teensy is designed to allow for this cutting so there is no other close trace, making it quite hard to mess up (and I have to thank Paul from PJRC for this great design)!

BenjaminPoilve, 2025-05-28:
@linzqqq, thank you very much for taking the time to report your experience! I'm glad this did not spoil your appreciation for the minichord :)
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
supergranular, 2025-06-02:
I've managed to remove one screw using a 00 Phillips head. The rest seem to have been tightened by a proverbial gorilla. Worried I'm going to ruin it, but can't see any other way other than brute force. Anyone else having this problem?

carlca, 2025-06-02:
> I've managed to remove one screw using a 00 Phillips head. The rest seem to have been tightened by a proverbial gorilla. Worried I'm going to ruin it, but can't see any other way other than brute force. Anyone else having this problem?

Have you tried with a PH0 head rather than a PH00 head? A PH0 worked perfectly for me, and at no point did I feel that there was any chance of shearing the screws.

BenjaminPoilve, 2025-06-03:
@supergranular sorry that you are having this issue. Did we discuss by email? I mentioned to somebody that maybe as a last resort, trying to make the screw colder by using compressed air can might help to unstuck the screw. In any case if there is too much difficulty, Seeed will propose a replacement.

@samjhill, I opened a thread to discuss alternative keycaps! It is here : https://github.com/BenjaminPoilve/minichord/issues/24

drfunkmeister, 2025-06-03:
My minichord arrived today!  Both fixes have been successfully done - thanks for the clear instructions.  I had no solder blob but it still took three attempts with the X-acto to cut the tiny USB bridge.  If anyone else is doing this and it doesn't work first time, don't worry, keep cutting!  And make sure the cutting blade is sharp.

Great work @BenjaminPoilve , I'm loving it!

panwiewiorka, 2025-06-08:
Hi! Here's yet another feedback:
- The skrews were really tight, had to try ph00 & ph0 but eventually ph1 helped. But there was a moment I thought I'd give up.
- The bridge cut fix was ok, although I've had to cut deeper than it looked like to finally cut it (that's an advice for other users - try more if it looks like already cut but with no effect)
- The main LED is rather bright, it would be great to either reduce it's brightness or omit the cutout and hide the LED underneath the semi-transparent panel surface, giving it nice matte look.
- Can you link to a file where the Preset -> LED color mapping takes place? I want to try to change colors of some presets to distinguish them better.

Everything else seems great!
Thank you!

electricflock, 2025-06-11:
Did the fixes to my unit. The trace cut was easy enough, buttons just a little fiddly.
But a few of my screws are not going tight so the faceplate rattles now. I was very careful on the removal and reassembly but some plastic dust came out with the screws so I fear that is as tight as it will go now.

Fizz-Wizardly, 2025-06-24:
whoops, I just saw this thread and have been playing around with this thing for several weeks now, I thought something was off! lol my unit was affected but both of the fixes went smoothly, and my unit is in working order now.

a potential improvement could be using allen-type socket head cap screws and threaded inserts for the screws that fasten the two halves of the shell together. not sure if you would need to make the shell thicker to accommodate threaded inserts, but just an idea to potentially add longevity to the fastening ability of the screws over time.

I have been absolutely loving this thing and I am impressed with all the hard work put into it. Thank You Benjamin Poilve for making this amazing instrument and for making it available to everyone! It's been an absolute joy to come across this project.

BenjaminPoilve, 2025-06-25:
@Fizz-Wizardly thanks for the suggestion! Indeed I contemplated using threaded insert, but it added significant width to the enclosure walls, so it was not really practical. In additions, in my tests I never had an issue with degradation of the thread in the enclosure, I have some enclosures that I have opened and closed tenth of times. I think the main issue here is the quality of the screws, plus the fact that Philips trace makes it easy to use a wrong-sized bit. Your comments made me check, and it seems that there is some M2.3 screws that have a Hex trace. I'll order some to test them out, maybe that'll alleviate the issues that some users have been facing.

Happy that you still like it and enjoy making music music with it :)

synthmod1, 2025-07-23:
Me too😂 my replacement arrived yesterday and charging lights and correct notes all good. Had a quick play with the editor yesterday and the random button that Benjamin implemented does throw up some great sounds and shows the depth of the synth.
I’m looking forward to falling in love again with this very special little machine ❤️

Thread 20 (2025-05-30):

Dim LED brightness

arnoson, 2025-05-30:
Just received my Minichord from seed studio and I love it! Thanks for this awesome instrument :)

When playing it in a darkened room to LEDs are quite bright. Are they PWM-able and could be dimmed thru software, maybe even as an option in the minicontrol?

arnoson, 2025-06-06:
Thanks for looking into this so quickly! I just tested it and seems that this setting is per preset rather than globally for the device. For me it would make more sense to store this outside the preset since this is a general setting on the device.

BenjaminPoilve, 2025-06-06:
That's the one use case where I would agree with you. Unfortunately, the minichord is designed with the idea that all user-settable parameters go through the preset model. There is no "global parameter" system.
For now I'll leave it be that way, if any further need for global parameters arise, I'll think about adding some control there too.

arnoson, 2025-06-06:
Alright, thanks!

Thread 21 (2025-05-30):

Feature: change Octave

arnoson, 2025-05-30:
Would be great to be able to change to octave up or down, either of Chord and Harp separately or at least for both of them at the same time. I really like the low sounds of the synth engine. Maybe the preset buttons together wirh sharp button could be used. To indicate the octave we're in the preset LED could pulse faster or slower for a short moment, similar to hove some midi keyboards indicate the octave (I think the Aturia Microlab does this)

arnoson, 2025-06-02:
Thanks for the detailed answer! Didn't know about the setting in minicontrol yet, this is definitely a good workaround. I think it would be still nice to be able to adapt the octaves while playing without having to connect to a computer but I totally get that you wan't to keep the button combos simple. Regarding the preset I think they don't have to sound good / have to be tested on all octaves, I think of it more like an exploration a user could make while playing. A bit like playing a sample really slow on a sampler and hear how the sound reaches its limits. But again, since this is already possible via the minicontrol I can totally understand if you won't add it :)

BenjaminPoilve, 2025-06-02:
My pleasure! Thanks for proposing ways to make the minichord better :)
Yeah sometimes I think it is a good idea to enforce some limitations. Event the secondary function for the potentiometer can be a bit confusing (I'm still a bit split on whether I should have left that function or not), so I'm really quite reluctant moving forward with the combo functionality.

I'll post an update this Friday after some testing. I'll try to see how the minicontrol option works out!
Please note that if you want to move up/down octaves during a single song, it will be possible to save "duplicates" of presets (with different octave selection)  in the minichord memory slots to be able to move up/down presets during a performance.

BenjaminPoilve, 2025-06-06:
Hi,
The feature is now added.
To test:
- please update your firmware following [this procedure ](https://minichord.com/user_manual/#updating-the-firmware)
- head to https://minichord.com/minicontrol/
- use the parameter "octave change" on chords and harp section

Let me know if that works!

By the way I had to make a "breaking change". That's not too much of an issue as wiping the presets back to stock solves the situation.

arnoson, 2025-06-06:
I'm trying to test this, but somehow the minicontrol software doesn'r recoginzed the presets anymore. I can connect the minichord but changing the sliders in minicontrol doesnt' change the device and vice versa pressing the preset button up/down on the device doesn't select the preset in minicontrol.

BenjaminPoilve, 2025-06-06:
That's strange. Are you using minicontrol with Chrome as recommanded? With a functioning data cable?
You updated the firmware? In any case I've kept one with the original firmware and it stays compatible.

arnoson, 2025-06-06:
Never mind, seemed to be some issue with my browser. I used chrome, but for some reasons it crashed a few times, maybe it wasn't handling all the midi. Restarted it and now everything works as expectetd! Thanks for adding this so quickly

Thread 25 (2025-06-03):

Feature: 'attack transient' 2nd oscillator for harp

drfunkmeister, 2025-06-03:
Would be great if possible.  I'm thinking about things such as experimenting with a short attack transient several octaves up from the fundamental pitch, to create sparkling bell sounds.  So the 2nd oscillator would not need a full set of parameters, and could be limited in purpose to just adding a transient to add some edge or sparkle to the the harp tone.

BenjaminPoilve, 2025-06-04:
It is not impossible per say, but a bit cumbersome to add without making breaking changes.
The synthesis was designed with a subtractive synthesis mindset. In that context, transient are created by using oscillators with high overtone content and a fast closing low pass filter after the initial attack. Doesn't using that method helps attaining the sound you have in mind?

drfunkmeister, 2025-06-04:
Yes, a fast closing low pass filter definitely helps to give an edge to the sound.  But the method of using a second tone at a much higher pitch is a little different.  The idea is to add a short 'strike tone' and simulate a bell.  For example, a short sine wave transient at a major 7th interval from the fundamental pitch, several octaves higher, can give a nice metallic edge that would be impossible by filtering only.

But if it might break some things, maybe not a good idea!

drfunkmeister, 2025-06-04:
Ha, I'm happy that you're curious about this now... :)  I don't know if it should be added before the low pass filter, or left unfiltered.  But here's a link to the organ service manual, which was very well written, and has all schematics and very good circuit descriptions:

https://we.tl/t-ae0CHIgHQv

The PDF is text searchable, so you can search for 'strike' and you can see how they did it.  It's an interesting look at the technology of 1980!

BenjaminPoilve, 2025-06-20:
I created a feature there: https://github.com/BenjaminPoilve/minichord/tree/feature-attack_transient
To test it out, you can upload the firmware into your minichord (the one from the branch [here](https://github.com/BenjaminPoilve/minichord/blob/feature-attack_transient/firmware/firmware.hex)) and use minicontrol to control the new parameter (again, the new version [here](https://github.com/BenjaminPoilve/minichord/tree/feature-attack_transient/firmware/minicontrol)

I tested it and made this preset: MDswOzUwOzUwOzUxMjs1MTI7NTEyOzA7MDswOzE5Mjs2MDs0Nzs1NjsxNTk7MTAwOzE1NzsxMDA7MDswOzEzODsxOzA7MDswOzA7MDswOzI3Ozc0OzE7MDswOzA7MDswOzA7MDswOzA7NDsxNDsxMTszOzI5OzE4OzY1OzExMDI7MzszMDI7MTE7NzA7NTsxODs0OzI2OzY7MTs1OzA7NTE2OzE2OzA7MDswOzc2OzE7MTsxMDA7MTsxOzY4OzE3OzE0OzIyOzIwOzA7MzQwOzE2ODI7NzA7NDg7MDswOzEwMDsxODs1ODswOzA7ODAwOzcwOzQzOzEwMDsxMDA7MDswOzA7MDsyMDA7MDsyOzg7NTsxOzE7MTkyOzExOzA7MDswOzA7MDswOzA7MDswOzA7MDswOzA7MDs0OzEwOzExOzEwMDs5OzA7MjAwOzQ7ODsyMDA7MDs1MDszNjs3NTs1MDswOzA7MzsxOzE7ODA7MTg1NTsyOzc2OTsxNTsxMTQ7MTk7ODszMjs4MDsxOzE7MDszMDswOzExOzA7NDY3OzA7MzU7MDsyNDswOzM7MTsxOzE7MTAwOzE7MTsxMDA7MTsxOzE7MTswOzM0MTsyMTY0OzcwOzU0OzA7MDsxMDA7MzY7NDI7MDsxOzgwOzE2OzQ7MTAwOzIwOzIxMDE7NzA7MTAwOzY7MjI7NTU7MjswOzA7MDswOzA7MDswOzA7MDswOzA7MDswOzA7MDswOzA7MDswOzA7MDsxOzI7NDs4OzE3OzA7MTI7MDsxOzI7NDs4OzE2OzY7MDsxOzA7MDswOzA7MDswOzA7MDswOzA7MDswOzA7MDswOzA7MDswOzA7

Let me know if that sounds like you imagined!

terminalwaltz, 2025-06-20:
Not the original poster, but can confirm it works and sounds pretty great!

drfunkmeister, 2025-06-21:
Thank you!!  I've updated the firmware but I don't know how to load your new preset or run the new version of minicontrol. I've tried to run some of the files but they just open as code in my browser.  I've tried to download them and the same thing happens.  Do I have to compile it before it will run?

It's probably something simple but I'm new to the world of Github!

terminalwaltz, 2025-06-21:
Hi! I've actually just gone through this process myself, so maybe I can help.

You'll have to start a small server on your computer and host the new minicontrol index.html file on "localhost:8000". This is the only way to get the MIDI permissions you need to talk to the minichord. Make sure you download the entire minichord directory (or use git clone). Change directory to the minichord/firmware/minicontrol directory, and run this line of python code:

`python3 -m http.server 8000`

You should then be able to open Chrome web browser, go to "localhost:8000" and you should get the new minicontrol page and a prompt to allow MIDI permissions.

I'm on a Linux machine, but I'm assuming this will be a relatively similar process for any machine. Let me know!

terminalwaltz, 2025-06-21:
And once you've got the minicontrol page running, to load the preset -- click "load settings" and paste that long string Benjamin posted in the prompt window. That should do it!

drfunkmeister, 2025-06-21:
Thanks for your help @terminalwaltz !  I'm much closer now - the key to it was downloading the entire minichord directory.  Now I can run minicontrol in Chrome (Win10) without needing to do anything else.  I have MIDI access to the minichord and I pasted Benjamin's preset but the attack transient features are greyed out in minicontrol and I can't hear any difference if I tweak them.

Did this happen to you?  Maybe I didn't flash the firmware correctly?

terminalwaltz, 2025-06-21:
Excellent, you're definitely close. Sounds like you need to reflash the firmware -- make sure you're grabbing the firmware from the [branch that contains the attack-transient stuff](https://github.com/BenjaminPoilve/minichord/tree/feature-attack_transient/firmware). Report back if need be!

drfunkmeister, 2025-06-21:
@BenjaminPoilve great work, thanks!!  Yes, it does sound like I imagined, especially with the harp in chromatic mode.  Great result!  I think the range of controls is perfect, and I can only think of one thing that might improve it - to allow the option for the transient to be made louder.  Maybe to make an extra 2 or 3 dB of gain available would be enough?

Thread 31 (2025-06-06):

Harp notes stick sometimes

hapiel, 2025-06-06:
Sometimes the notes on the harp remain sustained when I remove my finger. It has happened more today than on other days, I think the humidity is a bit higher today than usual.

I suppose there is not an easy way to adjust the sensitivity of the capacitive sensor?

BenjaminPoilve, 2025-06-07:
I’ve run into this once. I never could find a fault with the capacitive sensor, signals were always sent correctly. What I suspect is that there is an underlying bug in the audio synthesis library, so this bug only happens on specific presets. If you could send me the DIY (I presume) presets were it happens, it would help me track down the faulty component and make a PR to the audio library.

hapiel, 2025-06-08:
Indeed, it happens when I use this preset:

`MDswOzUwOzUwOzUxMjs1MTI7NTEyOzA7MDswOzE5MTsxMDA7MTkwOzQwOzg4OzEwMDsxNzY7MTAwOzA7MDsxOTA7MDswOzA7MDswOzA7MDswOzUwOzA7MDswOzA7MDswOzA7MDswOzA7MDsxMjsyOzE7MzsyNTk7NTQ7NjA4OzI4OzIwMDA7MDs5MjsxNDMwOzE7MTsxMDA7MTsxOzc1OzA7NjA0OzA7MDswOzA7MTsxOzE7MDsxOzE7MDsxOzE7MTsxOzA7MDswOzcwOzA7MDswOzEwMDswOzA7MDswOzk0MjsxNTY7NTA7MTAwOzEwMDswOzcwMzs2NTszODk7NjM7MDswOzA7MDswOzA7MDswOzA7MDswOzA7MDswOzA7MDswOzA7MDswOzA7MDsxOzIwOzY7MTAwOzEzOzA7NTA7MjA7MzsxMDE7MDs2NTs1OTs1NTs0MDs0MzswOzEyOzY7OTk7NjU7MzQ7MTszODg4OzA7NzA7NTAwMDsxOzE3Njk7MzM7MTsxOzA7MTAxOzYwOzY5OzA7MjY7MDs2OzA7ODI4OzA7MjY7MTsxOzE7MTAwOzE7MTswOzE7MTsxOzE7MTg7MzE2OzEyNTY7NzA7NjA7MDswOzEwMDs1ODsyNTsxODswOzE2OTsxNjsxOzEyMjsyMDU7MDs5NzswOzEwMDsxMDA7NTA7MDswOzA7MDswOzA7MDswOzA7MDswOzA7MDswOzA7MDswOzA7MDswOzA7MDs5OzA7MTI7MTY7MTswOzI7MTI7MTswOzEyOzA7MTsxNjszMjs2NDswOzA7MDswOzA7MDswOzA7MDswOzA7MDswOzA7MDswOzA7MDswOw==`

BenjaminPoilve, 2025-06-08:
Thanks, I can confirm.
Not clear to me why it causes that issue though. I thought maybe too short an envelope could be the reason, but the envelope is not out of the ordinary.
So currently no clear idea on what triggers the bug but I'll keep thinking about it.

BenjaminPoilve, 2025-06-08:
Found the issue! If the retrigger release is too long, and there is another noteOff while it is waiting for the note to release before properly triggering the noteOn, it never turns off. This is indeed in the underlying audio library.
Somehow fixed by limiting the range in the front-end, but would need to report the bug to Paul.

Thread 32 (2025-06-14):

Option for Full Diminished chord

terminalwaltz, 2025-06-14:
Benjamin -- thank you for your creation, I've been super impressed by the Minichord and the support you've offered, major kudos to you.

I've been studying Barry Harris and the Diminished 6th scale, which largely utilizes the major 6 (or relative minor 7) and the full-diminished chord as the major components of resolution and tension.

My question to you is -- can you offer an option in Minicontrol to make diminished chords sound as fully diminished? So instead of a diminished chord defined as {0,3,6,12}, you'd be looking at {0,3,6,9}. In fact, I think you could swap the 9 and 12 on line 43. (I'm assuming it's a little more complicated that this, forgive my ignorance).

`uint8_t dim[7] = {0, 3, 6, 12, 2, 5, 9};`

I would compile this myself, but I've been having difficulty getting Teensy and ArduinoIDE to play nice. Plus, I thought the option might interest some other users. The fully diminished chord is a special one -- two tritones trying to resolve, it can get you some really nice voice leading.

Thanks again!
-Greg

BenjaminPoilve, 2025-06-14:
Before answering regarding the substance of the question (whether or not to add this option), did you notice this document: https://github.com/BenjaminPoilve/minichord/blob/main/firmware/README.md ?
It gives the relevant link to set up en environment to compile the firmware yourself with VSCode/PlatformIO, which is quite easy to do.

BenjaminPoilve, 2025-06-15:
Here is the synthesis scheme (available in the manual):

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

There is three oscillator per voice, with 4 voice for the chord section. The three oscillator per voice allow for more complex sounds. So it is indeed possible to do. Replacing the line you mentioned will do!

The reason why there is 7 note and not only 4 is that in peregrinator mode you can choose from those 7 note when building the pattern.

terminalwaltz, 2025-06-15:
Thank you for your patience and explanation -- I finally have PlatformIO working and I'm able to compile and upload successfully.

Now I'm hoping you can help me understand the harp_shuffling arrays. Let's say I've got my fully diminished chord (I replaced line 43 as mentioned previously), but I would also like to see {0,3,6,9} represented on the harp, as well. I have tried a handful of configurations, but I don't seem to be able to get the 1 b3 b5 and bb7 scale tones that I'm looking for. Using the following array, however, I'm able to get 1 b3 b5 and b6:

`{0, 1, 2, 6, 10, 11, 12, 16, 20, 21, 22, 26}`

I would figure that swapping the 6, 16, and 26 with 7, 17, and 27 would result in the correct notes, but this results in only a repeat of 0, 10, and 20 (the root note). What can I do to achieve a bb7 instead?

I must be close, I really appreciate your guidance.

BenjaminPoilve, 2025-06-15:
No problem at all! I wrote the all code myself, and given that I had limited time to do so there are some idiosyncrasies that indeed warrant an explanation! It's very nice to see people interested in modifying the code :)

So the harp shuffling array: the goal is to select note from the chord definition that will be applied to the harp. The idea was that lines 37-47 defines the different chords, as defined in semitones from the root:
```
uint8_t major[7] = {0, 4, 7, 12, 2, 5, 9};  // After the four notes of the chord (fundamental, third, fifth of seven, and octave of fifth, the next notes are the second fourth and sixth)
uint8_t minor[7] = {0, 3, 7, 12, 1, 5, 8};
uint8_t seventh[7] = {0, 4, 10, 7, 2, 5, 9};
uint8_t maj_seventh[7] = {0, 4, 11, 7, 2, 5, 9};
uint8_t min_seventh[7] = {0, 3, 10, 7, 1, 5, 8};
uint8_t aug[7] = {0, 4, 8, 12, 2, 5, 9};
uint8_t dim[7] = {0, 3, 6, 12, 2, 5, 9};
```

As said before, the 4 first elements are the 4 voices of the chord, the three next can be used in the arpeggiator.

Now, for the harp, you want it to use the same notes as the chord, at least by default. But you might want to switch the order, or use some notes that are note in the core of the chord (the ones that can be used in the arpeggiator).

So to do that, I defined "shuffling arrays". Each int of the array defines the note of one segment of the harp. The unit indicates the one from the chord array (1 to 6), and the decade the octave.

```
int8_t harp_shuffling_array[6][12] = {
    //each number indicates the note for the string 0-6 are taken within the chord pattern.
    //the /10 number indicates the octave
    {0, 1, 2, 10, 11, 12, 20, 21, 22, 30, 31, 32},
    {4, 1, 0, 2, 14, 11, 10, 12, 24, 21, 20, 22}, //add the seconds
    {5, 2, 0, 1, 15, 12, 10, 11, 25, 22, 20, 21}, //add the fourth
    {6, 2, 0, 1, 16, 12, 10, 11, 26, 22, 20, 21}, //add the sixth
    {0, 10, 1, 11, 2, 12, 20, 30, 21, 31, 22, 32}, //octaves
    {0, 4, 1, 5, 2, 6, 10, 14, 11, 15, 12, 16}}; //chromatic
```

So for example, imagine you have selected the major chord, and are in the second shuffling array. The array is defined as "4, 1, 0, 2, 14, 11, 10, 12, 24, 21, 20, 22". Let's map that to notes:
- 4 -> major[4]=2 : the second of the scale
- 1 -> major[1]=4 : the major third
- 0 -> major[0]=0 : the fundamental
- 2 -> major[2]=7: the fifth
- 14 -> major[4]+one octave =2+12 : the second at the octave
and so on..

So to answer your question, if you want the full chord to be present (ie the 4 element you defined), it should probably be something like   {0, 1, 2, 3, 10, 11, 12, 13, 20, 21, 22, 23}, spanning over 3 octave.

terminalwaltz, 2025-06-15:
Well, clearly my ear isn't much better -- I thought I was hearing a diminished chord, too XD

Thank you, this makes so much more sense now, and it sounds great! I'll keep kicking around as I get more familiar with your code. Congratulations on your effort again, I hope you see many more users in the coming months.

BenjaminPoilve, 2025-06-16:
I close it, since we have another discussion!

Closed 2025-06-16.

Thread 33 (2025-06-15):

Generator script doesn't generate .hex firmware?

terminalwaltz, 2025-06-15:
Trying to get your generator script working (as described in your README), but I don't seem to be able to get it to generate a .hex file to upload. When looking through the generate.py script, in fact, I don't see any function which would actually generate the .hex file.

I'm running a python3 virtual environment, I've got all the requirements installed, and running the script with verbose output doesn't seem to show any errors. Any suggestions?

BenjaminPoilve, 2025-06-15:
I'll close this one, because there is a misunderstanding on the use of the generator.py.
The goal of this is not to generate the .hex firmware, but to ensure that there is a coherence between the minicontrol HTML page, and the internal firmware sysex handler functions. The idea is that there is a single JSON to describe the control parameters and both the controller and the functions for handling the control is the firmware are generated from it.
Compilation and upload to the Teensy are handled by platformIO is done as is explained here: https://forum.pjrc.com/index.php?threads/tutorial-how-to-use-platformio-visual-code-studio-for-teensy.66674/

Closed 2025-06-15.

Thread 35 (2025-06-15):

Feature unlocked! "Barry Harris mode" -- How to contribute new features?

terminalwaltz, 2025-06-15:
Really enjoying the minichord, and I've finally got my head wrapped around your programming workflow. I was able to create a feature I call "barry harris mode", which changes all of the major chords to major 6, the minor chords to minor 6, and the diminished chords to fully diminished. I can go on at length about why this would be useful, but suffice to say, it creates a completely new palette of tonal color.

I'm a bit new to Github, but I'm wondering if this is something I could add to a fork of the project? Or is there another way you'd like to handle it? I really think users would get some good use from this feature, it's great for jazz especially.

I've also seen numerous housekeeping bits I could clean up in the code, just spelling and some English syntactical stuff. And maybe some theory stuff, like using "scale tones" in some places for clarification. Is this something I would handle in a fork, and then make a pull request?

Thanks for entertaining some silly questions while I figure things out :)

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

BenjaminPoilve, 2025-06-16:
Great to know you managed to get the architecture!

I'd really love for inputs and error correction to the code. As I said before, I'm sure there are tons of stuff that could be corrected or made better, as well as new features like the one you propose. Indeed standard workflow is to fork the repository, make the modification then create a new pull request from the Github interface referencing the fork in question. You have some useful documentation [here](https://docs.github.com/en/pull-requests/collaborating-with-pull-requests/proposing-changes-to-your-work-with-pull-requests/creating-a-pull-request-from-a-fork). I'll review it and integrate it in the main branch.

Regarding your new feature, I can't wait to test it out! I'm wondering: do you think the proposed name is the most explanatory for this feature? I'm wondering if we could find something more explicit for musician (but maybe this is my lack of familiarity with this musician that shows).

terminalwaltz, 2025-06-16:
Submitted a pull request, let me know what you think!

I'm regards to the name, I'm sure there's something better we could consider. Barry Harris had a specific theory on harmony that has a lot of interesting applications in jazz, especially. He wasn't very well known as a performer, I believe, but his legacy as a teacher remains strong.

If you'd like me to do a small write-up about it, I'd be glad to. Users might like to know how this option could contribute to their harmonic choices. For instance, a C major 6 is comprised of C E G A, which is the same spelling for an A minor 7. On the minichord, this means you'd have two different inversions of C6/Am7 available, and each of them resolve perfectly from the same fully diminished chord (in this case D,B,F, or Ab diminished, all have the same chord spelling). There are only 3 fully diminished chords due to their symmetry, so these are also represented in multiple inversions.

So, in terms of fingerings, with the Barry Harris option, you could play Dm7 with the bottom two rows, then on the same root play the top two rows for Ddim. This will resolve beautifully to C6, Am7, Cmaj7. This would make a solid ii - V - I type progression , with some nice colors. OR you can pivot on this diminished chord and point at Em7/G6, what Barry Harris called "the 6 on the fifth". Em7 (E G B D) is a reasonable spelling for a rootless Cmaj9, and thus can also act as a tonic harmony.

Anyway, play around with it, and keep in mind the idea that C6 and Am7 are interchangeable. Let me know how it goes!

terminalwaltz, 2025-06-16:
Yes, I'd be more than happy to do a write-up on the feature for the newsletter! And I'll see about contributing a preset to demonstrate, though honestly, I've been using your Twin Peaks Lynch-inspired preset to great effect so far.

I think for anyone who has loved the Omnichords of the past, the ability to play unusual chord extensions is an incredible feature, something the original simply wasn't capable of. This may be a feature to expand upon in the future, perhaps it could turn into a more generalized "choose your own chords" for the layout eventually.

Glad you're enjoying the feature, I'll be in touch with a write-up!

Closed 2025-06-18.

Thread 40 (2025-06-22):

Bug -- MIDI OUT for harp (CH2) ceases when volume pot turned down

terminalwaltz, 2025-06-22:
To reproduce: observe MIDI channel 2 function, turn down second volume pot (harp pot), MIDI transmission through channel 2 ceases. Interesting behavior, doesn't happen for chords on channel 1, but only for the harp notes on channel 2.

I'll have a look and see if I can spot anything obvious, just documenting for now.

BenjaminPoilve, 2025-06-26:
Just to report the discussion here: I think you are very right that velocity and volume are different notions. Still, velocity is one of the midi parameters that is the most commonly supported in MIDI synth, so I thought it made sense to map it there. I've seen it being used by minichord players.
On the other hand, I understand that it might be surprising if you don't expect it. So I'm still split!

terminalwaltz, 2025-06-26:
I think we're maybe missing each other's points, and it's probably because I don't fully understand how you've structured the internal Teensy synth. Forgive me trying to gain some clarification again:

My expectation would be that I could turn off the local sound but still transmit MIDI. Usually this is a switch like "local off". I presume that this simply cuts audio output but maintains all MIDI data transmission. For a velocity sensitive board, like a piano controller, this MIDI information would include variable velocity information, ranging anywhere from 1-128.

The minichord does not appear to be able to produce variable velocities, all notes ultimately come out at the same uniform volume, controllable by the volume pot. If I'm understanding your code correctly, you've used velocity as the stand-in for volume in the Teensy because you're communicating to the internal synth with MIDI data and velocity makes sense as a stand-in for volume in that scenario.

If this is the case, then I understand why you wouldn't want to break anything by choosing against velocity in your internal framework, and this "bug" makes sense. Afterall, my problem is fixed by turning off my external speaker, it's not a major issue. My thought that this could be a bug stems from my prior expectations of MIDI controllers, this project need not follow suit exactly :)

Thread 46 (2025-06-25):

Discussion - Minicontrol Interface

BenjaminPoilve, 2025-06-25:
I open this thread to discuss the minicontrol interface. As is, the interface is quite rough, and it would probably make it easier for people to get started using it if it was a bit easier to use. In addition, there are several basic usability issues that need to be disabled.

Please use this thread to list the issues you are facing, as well as to share inspirations and example that would be useful for the rework. It will serve as a reference when the work begin.

BenjaminPoilve, 2025-06-25:
From my side, an initial list:
- The long list of parameter makes it easy to get lost, and edit the wrong parameter (for example editing Harp envelope instead of Chord envelope)
- Sliders are not the right interface for all parameters. Need to have more diversity in interface type (buttons for example)
- Need to allow setting a specific value, for example by bringing up a text input
- Some people are using minicontrol on smartphones. Need to make sure that the interface works well in that context (tooltip for example does not work there).

BenjaminPoilve, 2025-07-11:
Additional feature: the ability to copy only chords or only harp to another preset, per #53!

terminalwaltz, 2025-07-12:
I want to see a "Simple Mode" or a "Kid's Mode" that simplifies the number of parameters and constrains the potential sounds (to mitigate harsh parameters).

I have an interest in putting the minichord in the hands of my students, ages range from 5-15. The minichord is an excellent vehicle for teaching music theory, sound design, and coding, so I want to be able to easily access all of these features and have students interact meaningfully no matter their age.

Some of my students are more into the tech side of music than theory or performance, they would be thrilled to be able to modify their own synthesizer 🎹 🎶

BenjaminPoilve, 2025-07-13:
Great suggestion! I think some functions are easy to "simplify" (the effects mostly), but there would need to be some thinking about some that are quite cumbersome (the envelopes for example). Maybe we could do an "envelope generator" based on two parameters (strike, decay for example)? I'll give it some thoughts!

terminalwaltz, 2025-07-13:
Want to elaborate slightly on a "collaborative synth patch maker". I don't know if I mean something like "collaborative live editing" as much as I mean maybe a minishop-style interface that just allows users to submit modifications easily, but with some nod towards not destroying the original preset and getting some kind of "approval" from users, maybe? It's a moonshot idea, just figured I'd get it out there!

vincent-maurer, 2025-07-13:
Minichord is a great instrument to play with! I feel that the interface could have some more visual feedback and clustered groups of controls.

Maybe the different sections could be grouped together with previews for the waveforms and envelopes.
I cobbled together a non functional mockup with the help of AI. It's missing a lot of parameters, but it is  going in an interesting direction:
https://codepen.io/Vincent-Maurer/pen/VYvYqmV

Ideally a visualizer would make the tooltips less important and make it a bit friendlier for beginners

terminalwaltz, 2025-07-13:
@vincent-maurer I really like what you've done here, you should check out [the monstrosity](https://terminalwaltz.github.io/minicontrol/) I've been building. It's got a [repo](https://github.com/terminalwaltz/minicontrol), you should pop over and see if there's anything you can add. I'm largely using AI to help, as well, and as Benjamin as warned me, it has led to a bit of tech debt in the code. But overall it's functioning well, but *use with caution* as it may corrupt your parameters and should be considered "experimental".

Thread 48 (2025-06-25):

Spilled coffee on it 😢

samjhill, 2025-06-25:
* my workspace collapsed and I spilled coffee on my minichord 😭
* it’s dry now
* took it apart and dried it thoroughly
* it turns on and I can switch between presets as normal. LEDs work as expected
* however, sound output is intermittent. I can’t reproduce what causes the sound to work or not; seems random. When the sound _does_ work, it sounds perfect.

I was wondering if you could help me identify which board I should replace?

I also just bought another unit, just in case it’s dead. Worst case I can give it away as a gift.

Cheers

terminalwaltz, 2025-06-26:
@samjhill Man, very sorry to hear, certainly happens to the best of us!

I'm wondering if you've cleaned the headphone jack thoroughly, too? I'm not saying coffee wouldn't potentially cause some problems, but in my repair experience, mechanical contacts are always a lot more fussy with spills. Electronics are surprisingly robust against a lot of stuff if you power down quickly and clean up right away.

You might also consider just giving the PCB a good scrubbing, light soap and water, or even just give it a good swabbing with isopropyl. Either way, I bet you can save it, I'll be rooting for you!

Closed 2025-06-29.

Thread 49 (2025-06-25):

Info on ordering Keymaster Touchzone

Fizz-Wizardly, 2025-06-25:
I am interested in getting one of those "Keymaster touch zones" made but have never ordered a custom PCB before.
not sure if it's too big of a question but do all of the files in the folder included in (hardware/PCB/touch zones/keymaster PCB/gerber) need to be given to a custom PCB website or just specific ones?

Does one need to download KiCad and assemble the gerber files and export a completed assembly file of some sort to order?
Or are the files provided in the GitHub folder sufficient for ordering the Keymaster touch zone? And are there any specific instructions to be sure to include in the order when ordering one/them?

Thanks in advance from my fat fingers

terminalwaltz, 2025-06-26:
@Fizz-Wizardly For whatever it's worth, I'm actually waiting on a batch of keymaster touch zones right now! It's a 5 PCB minimum order, so I'm going to have extra, and I'm planning on sending one to another user when they arrive (I'll even solder the headers). If you want one, I'm happy to send an extra!

But otherwise, if you want your own batch, you should just be able to upload an archive of all of the PCB files for the keymaster, a .zip is usually what it calls for. If you're using JLCPCB, you might even be able to use my order number to just get a repeat of the same thing I did: order# Y1-3681988A

Happy to help if you need it! Otherwise, if you want one from me, hang tight and I'll update when they arrive. They shipped out a few days ago, hopefully it won't be long!

Fizz-Wizardly, 2025-06-26:
@terminalwaltz thanks a ton for the info! I’d be interested in one of your extras! I’d be happy to Venmo you some cash to cover any expenses plus some for going through the effort. It would be very much appreciated!
Hopefully your response will be helpful to some others interested in ordering these also.

Can I Get an email address from you so I can send you my shipping info and get your Venmo or something?

My Email is jdneff1@gmail.com just send whatever message when you’re ready and I’ll give you my required info.

Thanks again, YOU ROCK Terminalwaltz!

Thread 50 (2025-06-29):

Feature Request: Change octaves for set of chords based on the root note

jcirimel, 2025-06-29:
Often times I'm playing and need to reach a chord in a lower octave so I've been using two identical banks with different octaves and switching between them which works but is clumsy. However, rarely do I need to use the same chord in two different octaves. Presently C is always the lowest chord and B is always the highest. It would be very continent to be able to set the effective lowest note from C to another note. This can kind of be done now with the transpose feature, but it would reorganize the notes on the minichord which is undesirable. Ideally I think this could be implemented the same way as transpose with a 12 option selector. Let me know what you think and thanks for your consideration!

terminalwaltz, 2025-06-29:
If I can try to put it in different words for my own clarity, you're effectively describing a "frame shift" of the chords so that the lowest-pitched chords aren't necessarily the chords to the left all the time, is that right? Makes sense, would be a good feature.

jcirimel, 2025-06-30:
Yeah, I think frame shift is a good way to put it. As an example, a frame shift of 0 could have the chord buttons be F4 C4 G4 D4 A4 E4 B4 and a frame shift of +3 could be F4 C5 G4 D5 A4 E4 B4. The frame is shifted to the right 3 notes so C, Db, and D get pitched an octave up.

BenjaminPoilve, 2025-06-30:
I had trouble getting my head around it, but the term frame shift indeed helped to conceptualise the feature.
I think we need to talk about the behaviour of the sharps. Currently they solely add (or subtract in flat mode) to the current played note. So the basic way to implement this would to have not 12 but 7 level and frame shift only on notes from the C scale.
If you really see a need for a semitone-level frame shift, that would be slightly trickier to implement, plus I'm worried it would break the mental model of that button (a simple "bend" one semitone).
Let me know what you think!

BenjaminPoilve, 2025-06-30:
I think the feature request is now quite clear.
From a practical perspective, it'll be much easier to implement a 7 level version. I would keep a map of the seven option, with the associated octave shift.
Currently the root is stored like that
```
uint8_t root_button[7] = {11, 4, 9, 2, 7, 0, 5}; // defines the fundamental of each row in the circle of fifth, ie F,C,G,D,A,E,B from left to right
```
It could be changed to something like that
```
int8_t root_button[7][7] = {
    {11, 4, 9, 2, 7, 0, 5};  // C as lowest
    {-1, -8, -3, -10, -5, 0, -7},  // D as lowest
    {-1, -8, -3, 2, -5, 0, -7},  // E as lowest
    .....,  // and so on
}
```
I'm not sure how clear it would be to a user that did not follow that discussion though. Both the feature and the implementation.

terminalwaltz, 2025-07-10:
@jcirimel Give this [new firmware.hex](https://github.com/terminalwaltz/minichord/tree/feature-FrameShiftChords/firmware) a shot and let me know if this is what you were thinking.

You'll have to run this [modified minicontrol](https://github.com/terminalwaltz/minichord/tree/feature-FrameShiftChords/firmware/minicontrol), too, so you can actually change the values for "chord frame shift", let me know if you need help!

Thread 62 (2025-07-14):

Harp Voice Leading

terminalwaltz, 2025-07-14:
I'm already tooling around with this in the firmware, but I would love some input.

In short, I want the harp to maintain a memory of the last chord played, and if the new chord has common tones with the last chord, I want them to stay where they are on the harp for the new chord. I want "smooth voice leading", for lack of a better term.

Playing a song, say something like F#m D A E 😆, I would like my fingers to be able to stay on the same two harp notes instead of jumping just nearby to grab the same notes I was just playing.

I've been calling the feature "harp voice leading", and it could easily be turned on and off, but I'm having trouble getting the logic right, I think probably because of the interaction with harp shuffle arrays? Just interested in your thoughts on this, I think it would be a great feature :)

BenjaminPoilve, 2025-07-14:
Voice leading has been in my mind for a while, as it could be something that really sets apart the minichord!

Trouble is, I always have problems defining what should be done:
- First there is the question of the "distance metric". My first reflex would be to gravitate towards something akin to an earthmover distance: sum the moves in semitone for each voice and try to minimise that. But is it always the case? Do we want to favour zero change for some notes over the general distance (ie find the common notes, then fill the rest)?
- Then there is the question of the set of chords we want to attain. Is it only the inversions? Do we need to keep the note "ascending" or should it be ok to have them out of order?
- Then there is a musical question: do we always want to have the minimum distance? Voice leading is also about choosing to create breaks, not only to smoothly go from one to the next.

If we can define the feature properly, it will be much easier for me to identify where it should be added!

terminalwaltz, 2025-07-14:
Excellent, you've obviously given this a lot of thought! Let me see if I can bring perspective from the music theory realm and we can figure out what this thing should be:

In my eyes, "good voice leading" in the theoretical sense would be most easily portrayed by a vocal quartet -- each singer is partaking in a part of the harmony (chord), and [best practice/ease of singing/attractiveness to the ear] means that you want the singers to move their voices as little as possible to achieve the next harmony.

The application of this concept to the minichord/harp mean we're considering that we have 12 voices (for 12 strings) instead of only 4 voices like a quartet, and we want the availability of those voices to move as little as possible from chord to chord.

Of course, the difficulty with having a pre-established harp layout is the lack of "freedom" to choose certain inversions over others -- as you mentioned, we don't always want the minimum distance, that is the whole point of musical choice, especially in improvisation!

Come to think of it -- perhaps this could be something we think about from the perspective of the chords, as well. Right now, all of the chords are stacked root-third-fifth-octave (with some exceptions for extended chords), but the ultimate freedom would lie in somehow being able to choose from "root" "first" or "second" inversions (which stack the tones in different orders) before pressing the next chord button. This is probably impractical from a performance perspective on the minichord, but I wonder if there couldn't be some internal logic that might calculate which inversion would provide the cleanest movement from the previous chord.

The harp layout is dependent upon chord choice, so perhaps tackling voice leading on the chord level would make more sense??

terminalwaltz, 2025-07-14:
I have to mention this possibility, as well -- now that we have a function to effect a key signature upon the chord buttons, we might have room now to *add a harp array which is simply the major scale of the key signature*. This could potentially simplify the idea of voice leading in the sense that it would be a remapping of the *major scale* every time instead of a remapping of a chord, or perhaps some combination thereof (like prioritizing common tone conservation)? I know you already have harp arrays which add alternate scale tones, but I guess this would be a different treatment of the harp layout based on the entirety of the major scale instead of one chord. I suppose this would break ascending/descending order in some places, but I think some of these tradeoffs would be worthwhile.

I may want to add a harp array for "major scale" based on the key signature now that we've done it, so be on the lookout! :D

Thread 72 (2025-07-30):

Compatibility with USB host mode compliant devices

BenjaminPoilve, 2025-07-30:
As you know, the minichord only works with devices that support the USB host mode. I've had reports from minichord users regarding its use.

There are some positive example, in which all seems to work quite well:

- Norns (by Monome)
- Organelle (by Critter & Guitar)

But there are also situations in which it seems that the MIDI signals get scrambled for some reason:

- RK006 (by RetroKits)
- H2MIDIPro (by CME)

I currently don't have either of those devices, so it is a bit complicated to troubleshoot what the issue could be. I might need to purchase one at some point. In the meantime, I'd like to use this thread to discuss such issues and hopefully get some helps from people that have more experience on the matter to try to troubleshoot those issues.

iktomi-sakala, 2025-10-02:
Hey, I'm really interrested by your Minichord. I have a home studio with some stuff, and even if I consider your instrument already cool by itself, if it would work with some of my synth, it would be really fantastic. (mainly my GR-1 and GR-Mega from Tasty Chips)
I have no expectations, but I think it might work, as they are pretty much "open" in term of connectivity. (based on raspberry, direct usb connection with a Microlab or the Scarlett 2i2 work fine by example, they just need to be class compliant).
I think I'll order you one for what it is anyway (when I can)... and then I'll do some tests, and get back to report what I got.

mio-moto, 2025-10-02:
I have a H4MIDI WC at my disposal and a teensy development setup. I can do some debugging, if you point me in the right directions.

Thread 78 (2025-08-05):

Multi-Button Chord timing is difficult

terminalwaltz, 2025-08-05:
This is slightly esoteric, but I'm getting more and more interested in tightening up the timing surrounding multi-button chord presses. Right now, it's sometimes difficult to nail down certain multi-button chords like augmented, diminished, major/minor 7. The logic is such that there is a very small window to get the simultaneous presses to happen so that the right chord will trigger. This has become a compounding issue for me working on #66, especially, because the harp is meant to reflect a scale based upon the chord press. I have had difficulty really nailing this down for the multi-button chords, and it has me considering what could be done to refactor the logic in the main branch before I keep going down a diverging road.

@BenjaminPoilve Do you have any ideas already in mind about how to better handle these multi-button chords so they are triggered more accurately? I feel like they should be treated like "chunks" of button presses that need to happen within a small window together, something like that. Any input you've got is appreciated. And in your own time, of course, no rush!

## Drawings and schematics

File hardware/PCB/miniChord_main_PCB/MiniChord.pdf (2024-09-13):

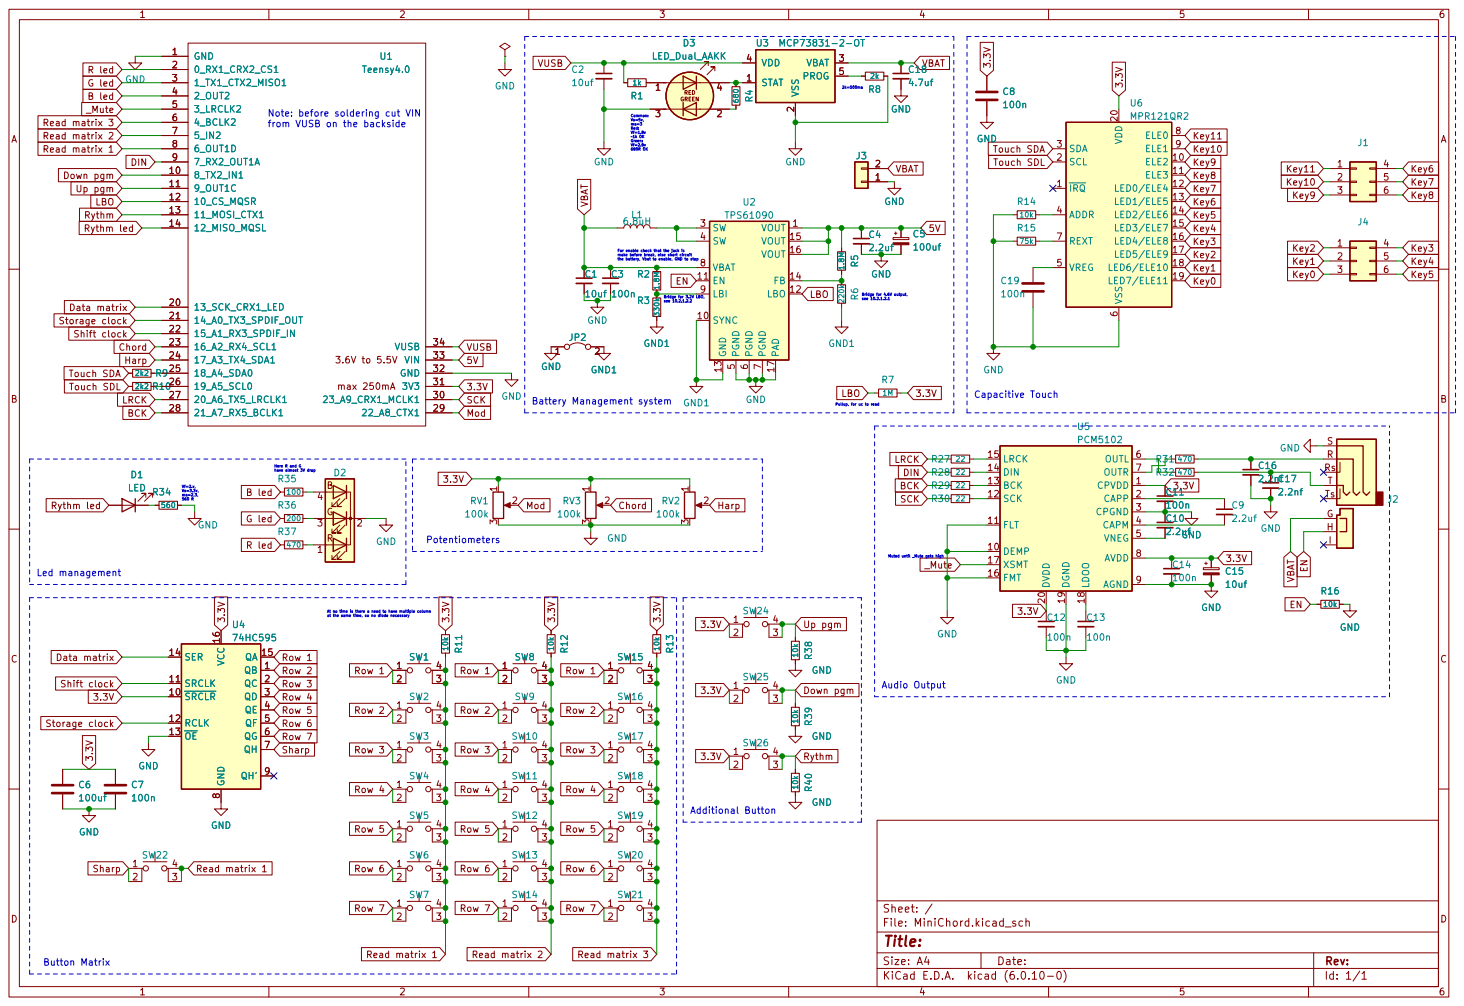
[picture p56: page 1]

2 VBAT 3 VDD 4 PROG 5 U3 MCP73831-2-OT

Note: before soldering cut VIN
from VUSB on the backside

For enable check that the jack is make before break, else short circuit

Muted until _Mute gets high

At no time is there a need to have multiple column

Storage clock Shift clock 3.3V

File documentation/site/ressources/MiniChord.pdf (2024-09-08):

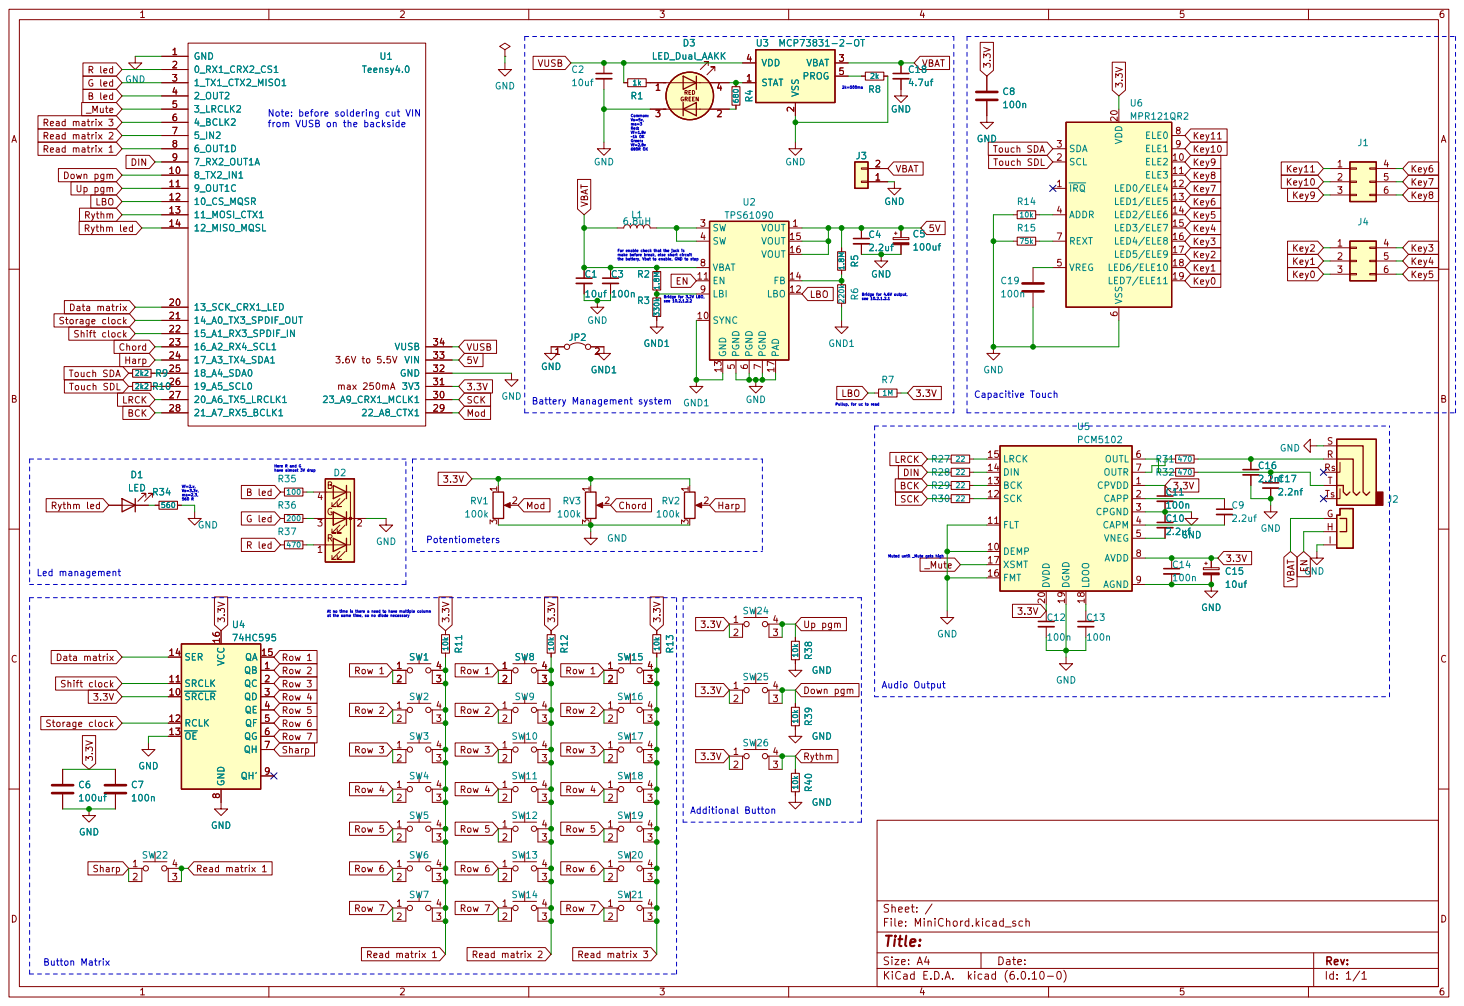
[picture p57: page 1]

Read matrix 2 Touch SDA

2 VBAT 3 VDD 4 PROG 5 U3 MCP73831-2-OT

2k=500ma Bridge for 3.2V LBO, see 10.2.1.2.2 For enable check that the jack is make before break, else short circuit

the battery, Vbat to enable, GND to stop Note: before soldering cut VIN
from VUSB on the backside

Touch SDL Read matrix 3

Key11 R led B led G led BCK

Key7 Row 5 Row 7 Row 6 Mod

Bridge for 4.6V output, see 10.2.1.2.1 Battery Management system

Pullup, for uc to read

3.3V Rythm led Shift clock 3.3V Data matrix

At no time is there a need to have multiple column
at the same time, so no diode necessary

Row 3 Row 3 Row 2 Storage clock 3.3V

Audio Output Additional Button

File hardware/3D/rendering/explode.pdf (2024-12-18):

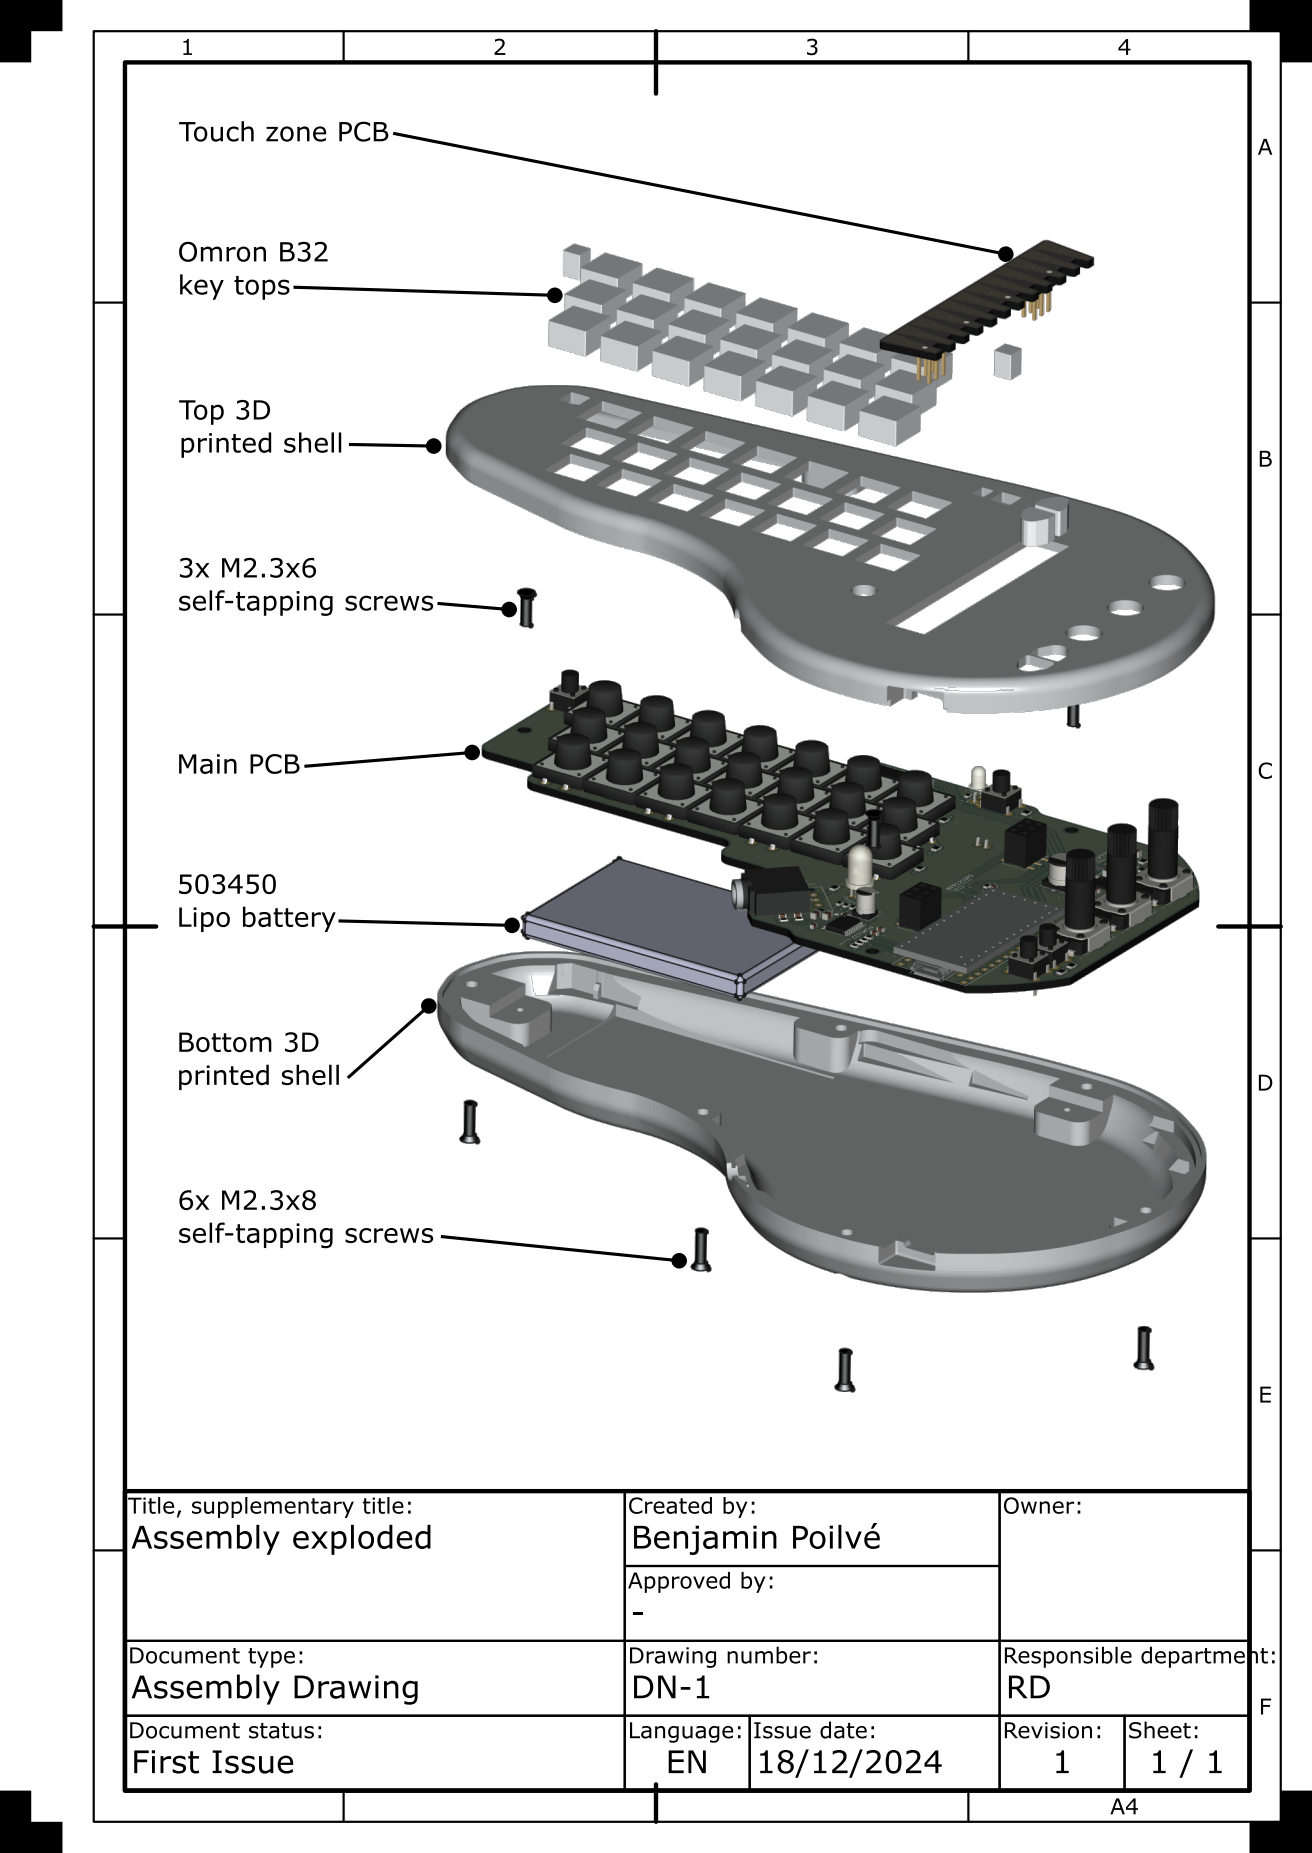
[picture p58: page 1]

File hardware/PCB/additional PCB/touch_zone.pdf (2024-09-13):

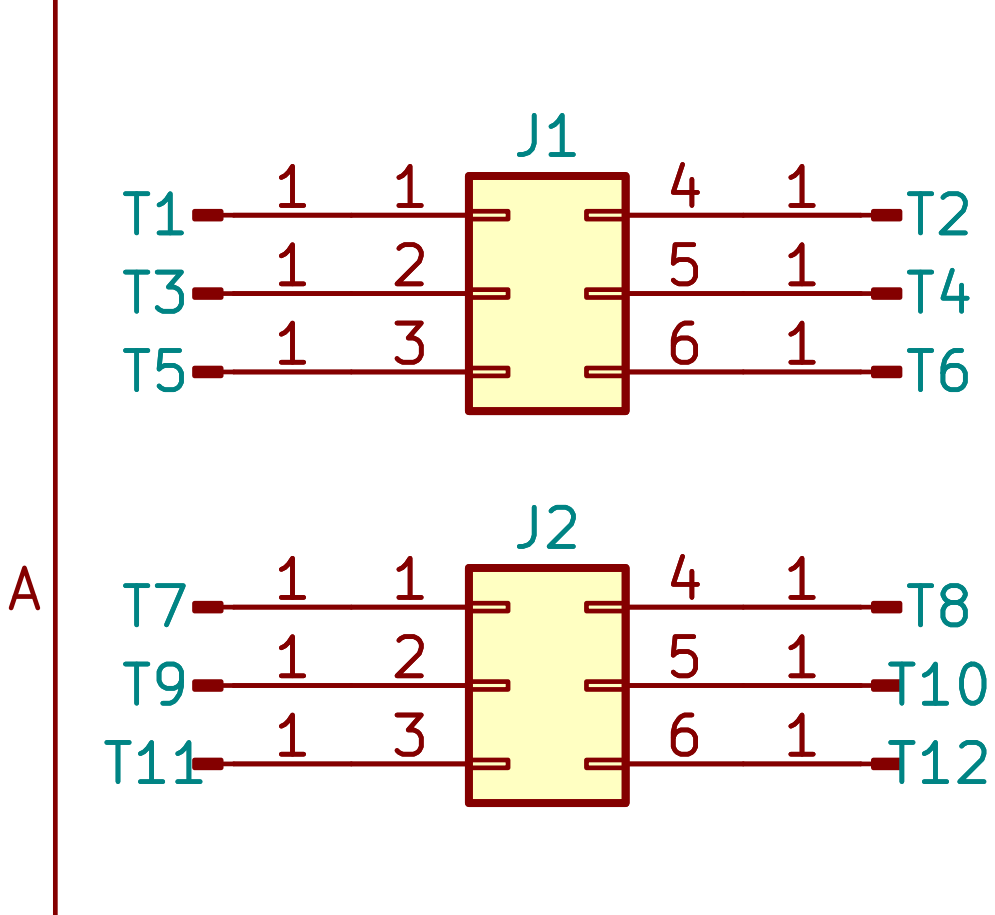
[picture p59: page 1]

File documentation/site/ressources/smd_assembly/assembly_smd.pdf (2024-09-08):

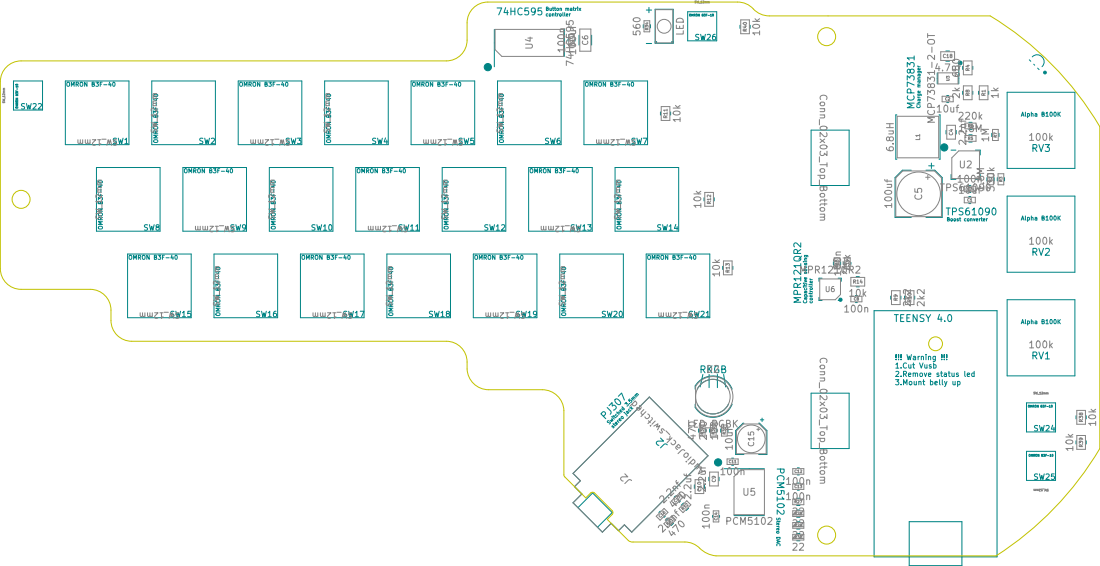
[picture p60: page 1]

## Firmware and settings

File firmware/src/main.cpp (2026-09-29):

#include "audio_definition.h"
#include "def.h"
#include <AT42QT2120.h>
#include <Arduino.h>
#include <Audio.h>
#include <LittleFS.h>
#include <SPI.h>
#include <Wire.h>
#include <button_matrix.h>
#include <debouncer.h>
#include <harp.h>
#include <potentiometer.h>

//>>SOFWTARE VERSION 
int version_ID=9; //to be read 00.03, stored at adress 7 in memory
//>>BUTTON ARRAYS<<
debouncer harp_array[12];
debouncer chord_matrix_array[22];

//>>HARDWARE SETUP<<
harp harp_sensor;
button_matrix chord_matrix(SHIFT_DATA_PIN, SHIFT_STORAGE_CLOCK_PIN, SHIFT_CLOCK_PIN, READ_MATRIX_1_PIN, READ_MATRIX_2_PIN, READ_MATRIX_3_PIN);
debouncer hold_button;
debouncer up_button;
debouncer down_button;
debouncer LBO_flag;
bool flag_save_needed=false; //to know if we need to save the preset
potentiometer chord_pot(POT_CHORD_PIN);
potentiometer harp_pot(POT_HARP_PIN);
potentiometer mod_pot(POT_MOD_PIN);
LittleFS_Program myfs; // to save the settings
float color_led_blink_val = 1.0;
bool led_blinking_flag = false;
float led_attenuation = 0.0; 



//>>CHORD DEFINITION<<
//for each chord, we first have the 4 notes of the chord, then decoration that might be used in specific modes
uint8_t major[7] = {0, 4, 7, 12, 2, 5, 9};  // After the four notes of the chord (fundamental, third, fifth of seven, and octave of fifth, the next notes are the second fourth and sixth)
uint8_t minor[7] = {0, 3, 7, 12, 1, 5, 8};
uint8_t maj_sixth[7] = {0, 4, 7, 9, 2, 5, 12};
uint8_t min_sixth[7] = {0, 3, 7, 9, 1, 5, 12};
uint8_t seventh[7] = {0, 4, 10, 7, 2, 5, 9};
uint8_t maj_seventh[7] = {0, 4, 11, 7, 2, 5, 9};
uint8_t min_seventh[7] = {0, 3, 10, 7, 1, 5, 8};
uint8_t aug[7] = {0, 4, 8, 12, 2, 5, 9};
uint8_t dim[7] = {0, 3, 6, 12, 2, 5, 9};
uint8_t full_dim[7] = {0, 3, 6, 9, 2, 5, 12};
//now the chords used for the alternate layout
uint8_t sus_fourth[7]   = {0, 5, 7, 12, 2, 9, 10};  // sus4
uint8_t sus_second[7]   = {0, 2, 7, 12, 5, 9, 4};   // sus2
uint8_t seventh_sus[7]  = {0, 5, 10, 7, 2, 9, 4};   // 7sus4
uint8_t major_ninth[7]  = {0, 4, 11, 2, 7, 5, 9};   // maj9, no fifth
uint8_t minor_ninth[7]  = {0, 3, 10, 2, 7, 5, 8};   // min9, no fifth
uint8_t added_ninth[7]  = {0, 4, 7, 2, 5, 9, 11};   // add9
uint8_t six_nine[7]     = {0, 4, 9, 2, 7, 5, 11};   // 6/9
uint8_t half_dim[7]     = {0, 3, 6, 10, 2, 5, 8};   // m7b5

uint8_t alt_chord_layout = 0;   // 0 = standard chords, 1 = the assignable layout


// Every chord the instrument can make, in one list, so a button combination can
// be pointed at any of them rather than at a fixed table.
uint8_t (*chord_catalogue[18])[7] = {
  &major, &minor, &seventh, &maj_seventh, &min_seventh, &dim, &aug,
  &maj_sixth, &min_sixth, &full_dim, &half_dim,
  &sus_fourth, &sus_second, &seventh_sus,
  &major_ninth, &minor_ninth, &added_ninth, &six_nine
};
const uint8_t chord_catalogue_size = 18;

// One parameter per button combination, so a layout is part of the preset.
const uint8_t alt_slot_adress[7] = {202, 203, 204, 205, 206, 207, 208};

// What each slot plays when its parameter is 0. That matters for compatibility:
// a preset saved before these addresses existed holds 0 in all of them, and
// should still give the suspended and extended set rather than seven majors.
const uint8_t alt_slot_default[7] = {11, 12, 13, 14, 15, 16, 17};

uint8_t (*alt_chord_for(uint8_t slot))[7];
uint8_t key_signature_selection = 0; // 0=C, 1=G, 2=D, 3=A, 4=E, 5=B, 6=F, 7=Bb, 8=Eb, 9=Ab, 10=Db, 11=Gb
enum KeySig { // Enums for KeySigs
  KEY_SIG_C, KEY_SIG_G, KEY_SIG_D, KEY_SIG_A, KEY_SIG_E, KEY_SIG_B,
  KEY_SIG_F, KEY_SIG_Bb, KEY_SIG_Eb, KEY_SIG_Ab, KEY_SIG_Db, KEY_SIG_Gb
};
enum Button { // Button enum in hardware order: B, E, A, D, G, C, F
  BTN_B, BTN_E, BTN_A, BTN_D, BTN_G, BTN_C, BTN_F
};
enum FrameShift { //Enums for chord frame shifts
  FRAMESHIFT_0, FRAMESHIFT_1,FRAMESHIFT_2,FRAMESHIFT_3,FRAMESHIFT_4,FRAMESHIFT_5,FRAMESHIFT_6
};
const int8_t base_notes[7] = {11, 4, 9, 2, 7, 0, 5}; // Base note offsets for buttons in key of C (relative to C4 = MIDI 60), in hardware order B, E, A, D, G, C, F
const int8_t key_offsets[12] = {0, 7, 2, 9, 4, 11, 5, 10, 3, 8, 1, 6}; // Circle of fifths: semitone offset for each key’s root note relative to C: C, G, D, A, E, B, F, Bb, Eb, Ab, Db, Gb
const int8_t key_signatures[12] = {0, 1, 2, 3, 4, 5, 1, 2, 3, 4, 5, 6}; // Number of sharps or flats for each key: Sharps for C, G, D, A, E, B; flats for F, Bb, Eb, Ab, Db, Gb
const int8_t sharp_notes[6][6] = { // Notes affected by sharps in each key, in hardware order (B, E, A, D, G, C, F)
  {BTN_F},          // 1 sharp: F#
  {BTN_F, BTN_C},   // 2 sharps: F#, C#
  {BTN_F, BTN_C, BTN_G}, // 3 sharps: F#, C#, G#
  {BTN_F, BTN_C, BTN_G, BTN_D}, // 4 sharps: F#, C#, G#, D#
  {BTN_F, BTN_C, BTN_G, BTN_D, BTN_A}, // 5 sharps: F#, C#, G#, D#, A#
  {BTN_F, BTN_C, BTN_G, BTN_D, BTN_A, BTN_E} // 6 sharps: F#, C#, G#, D#, A#, E#
};
const int8_t flat_notes[6][6] = { // Notes affected by flats in each key, in hardware order (B, E, A, D, G, C, F)
  {BTN_B},          // 1 flat: Bb
  {BTN_B, BTN_E},   // 2 flats: Bb, Eb
  {BTN_B, BTN_E, BTN_A}, // 3 flats: Bb, Eb, Ab
  {BTN_B, BTN_E, BTN_A, BTN_D}, // 4 flats: Bb, Eb, Ab, Db
  {BTN_B, BTN_E, BTN_A, BTN_D, BTN_G}, // 5 flats: Bb, Eb, Ab, Db, Gb
  {BTN_B, BTN_E, BTN_A, BTN_D, BTN_G, BTN_C} // 6 flats: Bb, Eb, Ab, Db, Gb, Cb
};

float c_frequency = 130.81;                      // for C3

//>>SCALAR HARP MODE<<
// 0 follows the chord as before. 1-7 are fixed scales rooted on the key. 8 and 9
// pick a scale to suit whichever chord is currently held, 9 being the pentatonic
// version of 8.
uint8_t scalar_harp_selection = 0;

// Tonic pitch class for each key signature, in the order of the KeySig enum
const int8_t scale_root_offsets[12] = {
  0, 7, 2, 9, 4, 11, // C, G, D, A, E, B
  5, 10, 3, 8, 1, 6  // F, Bb, Eb, Ab, Db, Gb
};

// Fixed scales for modes 1-7, semitones from the root
const uint8_t scale_intervals[7][8] = {
  {0, 2, 4, 5, 7, 9, 11, 0}, // 1: Major (Ionian)
  {0, 2, 4, 7, 9, 0, 0, 0},  // 2: Major Pentatonic
  {0, 2, 3, 7, 10, 0, 0, 0}, // 3: Minor Pentatonic
  {0, 2, 4, 5, 7, 8, 9, 11}, // 4: Diminished 6th
  {0, 2, 3, 5, 7, 8, 10, 0}, // 5: Relative Natural Minor
  {0, 2, 3, 5, 7, 8, 11, 0}, // 6: Relative Harmonic Minor
  {0, 2, 3, 7, 10, 0, 0, 0}  // 7: Relative Minor Pentatonic
};
const uint8_t scale_lengths[7] = {7, 5, 5, 8, 7, 7, 5};

// Scales chosen per chord type for modes 8 and 9
const uint8_t chord_scale_intervals[15][8] = {
  {0, 2, 4, 7, 9, 0, 0, 0},  //  0: Major Pentatonic, major chord
  {0, 2, 4, 6, 9, 0, 0, 0},  //  1: Lydian Pentatonic, major seventh
  {0, 3, 5, 7, 10, 0, 0, 0}, //  2: Minor Pentatonic, minor
  {0, 2, 4, 7, 10, 0, 0, 0}, //  3: Mixolydian Pentatonic, dominant seventh
  {0, 3, 5, 7, 9, 0, 0, 0},  //  4: Dorian Pentatonic, minor seventh
  {0, 1, 3, 4, 6, 7, 9, 10}, //  5: Octatonic, diminished
  {0, 2, 4, 6, 8, 10, 0, 0}, //  6: Whole Tone, augmented
  {0, 2, 4, 5, 7, 8, 9, 11}, //  7: Diminished 6th, major sixth
  {0, 2, 3, 5, 7, 8, 9, 11}, //  8: Diminished 6th Minor, minor sixth
  {0, 2, 3, 4, 6, 7, 9, 11}, //  9: Offset Diminished 6th, full diminished
  {0, 2, 4, 5, 7, 9, 11, 0}, // 10: Ionian, major
  {0, 2, 3, 5, 7, 9, 10, 0}, // 11: Dorian, minor seventh
  {0, 2, 4, 6, 7, 9, 11, 0}, // 12: Lydian, major seventh
  {0, 2, 4, 5, 7, 9, 10, 0}, // 13: Mixolydian, dominant seventh
  {0, 2, 3, 5, 7, 8, 10, 0}  // 14: Aeolian, minor
};
const uint8_t chord_scale_lengths[15] = {5, 5, 5, 5, 5, 8, 6, 8, 8, 8, 7, 7, 7, 7, 7};



uint8_t chord_octave_change=4;
uint8_t harp_octave_change=4;
uint8_t chord_frame_shift=0;
uint8_t transpose_semitones=0;                       // to use to transpose the instrument, number of semitones
uint8_t (*current_chord)[7] = &major;            // the array holding the current chord
uint8_t current_chord_notes[7];                  // the array for the note calculation within the chord, calculate 7 of them for the arpeggiator mode
uint8_t current_applied_chord_notes[7];          // the array for the note calculation within the chord
uint8_t current_harp_notes[12];                  // the array for the note calculation within the string

//>>SWITCHING LOGIC GLOBAL VARIABLES<<
int8_t current_line = -1;      // holds the current selected line of button, -1 if nothing is on
int8_t fundamental = 0;        // holds the value of the last selected line, hence the fundamental
uint8_t slash_value = 0;       // stores the "slash", ie when a different alternative note is selected
bool slash_chord = false;      // flag for when a slashed chord is currently activated
bool button_pushed = false;    // flag for when any button has been pushed during the main loop
bool trigger_chord = false;    // flag to trigger the enveloppe of the chord
bool sharp_active = false;     // flag for when the sharp is active
bool flat_button_modifier= false; //flag to set the modifier to flat instead of sharp
bool continuous_chord = false; // wether the chord is held continuously. Controlled by the "hold" button
bool rythm_mode = false;
bool barry_harris_mode = false;
IntervalTimer note_timer[4]; // timers for delayed chord enveloppe
// Whether each chord voice has been released since its last note on. A release
// has to reach a voice in whatever stage it is in, not only once it has
// settled into sustain, and remembering that it was sent lets the loop, which
// runs the check every pass, send it once.
volatile bool chord_voice_released[4] = {true, true, true, true};
bool inhibit_button=false;

//>>SWITCHING LOGIC PARAMETERS<<
uint8_t note_slash_level = 0;     // the level we are replacing in the chord when slashing (usually the fundamental)
bool retrigger_chord = true;      // wether or not to retrigger the enveloppe when the chord is switched within current line (including when selecting slash chord)
bool change_held_strings = false; // to control wether hold strings change with chord:
bool chromatic_harp_mode = false; // to switch the harp to chromatic mode
//>>SYSEX PARAMETERS<<
// SYSEX midi message are used to control up to 256 synthesis parameters.
const uint16_t parameter_size = 256;
const uint8_t preset_number = 12;
int16_t default_bank_sysex_parameters[preset_number][parameter_size] = {
  {0,0,50,50,512,512,512,0,0,0,192,100,49,100,184,100,157,100,0,0,0,0,0,0,43,0,50,37,38,67,0,0,0,0,0,0,0,0,0,0,0,16,0,8,8,12,42,1171,1,423,20,70,3,35,83,59,2658,1,0,0,0,0,0,0,0,1,1,1,100,1,1,0,1,1,1,1,14,0,0,70,0,0,0,100,0,6,0,0,755,195,23,61,29,0,0,0,0,162,0,2,0,0,0,0,0,0,0,0,0,0,0,0,0,0,0,0,0,0,0,0,2,13,8,100,16,0,200,0,0,50,0,50,18,32,50,0,0,10,66,353,65,995,1,569,16,141,32,83,28,48,54,1,0,0,0,56,0,389,0,20,0,0,0,0,1,1,1,0,1,1,0,1,1,1,1,0,0,0,70,0,0,0,100,0,64,0,0,80,16,4,94,753,474,70,5,100,100,100,2,0,0,0,0,0,0,0,0,0,0,0,0,0,0,0,0,0,0,0,0,0,16,0,6,6,32,0,6,0,16,0,6,6,32,0,6,0,0,0,0,0,0,0,0,0,0,0,0,0,0,0,0,0,0,0,0,0},
  {0,0,50,50,512,512,512,0,0,0,194,100,85,100,60,100,61,100,0,0,10,1,0,0,0,0,0,0,0,100,0,0,0,0,0,0,0,0,0,0,4,25,8,3,29,18,65,488,3,159,25,70,5,18,4,26,6,1,77,0,587,32,0,390,0,76,1,1,100,1,1,68,17,14,22,20,0,340,1682,70,48,0,0,100,18,54,0,0,800,70,57,100,100,0,0,0,0,199,0,2,0,0,0,0,0,0,0,0,0,0,0,0,0,0,0,0,0,0,0,0,4,7,0,100,0,0,100,6,8,200,2,50,36,75,50,28,0,3,1,1,80,1218,2,1659,38,114,19,8,32,80,1,1,0,30,0,0,0,0,0,0,0,24,0,3,1,1,1,100,1,1,100,1,1,1,1,31,0,0,70,0,0,0,100,0,33,2,1,162,16,4,100,100,1436,118,100,50,32,107,2,0,0,0,0,0,0,0,0,0,0,0,0,0,0,0,0,0,0,0,0,0,7,0,0,0,13,0,4,0,7,0,0,2,13,0,0,2,0,0,0,0,0,0,0,0,0,0,0,0,0,0,0,0,0,0,0,0},
  {0,0,50,50,512,512,512,0,0,0,192,100,49,100,184,100,157,100,0,0,30,0,1,1,87,33,62,12,80,67,0,0,0,0,0,0,0,0,0,0,0,6,3,8,8,12,42,1855,1,42,20,217,3,35,83,59,2658,1,185,0,282,14,0,247,11,1,1,1,100,1,1,0,1,1,1,1,14,0,0,70,0,0,0,100,0,23,0,0,755,195,82,61,29,0,0,0,0,162,0,2,0,0,0,0,0,0,0,0,0,0,0,0,0,0,0,0,0,0,0,0,1,13,0,100,23,8,200,0,0,50,0,50,18,32,50,0,0,10,66,353,44,1452,1,569,16,141,32,83,28,48,54,1,0,698,82,56,0,579,0,28,0,0,0,0,1,1,1,0,1,1,100,1,1,1,1,0,0,0,70,0,0,0,100,0,100,0,0,80,16,4,94,753,474,70,5,100,100,100,2,0,0,0,0,0,0,0,0,0,0,0,0,0,0,0,0,0,0,0,0,0,16,0,6,6,32,0,6,0,16,0,6,6,32,0,6,0,0,0,0,0,0,0,0,0,0,0,0,0,0,0,0,0,0,0,0,0},
  {0,0,50,50,512,512,512,0,0,0,196,76,92,100,184,100,85,100,0,0,60,0,1,0,14,0,0,0,42,46,0,0,0,0,0,0,0,0,0,0,3,10,8,11,42,30,61,2137,1,106,22,140,4,35,83,24,1956,1,139,0,282,0,0,247,10,1,1,1,100,1,1,0,1,1,1,1,0,0,0,70,0,0,0,100,0,57,0,1,858,70,66,100,100,0,0,0,0,127,0,2,0,0,0,0,0,0,0,0,0,0,0,0,0,0,0,0,0,0,0,0,0,17,8,200,11,0,134,10,0,100,7,50,59,15,50,0,15,10,10,45,61,1489,1,652,16,84,32,21,15,33,19,1,0,490,0,109,0,252,0,8,0,244,1,49,1,1,1,15,1,1,100,1,1,1,1,26,479,1931,70,0,50,0,100,40,78,21,0,162,16,4,100,1000,639,140,100,47,100,85,2,0,0,0,0,0,0,0,0,0,0,0,0,0,0,0,0,0,0,0,0,0,65,0,12,0,0,12,0,0,65,0,6,0,0,6,0,0,0,0,0,0,0,0,0,0,0,0,0,0,0,0,0,0,0,0,0,0},
  {0,0,50,50,512,512,512,0,0,0,146,100,76,100,85,79,184,100,0,0,110,0,0,0,57,0,0,0,67,58,0,0,0,0,0,0,0,0,0,0,0,6,8,8,65,12,38,1855,5,57,24,152,3,35,83,59,2658,6,137,0,640,8,0,247,11,1,1,1,100,1,1,131,4,116,3,1,11,424,1360,70,46,0,0,100,60,85,0,0,996,125,82,61,71,0,0,0,0,90,0,2,0,0,0,0,0,0,0,0,0,0,0,0,0,0,0,0,0,0,0,0,0,20,0,100,23,0,200,15,8,100,0,50,0,18,50,0,0,2,293,17,44,1012,1,10,33,141,32,83,28,67,239,1,0,0,0,287,0,579,0,0,0,366,0,35,5,52,12,0,1,1,100,1,1,1,1,16,0,0,70,0,0,0,100,0,50,0,0,184,16,4,100,100,657,70,86,100,100,95,2,0,0,0,0,0,0,0,0,0,0,0,0,0,0,0,0,0,0,0,0,0,7,0,0,2,4,2,15,0,2,2,6,2,6,15,0,0,0,0,0,0,0,0,0,0,0,0,0,0,0,0,0,0,0,0,0,0},
  {0,0,50,50,512,512,512,0,0,0,192,60,47,56,159,100,157,100,0,0,138,1,0,0,0,0,0,0,27,74,0,0,0,0,0,0,0,0,0,0,4,14,11,3,29,18,65,1102,3,302,11,70,5,18,4,26,6,1,38,0,516,16,0,0,0,76,1,1,100,1,1,68,17,14,22,20,0,340,1682,70,48,0,0,100,18,58,0,0,800,70,43,100,100,0,0,0,0,200,0,2,0,0,0,0,0,0,0,0,0,0,0,0,0,0,0,0,0,0,0,0,4,10,11,100,9,0,200,4,8,200,0,50,36,75,50,0,0,3,1,1,80,1855,2,769,15,114,19,8,32,80,1,1,0,30,0,11,0,467,0,35,0,24,0,3,1,1,1,100,1,1,100,1,1,1,1,0,341,2164,70,54,0,0,100,36,42,0,1,80,16,4,100,20,2101,70,100,6,22,55,2,0,0,0,0,0,0,0,0,0,0,0,0,0,0,0,0,0,0,0,0,0,1,2,4,8,17,0,12,0,1,2,4,8,16,6,0,1,0,0,0,0,0,0,0,0,0,0,0,0,0,0,0,0,0,0,0,0},
  {0,0,50,50,512,512,512,0,0,0,192,100,61,100,130,100,83,100,0,0,175,0,0,0,0,0,0,0,0,35,0,0,0,0,0,0,0,0,0,0,0,12,9,11,1,1,70,2141,1,383,17,302,101,103,34,30,1,12,0,0,367,17,0,363,5,1,1,1,86,1,1,0,1,1,1,1,8,0,0,70,0,0,0,100,0,33,50,0,5000,70,100,0,0,0,0,0,0,90,0,2,0,0,0,0,0,0,0,0,0,0,0,0,0,0,0,0,0,0,0,0,5,9,9,200,13,6,99,6,0,50,27,50,50,50,50,0,0,345,1,1,80,800,32,2200,0,70,1,1,1,100,1,1,0,30,0,0,0,166,0,6,0,0,0,0,1,1,1,0,1,1,100,1,1,1,1,0,0,0,70,0,0,0,100,0,59,100,0,80,16,4,100,100,2366,70,100,40,23,57,2,0,0,0,0,0,0,0,0,0,0,0,0,0,0,0,0,0,0,0,0,0,1,0,4,4,16,16,12,0,1,6,8,6,0,6,0,1,0,0,0,0,0,0,0,0,0,0,0,0,0,0,0,0,0,0,0,0},
  {0,0,50,50,512,512,512,0,0,0,146,100,76,100,85,79,184,100,0,0,220,0,0,0,0,0,0,86,55,63,0,0,0,0,0,0,0,0,0,0,0,6,8,8,65,12,38,1855,5,57,24,152,3,35,83,59,2658,6,137,0,640,8,0,247,11,1,1,1,100,1,1,131,4,116,3,1,11,424,1360,70,46,0,0,100,60,84,0,0,996,125,82,61,71,0,0,0,0,90,0,2,0,0,0,0,0,0,0,0,0,0,0,0,0,0,0,0,0,0,0,0,0,20,0,100,23,0,200,15,8,100,0,50,0,18,50,0,0,2,293,17,44,1012,1,10,33,141,32,83,28,67,239,1,0,0,0,287,0,579,0,0,0,366,0,35,5,52,12,0,1,1,100,1,1,1,1,16,0,0,70,0,0,0,100,0,50,0,0,184,16,4,100,100,657,70,86,100,100,95,2,0,0,0,0,0,0,0,0,0,0,0,0,0,0,0,0,0,0,0,0,0,7,0,0,2,4,2,15,0,2,2,6,2,6,15,0,0,0,0,0,0,0,0,0,0,0,0,0,0,0,0,0,0,0,0,0,0},
  {0,0,50,50,512,512,512,0,0,0,196,100,47,56,159,100,157,100,0,0,253,1,0,0,0,0,0,0,0,59,0,0,0,0,0,0,0,0,0,0,4,15,11,3,29,18,65,1102,3,302,11,70,5,18,4,26,6,1,38,0,516,16,0,0,12,76,1,22,100,1,1,68,17,14,22,20,0,340,1682,70,48,0,0,100,18,58,0,0,800,70,43,100,100,0,0,0,0,158,0,2,0,0,0,0,0,0,0,0,0,0,0,0,0,0,0,0,0,0,0,0,4,10,0,100,9,0,200,4,8,200,0,50,36,75,50,0,0,3,1,1,80,1855,2,769,15,114,19,8,32,80,1,1,0,30,0,11,0,467,0,22,0,24,0,3,1,1,1,100,1,1,100,1,1,1,1,0,341,2164,70,54,0,0,100,36,42,0,1,80,16,4,100,20,532,70,100,6,82,96,2,0,0,0,0,0,0,0,0,0,0,0,0,0,0,0,0,0,0,0,0,0,1,2,4,8,17,0,12,0,1,2,4,8,16,6,0,1,0,0,0,0,0,0,0,0,0,0,0,0,0,0,0,0,0,0,0,0},
  {0,0,50,50,512,512,512,0,0,0,149,69,76,100,85,79,184,100,0,0,266,0,0,0,0,0,0,0,65,70,0,0,0,0,0,0,0,0,0,0,0,5,0,8,65,12,38,1855,5,57,24,152,3,35,83,59,2658,6,137,0,640,8,0,247,11,1,1,1,100,1,1,131,4,116,3,1,0,424,1360,70,46,0,0,100,60,81,0,0,996,125,82,61,71,0,0,0,0,108,0,2,0,0,0,0,0,0,0,0,0,0,0,0,0,0,0,0,0,0,0,0,1,20,12,100,23,0,200,15,8,100,0,50,45,17,0,0,0,2,293,17,44,1012,1,10,33,141,32,83,28,67,239,1,0,0,0,287,0,579,0,0,0,366,0,35,5,52,12,0,1,1,100,1,1,1,1,16,0,0,70,0,0,0,100,0,50,0,0,184,16,4,100,100,857,70,42,100,100,158,2,0,0,0,0,0,0,0,0,0,0,0,0,0,0,0,0,0,0,0,0,0,7,0,0,2,4,2,15,0,2,2,6,2,6,15,0,0,0,0,0,0,0,0,0,0,0,0,0,0,0,0,0,0,0,0,0,0},
  {0,0,50,50,512,512,512,0,0,0,192,55,61,100,184,100,85,100,0,0,310,0,0,0,86,0,56,87,37,60,0,0,0,0,0,0,0,0,0,0,4,15,12,36,42,30,59,1410,1,30,33,140,4,35,83,24,615,1,94,0,282,15,0,247,0,1,1,1,100,1,1,0,1,1,1,1,0,0,0,70,0,0,0,100,0,40,0,1,858,70,46,100,82,0,0,0,0,124,0,2,0,0,0,0,0,0,0,0,0,0,0,0,0,0,0,0,0,0,0,0,1,16,8,200,18,0,134,21,0,200,2,50,59,15,50,18,15,10,66,43,35,711,1,271,16,84,32,83,733,31,54,1,0,698,0,220,0,252,0,8,0,244,1,49,1,1,1,15,1,1,100,1,1,1,1,26,479,1931,70,0,50,0,100,34,75,0,0,162,16,4,100,1000,1889,116,49,100,42,129,2,0,0,0,0,0,0,0,0,0,0,0,0,0,0,0,0,0,0,0,0,0,65,0,12,0,0,12,0,0,65,0,6,0,0,6,0,0,0,0,0,0,0,0,0,0,0,0,0,0,0,0,0,0,0,0,0,0},
  {0,0,50,50,512,512,512,0,0,0,194,100,85,100,60,100,61,100,0,0,340,1,0,0,0,0,0,0,0,62,0,0,0,0,0,0,0,0,0,0,4,25,3,3,29,18,65,488,3,159,25,70,5,18,4,26,40,1,77,0,587,32,0,715,11,76,1,1,100,1,1,68,17,14,22,20,17,340,1682,70,48,0,0,100,18,54,0,0,800,70,57,100,100,0,0,0,0,199,0,2,0,0,0,0,0,0,0,0,0,0,0,0,0,0,0,0,0,0,0,0,1,3,1,100,0,0,100,6,8,200,2,50,36,75,50,28,0,3,1,1,80,1218,2,706,38,114,19,8,32,80,1,1,0,30,0,0,0,0,0,0,0,24,0,3,1,1,1,100,1,1,100,1,1,1,1,31,0,0,70,0,0,0,100,0,33,2,1,162,16,4,100,100,678,118,100,50,32,168,2,0,0,0,0,0,0,0,0,0,0,0,0,0,0,0,0,0,0,0,0,0,7,0,0,0,13,0,4,0,7,0,0,2,13,0,0,2,0,0,0,0,0,0,0,0,0,0,0,0,0,0,0,0,0,0,0,0}
}; 
int16_t current_sysex_parameters[parameter_size] = {0,0,50,50,512,512,512,1,0,0,192,100,49,100,184,100,157,100,0,0,0,0,0,0,0,0,0,0,0,67,0,0,0,0,0,0,0,0,0,0,0,16,0,8,8,12,42,1171,1,423,20,70,3,35,83,59,2658,1,0,0,0,0,0,0,0,1,1,1,100,1,1,0,1,1,1,1,14,0,0,70,0,0,0,100,0,6,0,0,755,195,23,61,29,0,0,0,0,162,0,0,0,0,0,0,0,0,0,0,0,0,0,0,0,0,0,0,0,0,0,0,2,13,8,100,16,0,200,0,0,50,0,50,18,32,50,0,0,10,66,353,65,995,1,569,16,141,32,83,28,48,54,1,0,0,0,56,0,389,0,20,0,0,0,0,1,1,1,0,1,1,0,1,1,1,1,0,0,0,70,0,0,0,100,0,38,0,0,80,16,4,94,753,474,70,5,100,100,100,0,0,0,0,0,0,0,0,0,0,0,0,0,0,0,0,0,0,0,0,0,0,16,0,6,6,32,0,6,0,16,0,6,6,32,0,6,0,0,0,0,0,0,0,0,0,0,0,0,0,0,0,0,0,0,0,0,0};
const char *bank_name[preset_number] = {"a.txt", "b.txt", "c.txt", "d.txt", "e.txt", "f.txt", "g.txt", "h.txt", "i.txt", "j.txt", "k.txt", "l.txt"};
int8_t current_bank_number = 0;
float bank_led_hue = 0;
// Reserved SYSEX adresses
// =0 is for the control command
// 1 is the bank ID
// >2 and <10 are protected
int8_t harp_volume_sysex = 2;
int8_t chord_volume_sysex = 3;
int8_t chord_pot_alternate_storage = 4;
int8_t harp_pot_alternate_storage = 5;
int8_t mod_pot_alternate_storage = 6;

// >10 and <21 are limited access, for example the potentiometer settings (we don't want a pot to control another pot sysex adress or range)
int8_t chord_pot_alternate_control = 10;
int8_t chord_pot_alternate_range = 11;
int8_t harp_pot_alternate_control = 12;
int8_t harp_pot_alternate_range = 13;
int8_t mod_pot_main_control = 14;
int8_t mod_pot_main_range = 15;
int8_t mod_pot_alternate_control = 16;
int8_t mod_pot_alternate_range = 17;
// 21-39 are global parameters (switching logic, global reverb etc.)
// 40-119 are harp parameters
// 120-219 are chord parameters
// 220-235 are rythm patterns
bool sysex_controler_connected=false; //bool to remember if there is a controller that is connected to avoid saving any change
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
void loop() {
  // Process incoming MIDI messages
  if (usbMIDI.read()) {
    processMIDI();
  }
  // Check sysex controller connection
  if (sysex_controler_connected && bitRead(USB1_PORTSC1, 7)) {
    sysex_controler_connected = false;
  }

  // Update debouncers
  hold_button.set(digitalRead(HOLD_BUTTON_PIN));
  up_button.set(digitalRead(UP_PGM_PIN));
  down_button.set(digitalRead(DOWN_PGM_PIN));
  LBO_flag.set(digitalRead(BATT_LBO_PIN));
  chord_matrix.update(chord_matrix_array);

  // Handle low battery indicator
  handle_low_battery();

  // Handle hold button for mode switching and rhythm
  handle_hold_button();

  // Handle preset changes
  handle_preset_change();

  // Handle rhythm mode note-off timing
  if (rythm_mode) {
    handle_rhythm_mode();
  }

  // Handle potentiometer updates
  bool alternate = chord_matrix_array[0].read_value();
  flag_save_needed |= chord_pot.update_parameter(alternate);
  flag_save_needed |= harp_pot.update_parameter(alternate);
  flag_save_needed |= mod_pot.update_parameter(alternate);

  // Handle continuous mode logic
  if (!continuous_chord && !rythm_mode) {
    handle_continuous_mode();
  }

  // Handle chord logic
  if (current_line >= 0) {
    fundamental = current_line;
    detect_slash();
    bool button_maj = chord_matrix_array[1 + current_line * 3].read_value();
    bool button_min = chord_matrix_array[2 + current_line * 3].read_value();
    bool button_seventh = chord_matrix_array[3 + current_line * 3].read_value();
    handle_chord_type(button_maj, button_min, button_seventh);
    update_chord_notes(); // Replaced updateNotes() with update_chord_notes()
    update_harp_notes();  // Added call to update_harp_notes()
    trigger_chord_notes();
  }

  // Handle chord button transitions
  handle_chords_button();

  // Handle harp functions
  handle_harp();

  // The only point at which this firmware transmits MIDI. Must stay last, and must
  // stay in loop() -- see the MIDI OUTPUT QUEUE comment above.
  drain_midi_queue();
}

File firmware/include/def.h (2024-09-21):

//Audio Hardware
#define _MUTE_PIN 3

//Leds
#define RYTHM_LED_PIN 12
#define R_LED_PIN 0
#define G_LED_PIN 1
#define B_LED_PIN 2

//Shift register
#define SHIFT_DATA_PIN 13
#define SHIFT_STORAGE_CLOCK_PIN 14
#define SHIFT_CLOCK_PIN 15

//Buttons
#define READ_MATRIX_1_PIN 6
#define READ_MATRIX_2_PIN 5
#define READ_MATRIX_3_PIN 4

#define DOWN_PGM_PIN 8
#define UP_PGM_PIN 9

#define HOLD_BUTTON_PIN 11

//Potentiometers
#define POT_CHORD_PIN 16
#define POT_HARP_PIN 17
#define POT_MOD_PIN 22

//Battery management
#define BATT_LBO_PIN 10

//Capacitive touch
#define CAP_SDA_PIN 18
#define CAP_SDL_PIN 19

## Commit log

2024-08-28 Almost fixed for responsive, except the code schematics that won't overflow
2024-09-04 A few modification, plus hopefully fixing the synthesis schematics
2024-09-08 A lot of temporal ressources for the assembly guide
    [BOM_SMD.csv]
2024-09-08 All ressources
    [BOM_SMD.csv]
2024-09-13 Worked on the assembly page
2024-09-13 Added BOM
    [full_BOM.csv]
2024-09-28 cleaned the project and fixed a nasty bug in the envelope section
    [main.cpp]
2024-10-01 Smoother volume control and added separate pitch bend/vibrato control
    [main.cpp]
2024-10-04 fixed a bug with regard to delayed chord notes
    [main.cpp]
2024-10-04 fixed the "three key" bug, linked to the absence of diodes in the matrix
    [main.cpp]
2024-10-26 Started github doc
    [full_BOM.csv]
2024-10-26 Finished assembly
2024-11-17 Added detail on how to insert the screws
2024-12-01 Added basic MIDI support, with independant port for each instrument Currently the minichord displays 16 channels, need to get that down to the two used to avoid creating confusion. Better documentati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
    [main.cpp]
2024-12-07 Update to avoid sound break when switching presets
    [main.cpp]
2024-12-15 A few things: - compiled the firmware to show only two midi outputs and explained how to do it- Updated both the code and doc to move to the circle of fifth. The gen script was also modified to use a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
    [MiniChord-CuBottom.gbr, MiniChord-CuIn1.gbr, MiniChord-CuIn2.gbr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]
2024-12-18 Added full 3D modelisation
    [all_parts.FCStd, all_parts_exploded.FCStd, battery.dxf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]
2024-12-21 Added a few 3D files, and update the README
    [all_parts.FCStd, all_parts_exploded.FCStd]
2025-10-10 Deleted multi port logic and removed USB audio, as those might confuse hardware devices.
2025-10-13 Add comprehensive unit testing infrastructure
    Implements unit testing framework for firmware with 15 passing tests covering
    core musical logic and parameter handling.
    Testing Infrastructure:
    - PlatformIO native test environment configuration
    - Unity test framework integration
    - GitHub Actions CI workflow for automated testing
    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
2025-10-15 Fix chord logic to match original behavior exactly
    - Added complete get_root_button implementation with key signatures and frame shifts
    - Added original calculate_note_chord and calculate_note_harp functions
    - Updated wrapper functions to use original behavior with default parameters
    - Fixed header file to avoid duplicate definitions
    - All tests now pass with original firmware behavior
    [main.cpp]
2026-01-09 Update of the gerber
    [MiniChord-B_Adhesive.gbr, MiniChord-B_Courtyard.gbr, MiniChord-B_Cu.gbr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]
2026-04-08 Fix for #111 BOM mistake
    [electronics_BOM.csv, full_BOM.csv]
2026-06-03 fix: polyphonic MIDI output for Ableton Move (USB host)
    - Move send_now() out of IntervalTimer ISR context (chord ISR)
    to prevent dropped USB transfers on double-buffer full
    - Add midi_flush_needed flag: flush only when ISR queued a note
    - Cancel pending note timers in stop_chord_notes() to prevent
    orphaned NoteOn after button release
    - Send NoteOff panic on first chord OR harp touch to clear stale
    host state (Move does not reset MIDI on USB disconnect)
    - Separate harp to MIDI channel 2 (chord stays ch1) to avoid
    polyphony conflicts on Move's 16-voice limit
    - Increase midi_buffer_delay 100->300us for USB Full Speed timing
    Tested on Teensy 4.0 with Ableton Move (USB-A host, Full Spee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
    [main.cpp]
2026-06-15 refactor: remove panic routine and restore default harp channel
    Per maintainer feedback:
    - Remove first_play_panic_done: stale-note cleanup on reconnect
    is the host's responsibility, not the controller's
    - Restore harp_channel default to 1 (user-configurable via MiniControl)
    Core fixes retained: send_now() ISR flag, timer cancellation in
    stop_chord_notes(), 300us midi_buffer_delay.
    [main.cpp]
2026-06-22 Reversed port change as settable by minicontrol
    [main.cpp]
2026-09-13 Build the firmware on every pull request
    There is no automated build, so whether a change compiles is only known once
    someone checks out the branch and builds it. With fifteen pull requests open
    that is a per-pull-request cost paid by hand.
    This builds firmware/ for the Teensy on every push and pull request that touches
    it, and keeps the resulting hex as an artifact so a change can be flashed
    without building it locally. The toolchain is cached on the contents of
    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
2026-09-14 Let the chord filter respond while a chord is sounding
    The filter cutoff and keytrack set a variable and nothing else. That variable is
    only read in set_chord_voice_frequency, which runs when a voice starts, so
    sweeping the filter under a held chord does nothing until the chord is played
    again. Terminalwaltz's Jump assigns the chord knob's alternate to the cutoff,
    and it is silent until you retrigger.
    Both cases had a for loop over four voices whose body never used the loop
    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
2026-09-15 Debounce the value, not just the transition
    set() wrote value straight through and only gated read_transition() on the
    debounce period, so read_value() returned the raw pin state and nothing was ever
    held steady.
    That shows wherever a combination is read by value rather than by transition.
    The three chord type buttons do not release in the same instant, so letting go
    of a major seventh reads as a plain major on the way out, and anything
    recalculating in that window picks up the wrong chord.
    value now changes only once the reading has held for the debounce period, and
    the flag is raised then rather than at the raw edge. Transition latency is
    unchanged — the same period, measured from the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
2026-09-15 Add an assignable chord layout
    The three chord buttons give seven combinations and all seven are already
    spoken for, so suspended and extended chords need a second reading of the same
    buttons rather than new buttons.
    Eight more chord tables, a catalogue of all eighteen, and one parameter per
    combination pointing into it. The ninth chords drop their fifth, since there are
    four voices and that is how a player would voice them anyway.
    A slot parameter of 0 gives that slot's default rather than the first catalogue
    entry, so a preset saved before these addresses existed still gives the
    suspended and extended set instead of seven majors.
    Rebased on current main and no longer stacked on the rele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
    [main.cpp]
2026-09-15 Fix controller-connected flag cleared on the same pass it is set
    (USB1_PORTSC1, 7) used the comma operator, so it always evaluated to 7
    and cleared sysex_controler_connected immediately after processMIDI()
    set it. handle_preset_change() therefore always autosaved, even with
    minicontrol connected, writing unsaved controller edits to flash when
    a pot's alternate function had been used.
    Use bitRead(USB1_PORTSC1, 7) so the flag clears when the USB bus
    suspends (PORTSC1 bit 7 = SUSP), matching the original intent.
    [main.cpp]
2026-09-15 Only send the parameter dump when a controller is connected
    load_config() called control_command(0, 0) unconditionally, sending the
    full 512-byte parameter sysex on cable 0 at every boot and preset
    change, whether or not anything was listening. Dumps are normally sent
    on request, and minicontrol already requests one when it connects.
    The unsolicited dump shares the performance port with the chords,
    ties up a DIN link for about 165 ms, lands in DAW recordings, and at
    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
2026-09-22 Bound sysex parameter writes to the parameter array
    processMIDI() treated every six byte system exclusive message as a
    parameter write. The address is data[1] + 128 * data[2], so it can
    reach 16383 while current_sysex_parameters holds 256 entries, and
    nothing checked it. A universal identity request (F0 7E 7F 06 01 F7)
    or a GM system on, both six bytes and both sent unprompted by hosts,
    write about 32 kB past the array.
    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
2026-09-22 Guard the rythm engine against zero divisors
    possible_pattern was declared with four entries and initialised with
    two, and the loop iterates all four, so any cycle length not divisible
    by 3 or 2 executes a modulo by zero in the timer interrupt. It is
    harmless on this core only because a Cortex-M division by zero returns
    0 with the trap bit unset. Size the array to its two entries.
    Clamp cycle length, measure update and default_bpm to their declared
    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
2026-09-24 Release chord voices in any envelope stage, not only sustain
    stop_chord_notes() and the rhythm mode's note off released a voice only
    once it was in sustain, because both run every loop pass and the sustain
    test kept the release from being sent again. A chord let go during its
    attack, hold or decay played that stage out before releasing, so on a
    preset with a long hold the release came seconds after the hand did.
    A per-voice flag now records that a release was sent: set on note on,
    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
2026-09-24 Map only selectors across their declared range
    Every int parameter was treated as discrete, which caught continuous
    quantities stored in whole units: release, attack, the filter
    frequencies, the delay lengths. Factory presets have several of those on
    their alternate knobs, and those knobs would have swept the whole
    declared range instead of the preset's range around its value.
    A selector is now an integer parameter spanning at most
    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
